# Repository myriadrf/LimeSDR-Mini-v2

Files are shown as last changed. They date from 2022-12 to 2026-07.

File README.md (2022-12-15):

# LimeSDR Mini v2

LimeSDR Mini 2.0 is an upgraded, drop-in replacement for LimeSDR Mini, a hardware platform for developing and prototyping high-performance and logic-intensive digital and RF designs that use an FPGA coupled with Lime Microsystems’ LMS7002M RF transceiver.

## Contents

The directory structure is as follows:

      hardware/<version>/
          OutputJobs/            - Output jobs
          PCB/                   - PCB design
          Project Outputs/       - BOM, rule check reports, Gerbers, pick & place files, PDFs
          Schematics/            - Schematic diagrams

## Licensing

The hardware designs are licensed under the Solderpad Hardware License v2.1.

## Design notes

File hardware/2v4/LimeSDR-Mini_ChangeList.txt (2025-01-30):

Changes:

LimeSDR-Mini_2v4_DB_DFMr0:
 - HW_VER changed to 7;
 - Changed VREF source to shunt type
 - LMZ10501 and passive components changed to LMZ20501SILR (same as LimeSDR-Mini_2v2)
 - Fresh DFM files generated

LimeSDR-Mini_2v3_DB_DFMr0:
 - HW_VER changed to 6;
 - Added analog MUX 74LVC1G3157FZ4 for clock source selection
 - LMS_TXNRX2 disconnected from FPGA B6 pin
 - FPGA B6 pin connected to analog mux control CLK_SEL line
 - Switching regulators reverted to LMZ10501 (as in 2v1) due to customer stock
 - Fresh DFM files generated

LimeSDR-Mini_2v2_DB_DFMr1:
 - R71 and R72 moved from mounting hole. 4mm radius of free area is now available from the center of the mounting hole. Only bottom layer contains electrical changes.
 - Assembly top and bottom mechanical layers updated, as well as Mechanical 1 layer.
 - All DFM files generated except BOM, which only changed name from r0 to r1 to correspond the revision.

LimeSDR-Mini_2v2_DB_DFMr0:
 - Older version used as initial version for this revision: LimeSDR-Mini_2v1_DB_DFMr1
 - LMZ10501 and passive components changed to LMZ20501SILR
 - HW version changed to v5
 - PCB changed only in the latter DC-DC converter region only on top layer. Holes are left in the same places
 
 LimeSDR_Mini_2v0:
 - New sheet with RF diagram.
 - Updated diagrams.
 - LMS EEPROM made NF.
 - Changed RF MOSFETs (RF shunt and attenuator).
 - Connected LMS Channel 2 RXes to GND.
 - Connected Edge GPIO pin 5 to VCC5P0 instead of VCC1P8.
 - Changed FPGA from Intel 10M16SAU169C8G to Lattice LFE5U-45F-MG285.
 - Removed 10 pin 0.05" JTAG (Only Edge JTAG left).
 - HW_VER changed to 3.
 - Removed parallel termination resistors (NF) for FT_CLK line.
 - LM75 temperature sensor fit.
 - FPGA I2C EEPROM NF.
 - Added Multi-footprint (SO08N/SO08W/DFN8) FPGA configuration FLASH.
 - Removed angle LED and added TX and RX LEDs. FPGA_GPIO[7:4] are shared with TX and RX LEDs, ca be disconnected by clearing solder bridges JMP1-4.
 - Changed XO from RTX5032A to E7355LF.
 - XO DAC changed from 8 to 10 bit (from DAC5311IDCKR to DAC6311IDCK.
 - Added 16 bit XO VC DAC (NF) and 2,5V reference for XO DAC (NF).
 - Changed clock buffer CLKout2-4 Vddo to 3.3V and optimized power decoupling capacitors.
 - Added new regulator for FPGA core (1.1V).
 - VCC3P3 regulator's EN connected to VCC1P1 PG pin (power sequence).
 - Other cosmetic  changes (sheet orientation, revision, etc).
 - PCB fabrication requirements under FPGA increased: minimal copper width/spacing 3 mil (0.0762 mm), vias under FPGA reduced to 0.3mm ring/0.15mm via. Fabrication requirements for the rest of the PCB left unchanged (copper width/spacing 4mil or 0.1mm; vias 0.4mm ring and 0.2mm hole)
 - Mounting hole added on the SMA connector side
 
LimeSDR_Mini_1v3:
 - Initial version from LimeSDR_Mini_1v2_DB_DFMr2
 - 1.8V and 3.3V rail LDOs changed
 - Capacitors C194 and C195 added for LMS power
 - HW version changed (affects only PCB physical pin connection)
 - BOM version changed (R44 is now fit)
 - Layout improvements (FT connection)

LimeSDR_Mini_1v2_DB_DFMr2:
 - R44 made NF (BOM version)
 - LimeSDR_Mini_1v2_schematic_r2.PDF generated
 - LimeSDR_Mini_1v2_BOMr2.xls updated

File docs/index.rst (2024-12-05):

.. toctree::
   :maxdepth: 2
   :hidden:

   Introduction <self>
   v2.2/index
   v2.3/index
   v2.4/index
   documentation/jtag-programming
   documentation/faq

LimeSDR Mini Boards
===================

LimeSDR Mini is low-cost software defined radio board. LimeSDR Mini development board provides a hardware platform for developing and prototyping high-performance and logic-intensive digital and RF designs based on Lattice Semiconductor’s ECP5 FPGA and Lime Microsystems transceiver.

.. tab:: LimeSDR Mini v2.2

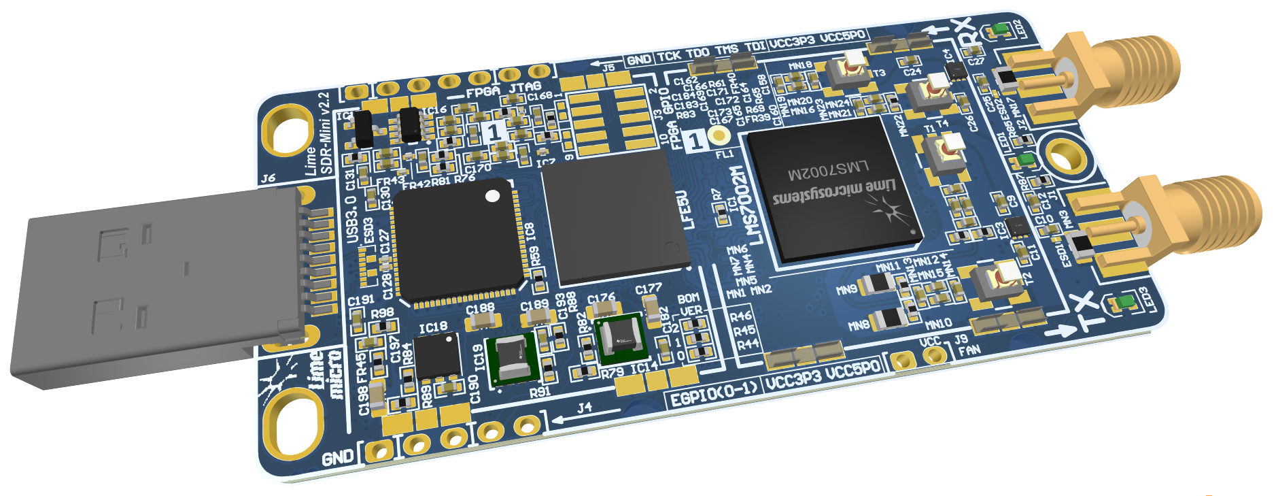
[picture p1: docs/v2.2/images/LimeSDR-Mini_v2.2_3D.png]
   

      Figure 1: LimeSDR Mini v2.2 board

.. tab:: LimeSDR Mini v2.3

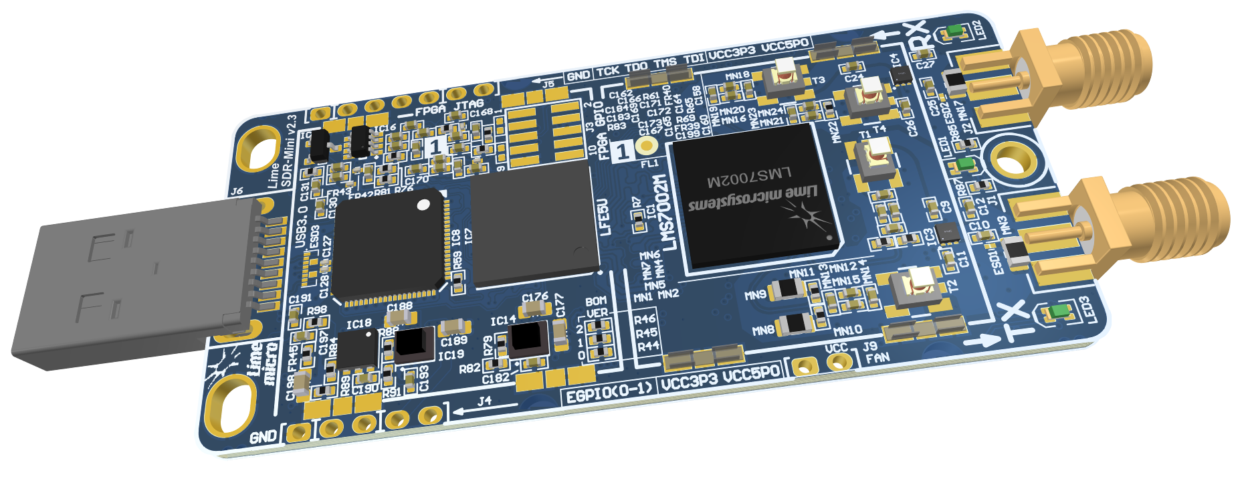
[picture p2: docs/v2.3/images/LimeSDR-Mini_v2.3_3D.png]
   

      Figure 1: LimeSDR Mini v2.3 board

.. tab:: LimeSDR Mini v2.4

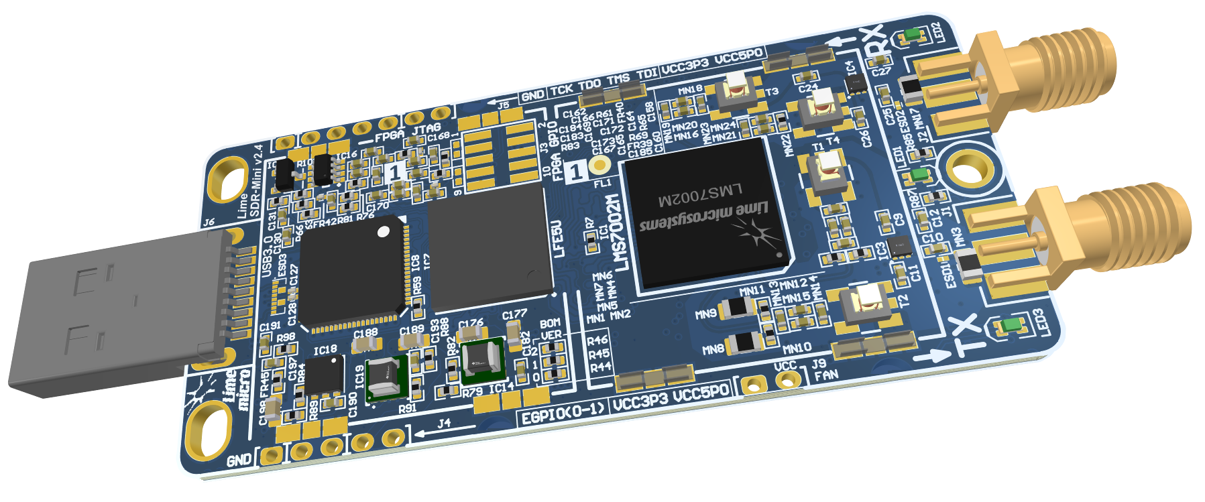
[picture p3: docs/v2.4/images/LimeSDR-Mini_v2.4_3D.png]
   

      Figure 1: LimeSDR Mini v2.4 board

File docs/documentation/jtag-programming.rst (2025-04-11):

.. _target3:

JTAG Programming
================

This section describes how to program the Lattice LFE5U FPGA used on the LimeSDR Mini v2 board using JTAG interface, FT2232H Mini Module and Lattice software.

Used software
-------------

List of used software is given in Table 1.

.. table:: Table 1. Required software and tools

  +------------------------------------------------------------------------------------------------------------------------------------------------+-------------------------------+------------------------------------------------------------------------------------+
  | **Tool**                                                                                                                                       | **Version**                   | **Comment**                                                                        |
  +================================================================================================================================================+===============================+====================================================================================+
  | `Lattice Diamond Programmer 3.12 SP1 <https://www.latticesemi.com/view_document?document_id=53375>`__                                          | 3.12 SP1                      | Standalone programing software for 64-bit Windows OS. Also available for Linux OS. |
  +------------------------------------------------------------------------------------------------------------------------------------------------+-------------------------------+------------------------------------------------------------------------------------+
  | `Lattice Diamond 3.12 <https://www.latticesemi.com/latticediamond>`__                                                                          | Production Build 3.12.0.240.2 | FPGA design and programming software                                               |
  +------------------------------------------------------------------------------------------------------------------------------------------------+-------------------------------+------------------------------------------------------------------------------------+
  | `Lattice Diamond 3.12 SP1 <https://www.latticesemi.com/latticediamond>`__                                                                      | Build 3.12.1.454.2            | Update for Lattice Diamond (Optional)                                              |
  +------------------------------------------------------------------------------------------------------------------------------------------------+-------------------------------+------------------------------------------------------------------------------------+
  | `LatticeMico System for Diamond 3.12 <https://www.latticesemi.com/en/Products/DesignSoftwareAndIP/EmbeddedDesignSoftware/LatticeMicoSystem>`__ | 1.1                           | Mico32 CPU integration tool (Optional)                                             |
  +------------------------------------------------------------------------------------------------------------------------------------------------+-------------------------------+------------------------------------------------------------------------------------+

Connecting LimeSDR Mini v2 board to FT2232H Mini Module
-------------------------------------------------------

FTDI FT2232H Mini Module is available for approximately $20 from distributors like Digi-Key and Mouser, and it can be used directly as a programming adapter for Lattice devices (and others) by following the setup described below. JTAG is a 4-wire protocol defined by the IEEE (Std 1149.1-2013). The signals that comprise the Test Access Port (TAP) are TCK, TMS, TDI, and TDO. The FT2232H is a two port bridge device and either port can be used for JTAG. Our configuration makes use of bus/port A (0).

FT2232H Mini Module preparation:

* Connect CN3-1 to CN3-3, which connects USB VBUS to VCC (voltage regulator input). This can be done using jumper.
* Connect LimeSDR Mini v2 to FT2232H Mini module as specified in Table 2 (see Figure 1 for graphical representation).

.. table:: Table 2. LimeSDR Mini board and FT2232H Mini module connections

  +------------------------------------+---------------------------------+
  | **LimeSDR Mini v2**                | **FT2232H Mini module**         |
  +====================================+=================================+
  | J5-1 (GND)                         | CN2-2 (GND)                     |
  +------------------------------------+---------------------------------+
  | J5-2 (FPGA_JTAG_TCK)               | CN2-7 (AD0)                     |
  +------------------------------------+---------------------------------+
  | J5-3 (FPGA_JTAG_TDO)               | CN2-9 (AD2)                     |
  +------------------------------------+---------------------------------+
  | J5-4 (FPGA_JTAG_TMS)               | CN2-12 (AD3)                    |
  +------------------------------------+---------------------------------+
  | J5-5 (FPGA_JTAG_TDI)               | CN2-10 (AD1)                    |
  +------------------------------------+---------------------------------+
  | J5-6 (VCC3P3)                      | CN2-11 (VIO)                    |
  +------------------------------------+---------------------------------+

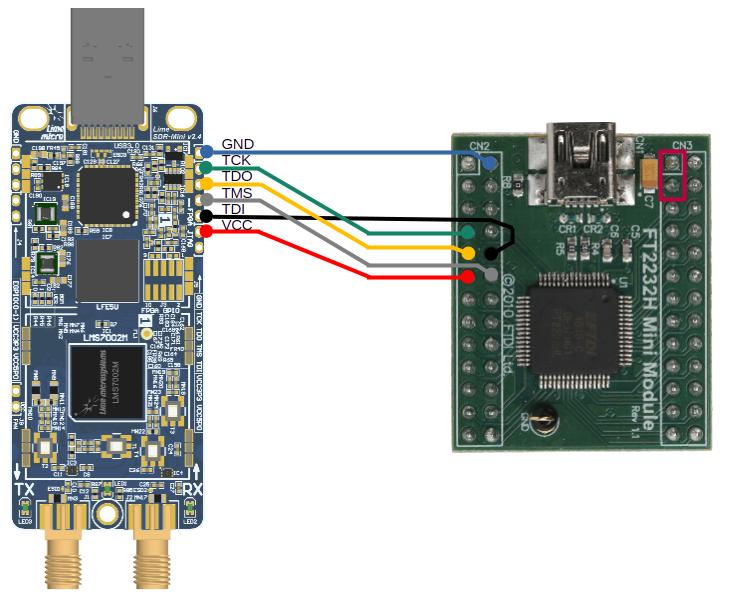
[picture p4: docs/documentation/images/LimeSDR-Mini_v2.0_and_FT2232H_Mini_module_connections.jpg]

  
  Figure 1: LimeSDR Mini v2 board and FT2232H Mini module connections

FPGA programming using Lattice Diamond Programmer software
----------------------------------------------------------

Creating a new project
~~~~~~~~~~~~~~~~~~~~~~

Connect LimesdSDR Mini v2 board to FTDI FT2232H Mini Module as described in paragraph above and connect them to PC via USB ports. Launch software "Lattice Diamond Programmer". Cable HW-USBN-2B (FTDI) and port FTUSB-0 must be selected, as shown in Figure 2.

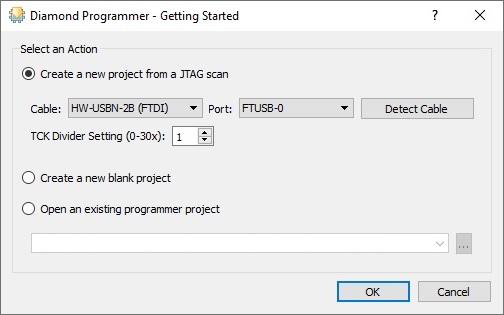
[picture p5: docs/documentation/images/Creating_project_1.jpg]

  
  Figure 2: Cable and port selection

Select an action "Create a new project from JTAG scan" and press "OK" button. Device database loading and JTAG scanning procedures will start, as shown in Figure 3.

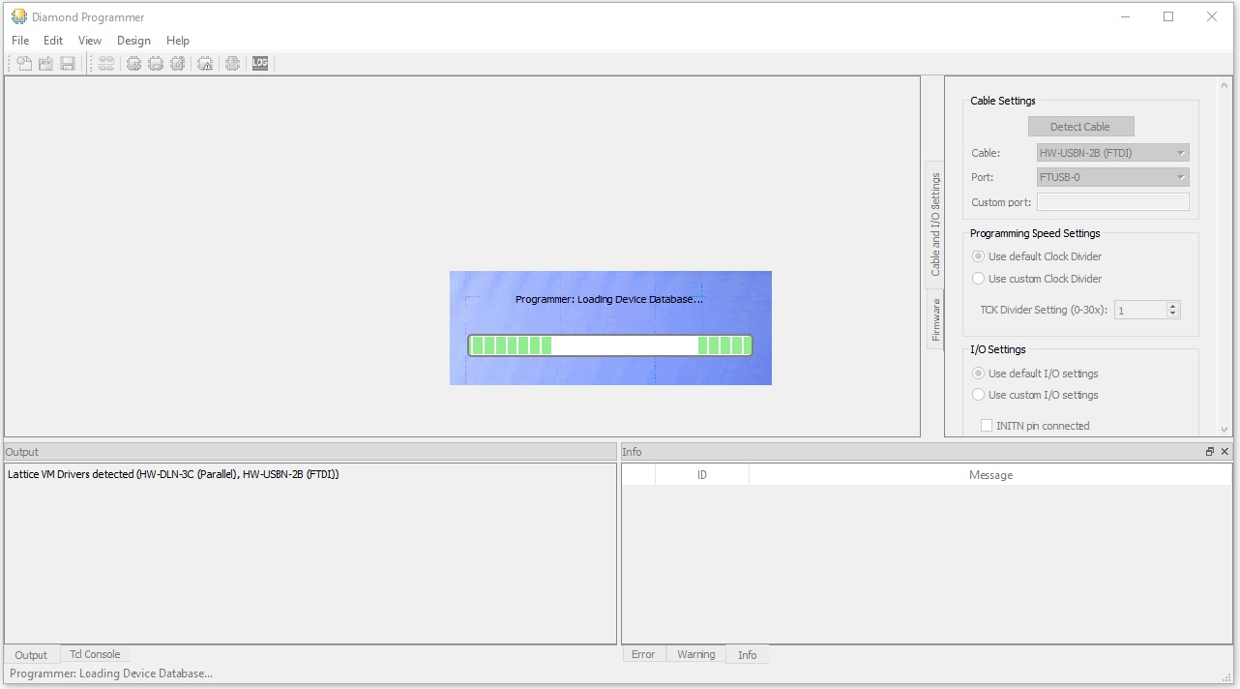
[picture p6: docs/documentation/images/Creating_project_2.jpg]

  
  Figure 3: Device database loading and JTAG scanning procedure

After successful JTAG chain scan ECP5U family FPGA device will be detected (in this case LFE5U-45F), as shown in Figure 4.

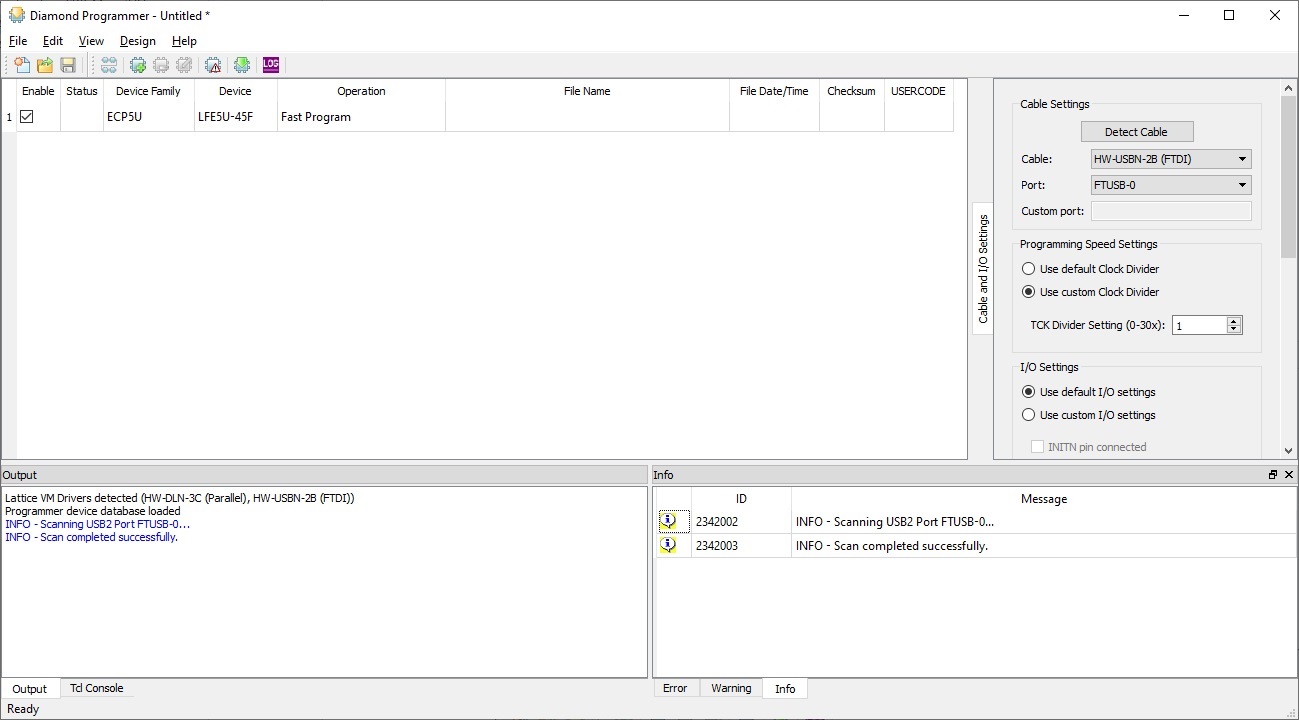
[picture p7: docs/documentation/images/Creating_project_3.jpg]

  
  Figure 4: Detected FPGA device

RAM programming
~~~~~~~~~~~~~~~

In context menu press "Edit -> Device properties" and set device operation parameters as shown in Figure 5. Also load appropriate programming file (gateware, bitstream) and then press "OK".

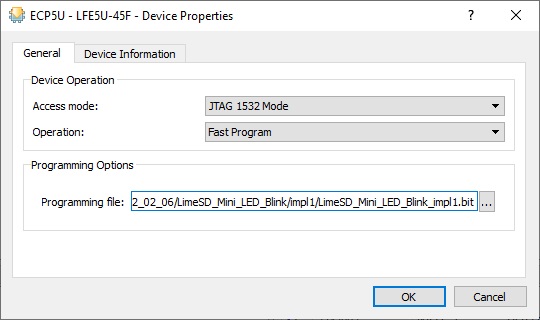
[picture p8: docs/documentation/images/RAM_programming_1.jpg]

  
  Figure 5: Device operation parameters and programming file

The main program window should look as shown in Figure 6.

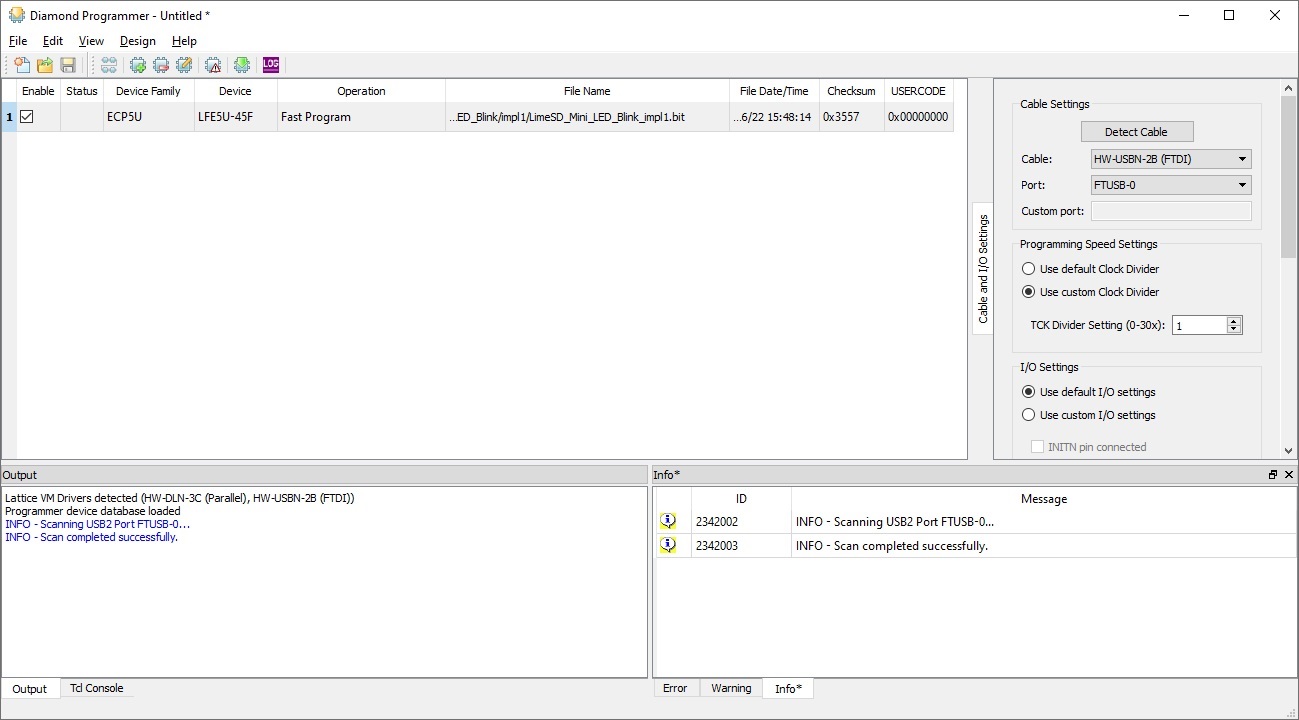
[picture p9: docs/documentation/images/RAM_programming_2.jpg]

  
  Figure 6: Main program window

In context menu press "Design -> Program" and RAM programming procedure will start, as shown in Figure 7.

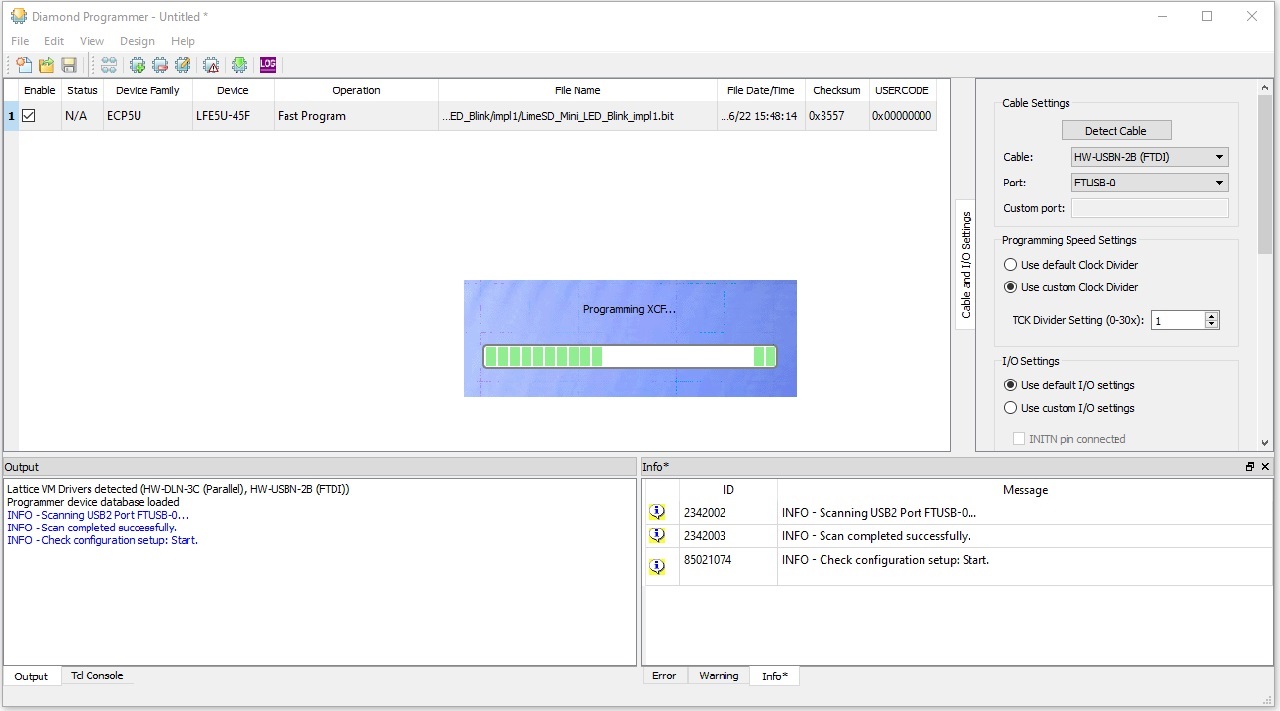
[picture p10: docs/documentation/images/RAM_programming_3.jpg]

  
  Figure 7: Programming procedure

After successful programming operation "Status" field will change to "PASS" highlihted in green as shown in Figure 8 and FPGA will start execution of a new gateware.

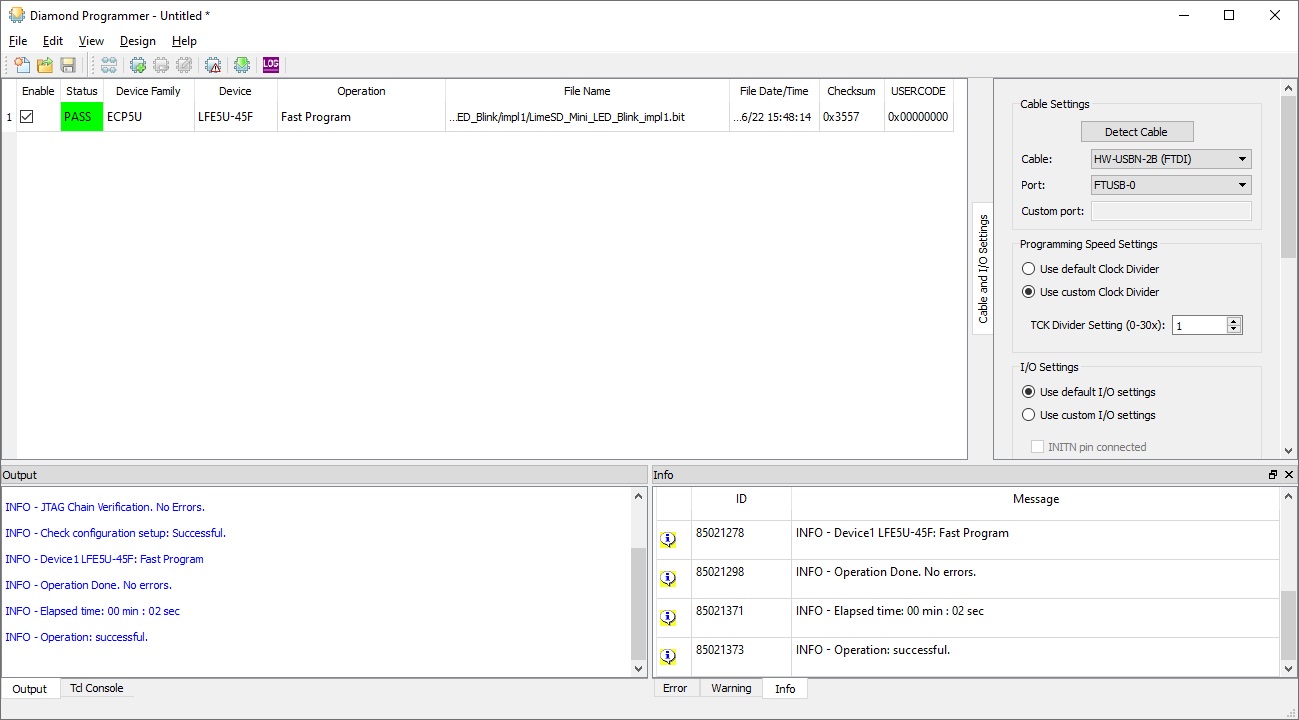
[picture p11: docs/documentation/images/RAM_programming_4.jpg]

  
  Figure 8: Successful programming result

Flash programming
~~~~~~~~~~~~~~~~~

**IMPORTANT!** Backgroud programming has to be enabled first by programming `lms7_trx_preflash_gw.bit <https://github.com/myriadrf/LimeSDR-Mini-v2_GW/blob/main/LimeSDR-Mini_bitstreams/lms7_trx_preflash_gw.bit>`__ file with "RAM programing" procedure.

In context menu press "Edit -> Device properties" and in section "Device Operation" set "Access mode" to "SPI Flash Background Programming" and "Operation" to "SPI Flash Erase,Program,Verify".

Load appropriate programming file (gateware, bitstream) and set the remaining parameters for Winbond W25Q128JV flash memory as shown in the image below and then press "OK".

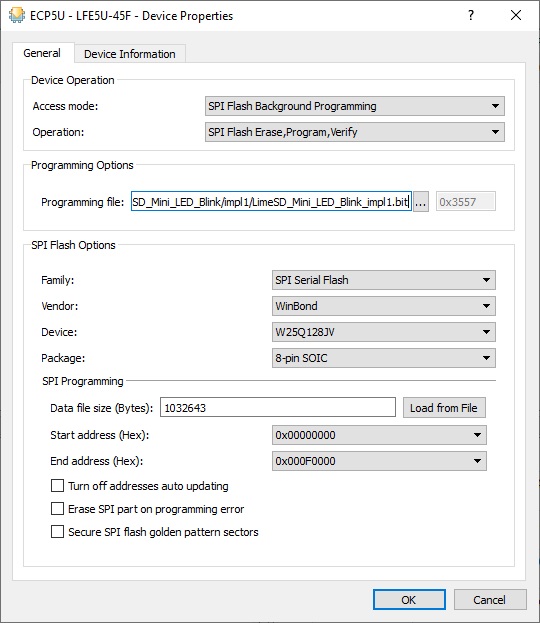
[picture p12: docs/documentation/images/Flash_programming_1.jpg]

  
  Figure 8: LimeSDR Mini v2 board and FT2232H Mini module connections

The main program window should look like shown in figure 9.

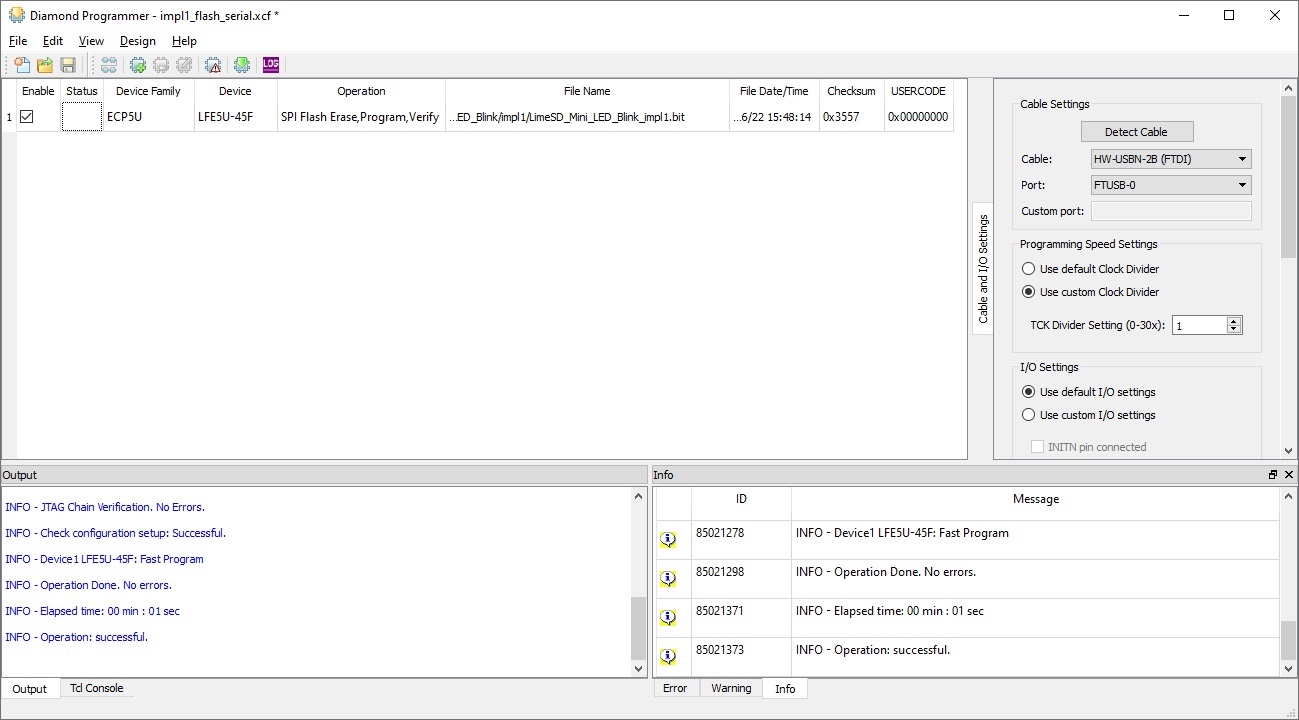
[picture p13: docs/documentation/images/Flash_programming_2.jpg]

  
  Figure 9: Main program window

In context menu press "Design -> Program" and Flash programming procedure will start, as shown in Figure 10.

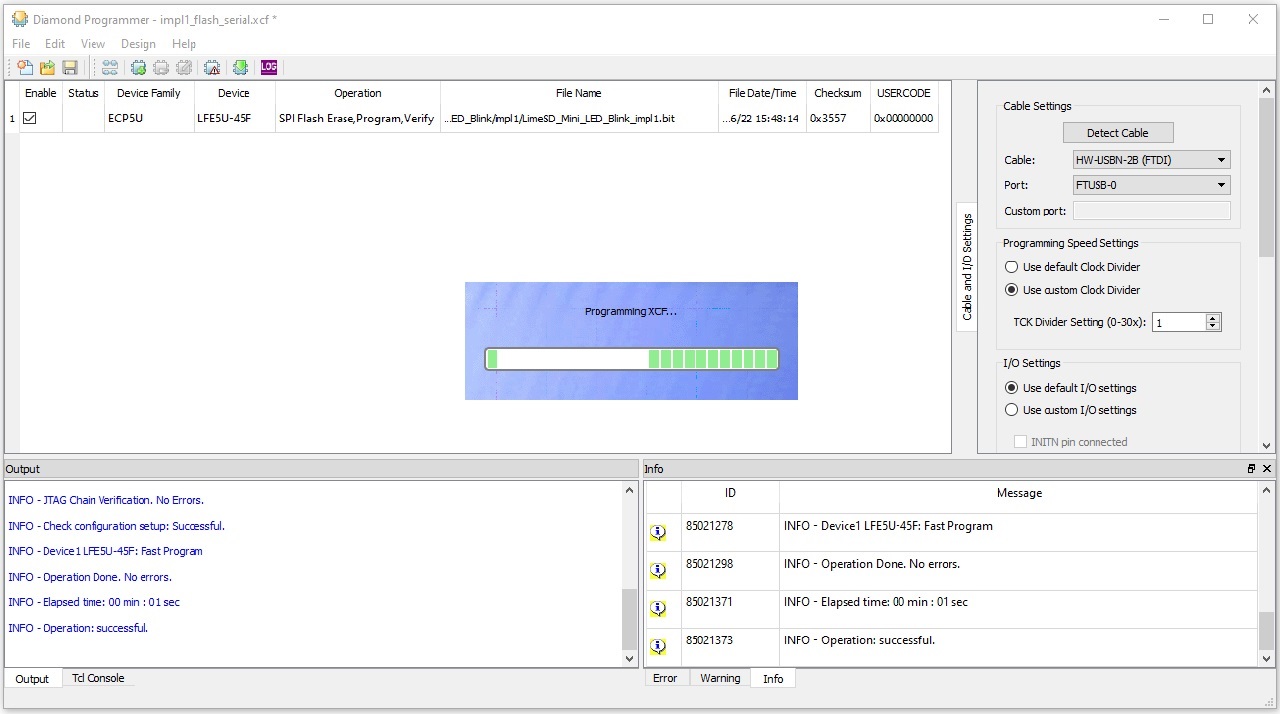
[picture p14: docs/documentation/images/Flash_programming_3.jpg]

  
  Figure 10: Flash in progress

After successful programming operation "Status" field will change to "PASS" highlihted in green as shown in Figure 11 and FPGA will start execution of a new gateware.

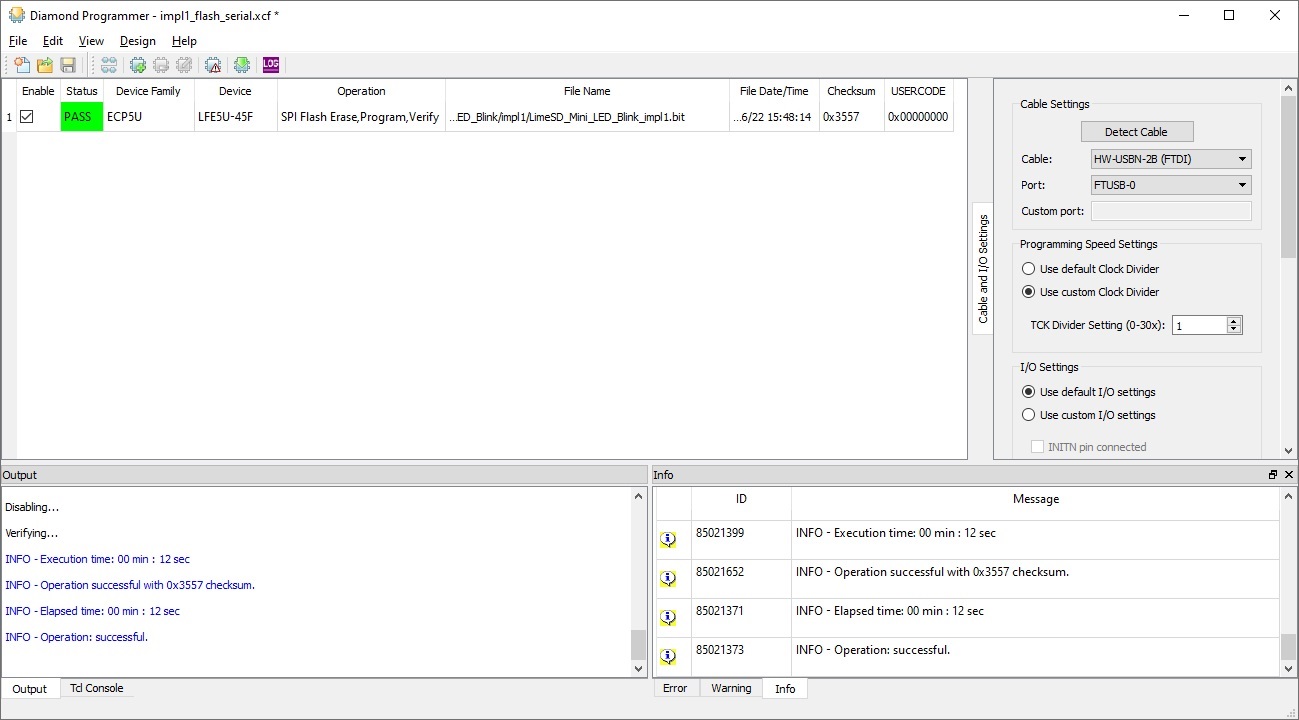
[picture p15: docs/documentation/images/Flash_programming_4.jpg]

  
  Figure 11: Successful programming

You can now save project for future use by selecting menu item "File -> Save".

FPGA programming using Lattice Diamond software
-----------------------------------------------

Open .ldf project File->Open->Project...

**FPGA SRAM programming**

* Open programmer setup file: ./LimeSDR-Mini_bitstreams/impl1_sram.xcf
* Select .bit file : ./LimeSDR-Mini_bitstreams/lms7_trx_impl1.bit
* Click Program.
* You should see blinking LED1 in green colour. 

**FPGA FLASH programming**

First program bitstream file to enable background programming:

* Open programmer setup file: ./LimeSDR-Mini_bitstreams/impl1_sram.xcf
* Select .bit file : ./LimeSDR-Mini_bitstreams/lms7_trx_preflash_gw.bit
* Click Program

Program Flash:

* Open programmer setup file: ./LimeSDR-Mini_bitstreams/impl1_flash_dualboot.xcf
* Select .mcs file : ./LimeSDR-Mini_bitstreams/lms7_trx_impl1_dualboot.mcs
* Click Program
* You should see blinking LED after reapplying power to board

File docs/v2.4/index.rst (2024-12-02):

***********************
LimeSDR Mini v2.4 Board
***********************

Introduction
============

LimeSDR Mini v2.4 Board Key Features
------------------------------------

The LimeSDR-Mini is low-cost software defined radio board. LimeSDR-Mini development board provides a hardware platform for developing and prototyping high-performance and logic-intensive digital and RF designs based on Lattice Semiconductor’s ECP5 FPGA and Lime Microsystems transceiver. 

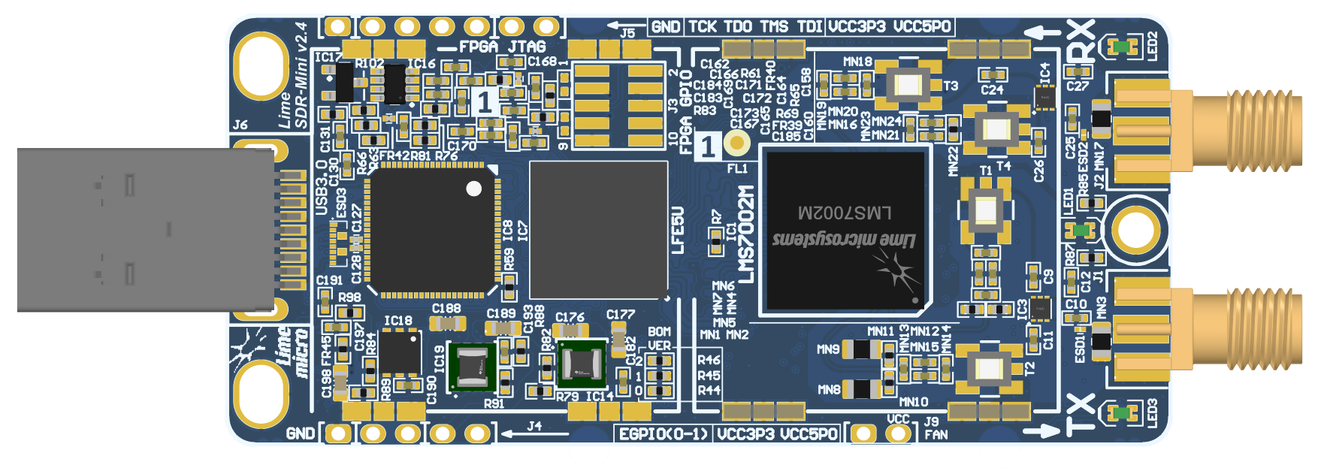
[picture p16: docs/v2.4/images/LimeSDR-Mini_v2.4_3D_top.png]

  
  Figure 1: LimeSDR Mini v2.4 board top view

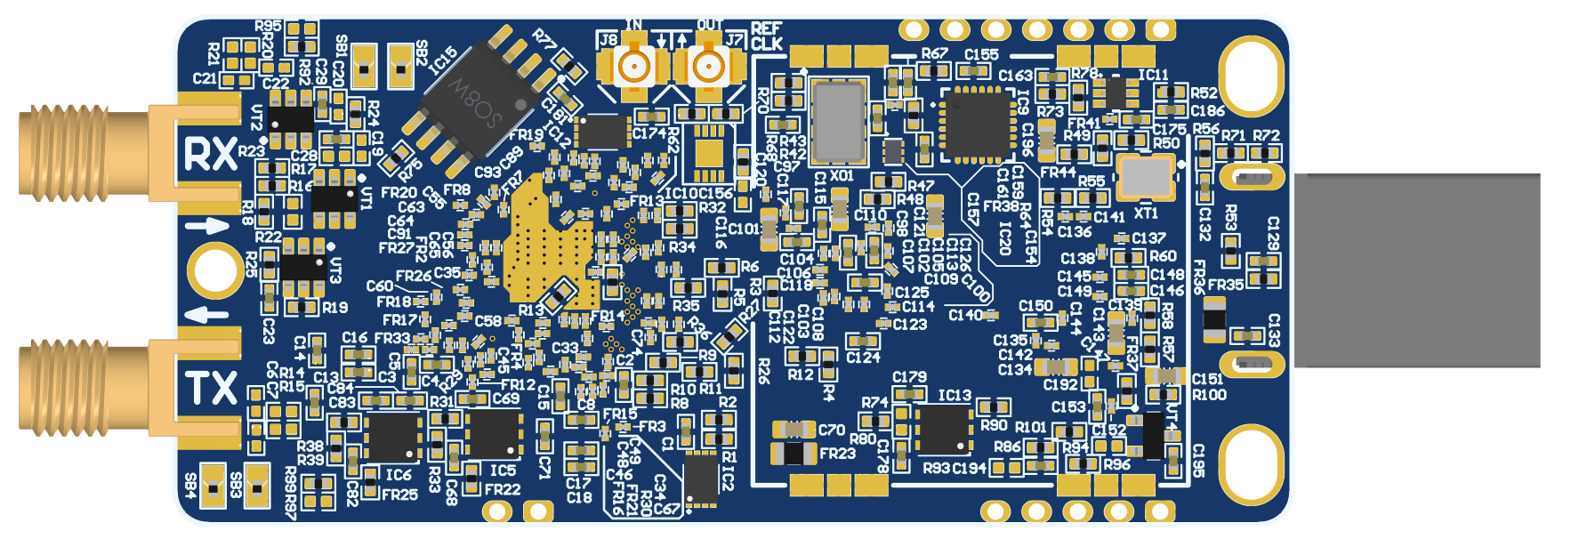
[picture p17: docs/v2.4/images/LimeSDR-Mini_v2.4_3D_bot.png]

  
  Figure 2: LimeSDR Mini v2.4 board bottom view

LimeSDR Mini board features:

* RF and BB parameters:

  * Configuration: SISO (1x TX, 1x RX)
  * Frequency range: 10 MHz – 3.5 GHz
  * Bandwidth: 30.72 MHz
  * Sample depth: 12 bit
  * Sample rate: 30.72 MSPS
  * Transmit power: max 10 dBm (depending on frequency)

* USB 3.0 controller: FTDI FT601

* FPGA: board is designed for Lattice ECP5 family LFE5U-25F/LFE5U-45F/LFE5U-85F FPGAs in 285-ball csfBGA package. By default board is assembled with LFE5U-45F-MG285 FPGA. Lattice ECP5 LFE5U-45F features:

  * 285-pin csfBGA package (10 x 10 mm, 0.5 mm)
  * 44 K LUTs logic capacity
  * 108 sysMEM Blocks (18 Kb)
  * 1944 Kb Embedded Memory
  * 351 Kb distributed RAM
  * 72x 18x18-bit multipliers
  * 4x PLLs and 4x DLLs
  * 118 IOs
  * FPGA configuration via JTAG

* RF transceiver: Lime Microsystems LMS7002M

* EEPROM Memory: 2x 128Kb EEPROMs for LMS MCU firmware and FPGA data (optional)

* FLASH Memory: 128Mb Flash memory for FPGA configuration

* Temperature sensor: LM75

* General user inputs/outputs:

  * 3x Dual colour (RG) LEDs
  * 8x + 2x FPGA GPIO pinheaders (3.3V) (optional)

* Connections:

  * USB 3.0 (type A) plug
  * Coaxial RF (SMA female) connectors
  * FPGA GPIO headers (unpopulated)
  * FPGA JTAG connector (unpopulated)
  * FAN (5V default or 3.3V) connector

* Clock system:

  * 40.00MHz on board VCTCXO
  * VCTCXO can be tuned by onboard DAC
  * Reference clock input and output connectors (U.FL)
  * Analog switch for clock source selection

* Board size: 69mm x 31.4mm

* Board power source: USB connector (5V)

For more information on the following topics, refer to the corresponding documents:

* `FTDI FT601 USB 3.0 to FIFO Bridge datasheet <https://ftdichip.com/wp-content/uploads/2020/07/DS_FT600Q-FT601Q-IC-Datasheet.pdf>`_
* `Lattice ECP5 and ECP5-5G Family data sheet <https://www.latticesemi.com/view_document?document_id=50461>`_
* `Lime Microsystems LMS7002M transceiver datasheet <https://limemicro.com/silicon/lms7002m/>`_

Board Overview
--------------

The heart of the LimeSDR-Mini board is Lattice ECP5 (LFE5U-45F) FPGA. It’s main function is to transfer digital data between the PC through a USB 3.0 connector. The block diagram for LimeSDR-Mini board is presented in the Figure 3.

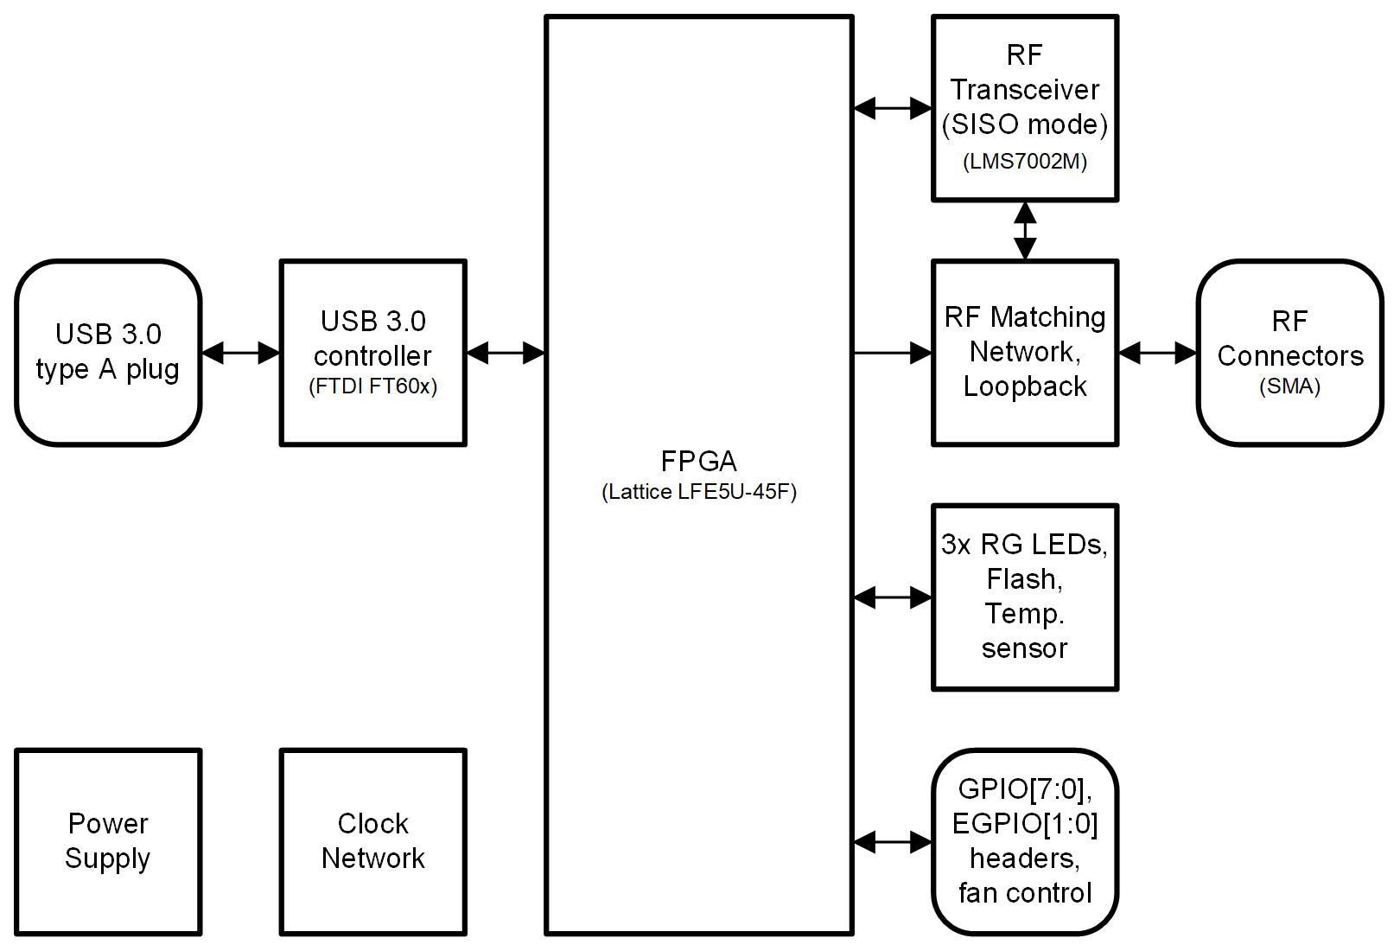
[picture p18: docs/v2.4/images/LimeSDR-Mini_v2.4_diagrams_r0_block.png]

  
  Figure 3: LimeSDR Mini v2.4 Development Board Block Diagram
  
This section contains component location description on the board. LimeSDR-Mini board picture with highlighted connectors and main components is presented in Figure 4 and Figure 5.

.. _target4:

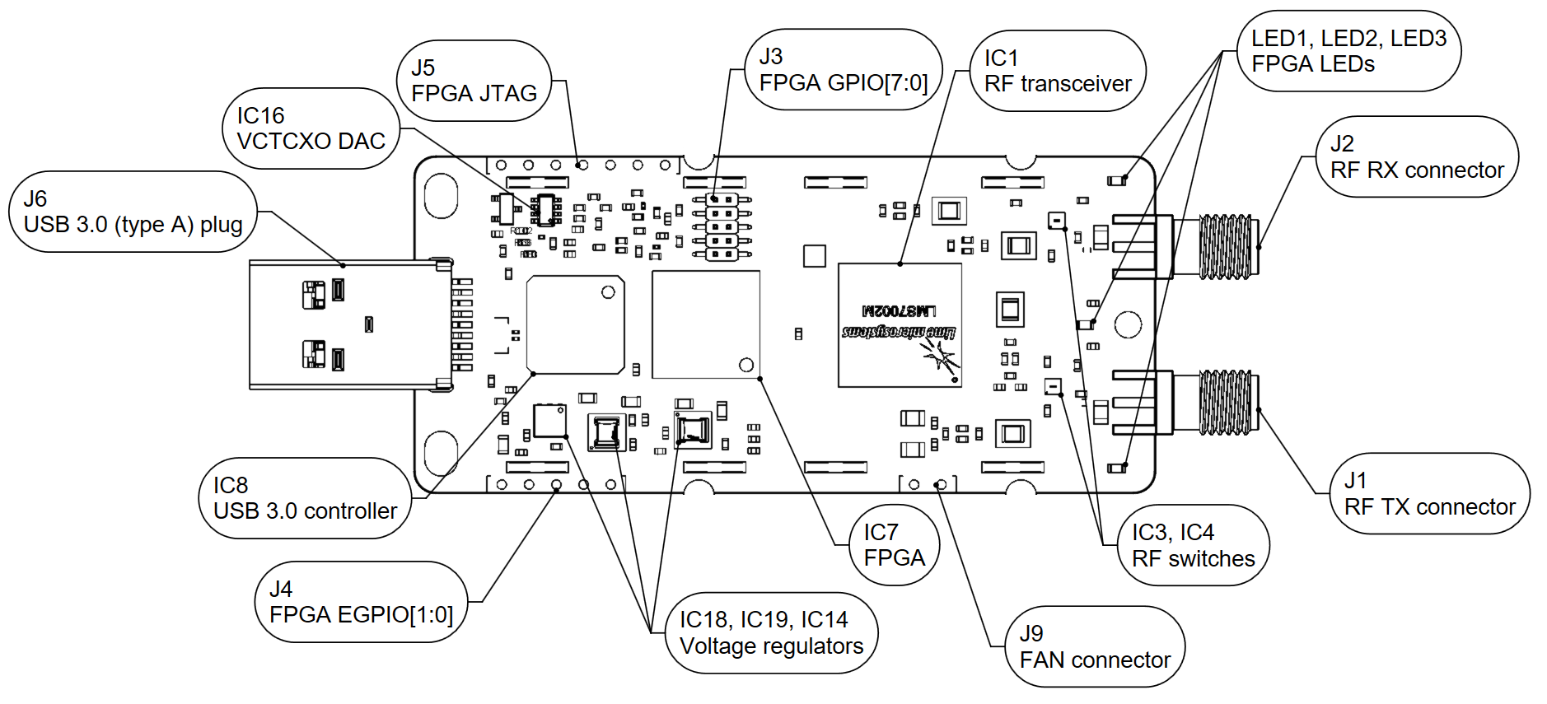
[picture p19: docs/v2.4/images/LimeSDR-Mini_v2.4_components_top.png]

  
  Figure 4: LimeSDR Mini v2.4 board top connectors and main components

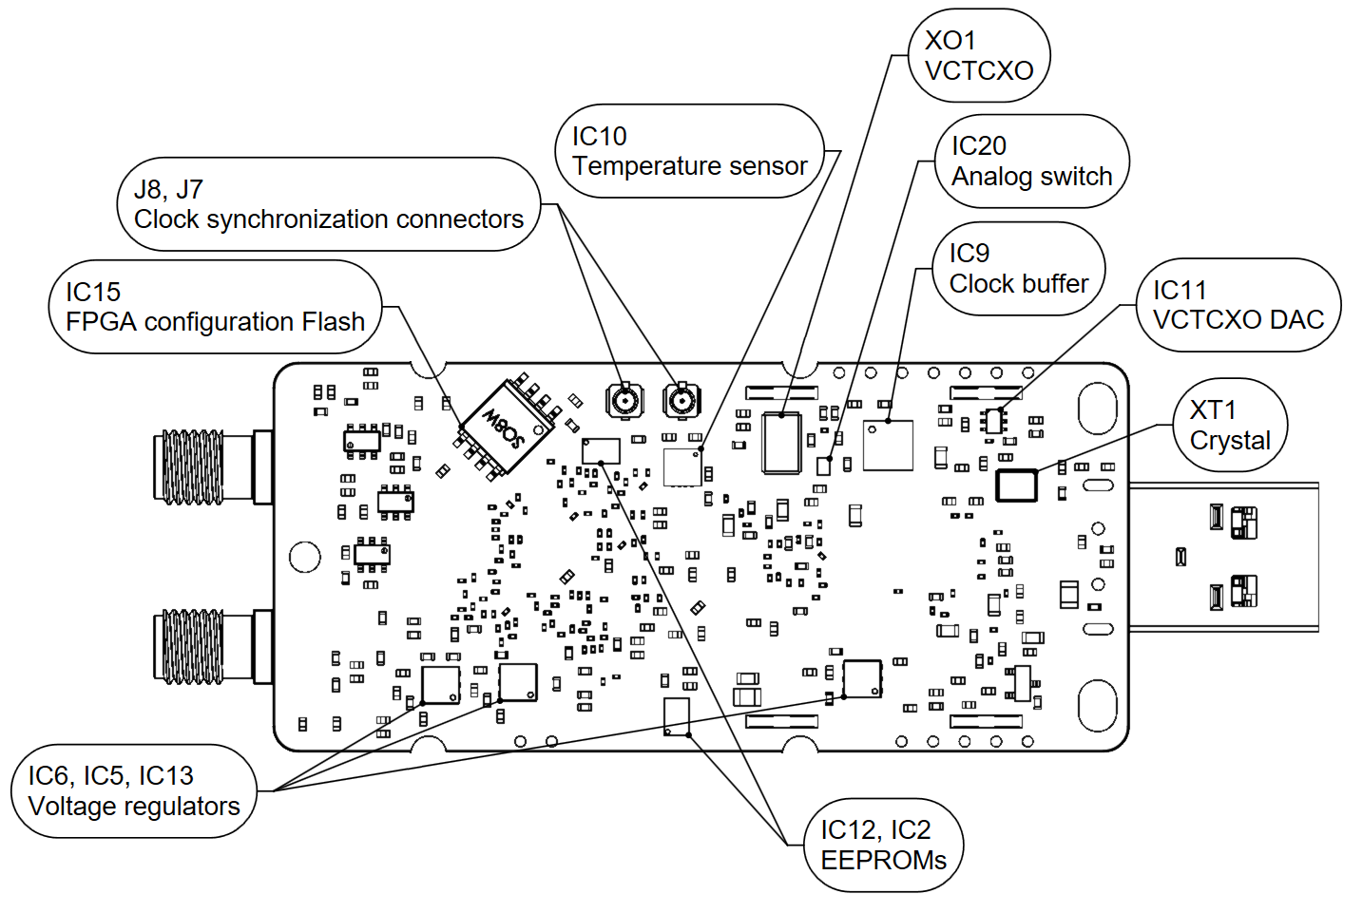
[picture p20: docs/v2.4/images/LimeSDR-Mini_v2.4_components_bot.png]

  
  Figure 5: LimeSDR Mini v2.4 board bottom connectors and main components

Description of board components is given in the Table 1.

.. table:: Table 1. Board components

   +---------------------------------------------------------------------------------------------------------------------------------------+
   | **Featured   Devices**                                                                                                                |
   +---------------------+-------------------------+---------------------------------------------------------------------------------------+
   | **Board Reference** | **Type**                | **Description**                                                                       |
   +---------------------+-------------------------+---------------------------------------------------------------------------------------+
   | IC1                 | RF transceiver          | Lime Microsystems   LMS7002M                                                          |
   +---------------------+-------------------------+---------------------------------------------------------------------------------------+
   | IC7                 | FPGA                    | Lattice   Semiconductor’s LFE5U (LFE5U-45F)                                           |
   +---------------------+-------------------------+---------------------------------------------------------------------------------------+
   | IC8                 | USB 3.0 microcontroller | FTDI USB 3.0 to FIFO interface bridge chip   FT601                                    |
   +---------------------+-------------------------+---------------------------------------------------------------------------------------+
   | **Miscellaneous   devices**                                                                                                           |
   +---------------------+-------------------------+---------------------------------------------------------------------------------------+
   | IC10                | IC                      | Temperature sensor LM75                                                               |
   +---------------------+-------------------------+---------------------------------------------------------------------------------------+
   | **Configuration,   Status and Setup Elements**                                                                                        |
   +---------------------+-------------------------+---------------------------------------------------------------------------------------+
   | J5                  | JTAG chain connector    | FPGA programming pin header on the board edge   for JTAG cable, 0.1” pitch            |
   +---------------------+-------------------------+---------------------------------------------------------------------------------------+
   | LED1, LED2, LED3    | Red-green status LEDs   | User defined FPGA indication LED.                                                     |
   +---------------------+-------------------------+---------------------------------------------------------------------------------------+
   | **General   User Input/Output**                                                                                                       |
   +---------------------+-------------------------+---------------------------------------------------------------------------------------+
   | J3                  | Pin header              | 8x FPGA GPIOs, 3.3V, 0.05” pitch                                                      |
   +---------------------+-------------------------+---------------------------------------------------------------------------------------+
   | J4                  | Pin header              | 2x FPGA GPIOs on the board edge, 3.3V, 0.1”   pitch                                   |
   +---------------------+-------------------------+---------------------------------------------------------------------------------------+
   | J9                  | Pin header              | 5V (3.3V voltage can be chosen by resistors)   fan connection pin headers, 0.1” pitch |
   +---------------------+-------------------------+---------------------------------------------------------------------------------------+
   | **Memory   Devices**                                                                                                                  |
   +---------------------+-------------------------+---------------------------------------------------------------------------------------+
   | IC2                 | IC                      | I²C EEPROM Memory 128Kb (16 x 8), connected   to RF transceiver I2C bus               |
   +---------------------+-------------------------+---------------------------------------------------------------------------------------+
   | IC12                | IC                      | I²C EEPROM Memory 128Kb (16K x 8), connected   to FPGA I2C bus                        |
   +---------------------+-------------------------+---------------------------------------------------------------------------------------+
   | IC15                | IC                      | Quad SPI Flash Memory 128 Mb (16M x 8)   connected to FPGA SPI                        |
   +---------------------+-------------------------+---------------------------------------------------------------------------------------+
   | **Communication   Ports**                                                                                                             |
   +---------------------+-------------------------+---------------------------------------------------------------------------------------+
   | J6                  | USB 3.0 connector       | USB 3.0 (type A) plug                                                                 |
   +---------------------+-------------------------+---------------------------------------------------------------------------------------+
   | **Clock   Circuitry**                                                                                                                 |
   +---------------------+-------------------------+---------------------------------------------------------------------------------------+
   | XO1                 | VCTCXO                  | 40.00 MHz Voltage Controlled Temperature   Compensated Crystal Oscillator             |
   +---------------------+-------------------------+---------------------------------------------------------------------------------------+
   | IC11                | IC                      | 10 bit DAC for TCXO (XT4) frequency tuning   (default)                                |
   +---------------------+-------------------------+---------------------------------------------------------------------------------------+
   | IC16                | IC                      | 16 bit DAC for TCXO (XT4) frequency tuning   (unpopulated)                            |
   +---------------------+-------------------------+---------------------------------------------------------------------------------------+
   | IC17                | IC                      | Voltage reference (unpopulated)                                                       |
   +---------------------+-------------------------+---------------------------------------------------------------------------------------+
   | IC9                 | IC                      | Clock buffer                                                                          |
   +---------------------+-------------------------+---------------------------------------------------------------------------------------+
   | IC20                | IC                      | Analog switch                                                                         |
   +---------------------+-------------------------+---------------------------------------------------------------------------------------+
   | J8                  | U.FL connector          | Reference clock input                                                                 |
   +---------------------+-------------------------+---------------------------------------------------------------------------------------+
   | J7                  | U.FL connector          | Reference clock output                                                                |
   +---------------------+-------------------------+---------------------------------------------------------------------------------------+
   | **Power   Supply**                                                                                                                    |
   +---------------------+-------------------------+---------------------------------------------------------------------------------------+
   | IC14                | IC                      | Switching regulator LMZ20501 (1.8V rail)                                              |
   +---------------------+-------------------------+---------------------------------------------------------------------------------------+
   | IC19                | IC                      | Switching regulator LMZ20501 (3.3V rail)                                              |
   +---------------------+-------------------------+---------------------------------------------------------------------------------------+
   | IC13                | IC                      | Linear regulator LD39100PUR (1.1V rail)                                               |
   +---------------------+-------------------------+---------------------------------------------------------------------------------------+
   | IC5                 | IC                      | Linear regulator LD39100PUR (1.25V rail)                                              |
   +---------------------+-------------------------+---------------------------------------------------------------------------------------+
   | IC6                 | IC                      | Linear regulator LD39100PUR (1.4V rail)                                               |
   +---------------------+-------------------------+---------------------------------------------------------------------------------------+
   | IC18                | IC                      | Linear regulator LD39100PUR (2.5V rail)                                               |
   +---------------------+-------------------------+---------------------------------------------------------------------------------------+
   
Board Description
=================

More detailed description of LimeSDR-Mini board components and interconnections is given in the sections of this chapter.

RF transceiver digital connectivity
-----------------------------------

The interface and control signals are described below:

* Digital Interface Signals: LENS7002 is using data bus LIMNS_DIQ1_D[11:0] and LMS_DIQ2_D[11:0], LMS_EN_IQSEL1 and LMS_EN_IQSEL2, LMS_FCLK1 and LMS_FCLK2, LMS_MCLK1 and LMS_MCLK2 signals to transfer data to/from FPGA. Indexes 1 and 2 indicate transceiver digital data PORT-1 or PORT-2. Any of these ports can be used to transmit or receive data. By default PORT-1 is selected as transmit port and PORT-2 is selected as receiver port. The FCLK# is input clock and MCLK# is output clock for LMS7002M transceiver. TXNRX signals sets ports directions. For LMS7002M interface timing details refer to `LMS7002M transceiver datasheet <https://limemicro.com/silicon/lms7002m/>`_ page 12-13.
* LMS Control Signals: these signals are used for optional functionality:

  * LMS_RXEN, LMS_TXEN – receiver and transmitter enable/disable signals connected to FPGA Bank 8 (VDIO_LMS_FPGA; 2.5V).
  * LMS_RESET – LMS7002M reset connected to FPGA Bank 3 (VDIO_LMS_FPGA; 2.5V).

* SPI Interface: LMS7002M transceiver is configured via 4-wire SPI interface; FPGA_SPI_SCLK, FPGA_SPI_MOSI, FPGA_SPI_MISO, FPGA_SPI_LMS_SS. The SPI interface controlled from FPGA Bank 3 (VDIO_LMS_FPGA; 2.5V). 
* LMS I2C Interface: can be used for LMS EEPROM content modifying or for debug purposes. The signals LMS_I2C_SCL, LMS_I2C_DATA connected to EEPROM.

.. table:: Table 2. RF transceiver (LMS7002) digital interface pins

   +--------------------+--------------------------+---------------------------+--------------+-----------------------+--------------------------------+
   | **Chip pin (IC1)** | **Chip reference (IC1)** | **Schematic signal name** | **FPGA pin** | **FPGA I/O standard** | **FPGA I/O standard**          |
   +--------------------+--------------------------+---------------------------+--------------+-----------------------+--------------------------------+
   | E5                 | xoscin_tx                | TxPLL_CLK                 |              |                       | Connected to   40.00 MHz clock |
   +--------------------+--------------------------+---------------------------+--------------+-----------------------+--------------------------------+
   | AB34               | MCLK1                    | LMS_MCLK1                 | H4           | 2.5V/3.3V             |                                |
   +--------------------+--------------------------+---------------------------+--------------+-----------------------+--------------------------------+
   | AA33               | FCLK1                    | LMS_FCLK1                 | H3           | 2.5V/3.3V             |                                |
   +--------------------+--------------------------+---------------------------+--------------+-----------------------+--------------------------------+
   | V32                | TXNRX1                   | LMS_TXNRX1                | F1           | 2.5V/3.3V             |                                |
   +--------------------+--------------------------+---------------------------+--------------+-----------------------+--------------------------------+
   | U29                | TXEN                     | LMS_TXEN                  | B7           | 2.5V/3.3V             |                                |
   +--------------------+--------------------------+---------------------------+--------------+-----------------------+--------------------------------+
   | 1Y32               | ENABLE_IQSEL1            | LMS_EN_IQSEL1             | F3           | 2.5V/3.3V             |                                |
   +--------------------+--------------------------+---------------------------+--------------+-----------------------+--------------------------------+
   | AG31               | DIQ1_D0                  | LMS_DIQ1_D0               | J2           | 2.5V/3.3V             |                                |
   +--------------------+--------------------------+---------------------------+--------------+-----------------------+--------------------------------+
   | AF30               | DIQ1_D1                  | LMS_DIQ1_D1               | L1           | 2.5V/3.3V             |                                |
   +--------------------+--------------------------+---------------------------+--------------+-----------------------+--------------------------------+
   | AF34               | DIQ1_D2                  | LMS_DIQ1_D2               | K1           | 2.5V/3.3V             |                                |
   +--------------------+--------------------------+---------------------------+--------------+-----------------------+--------------------------------+
   | AE31               | DIQ1_D3                  | LMS_DIQ1_D3               | K4           | 2.5V/3.3V             |                                |
   +--------------------+--------------------------+---------------------------+--------------+-----------------------+--------------------------------+
   | AD30               | DIQ1_D4                  | LMS_DIQ1_D4               | G3           | 2.5V/3.3V             |                                |
   +--------------------+--------------------------+---------------------------+--------------+-----------------------+--------------------------------+
   | AC29               | DIQ1_D5                  | LMS_DIQ1_D5               | F4           | 2.5V/3.3V             |                                |
   +--------------------+--------------------------+---------------------------+--------------+-----------------------+--------------------------------+
   | AE33               | DIQ1_D6                  | LMS_DIQ1_D6               | J1           | 2.5V/3.3V             |                                |
   +--------------------+--------------------------+---------------------------+--------------+-----------------------+--------------------------------+
   | AD32               | DIQ1_D7                  | LMS_DIQ1_D7               | H1           | 2.5V/3.3V             |                                |
   +--------------------+--------------------------+---------------------------+--------------+-----------------------+--------------------------------+
   | AC31               | DIQ1_D8                  | LMS_DIQ1_D8               | G4           | 2.5V/3.3V             |                                |
   +--------------------+--------------------------+---------------------------+--------------+-----------------------+--------------------------------+
   | AC33               | DIQ1_D9                  | LMS_DIQ1_D9               | F2           | 2.5V/3.3V             |                                |
   +--------------------+--------------------------+---------------------------+--------------+-----------------------+--------------------------------+
   | AB30               | DIQ1_D10                 | LMS_DIQ1_D10              | G1           | 2.5V/3.3V             |                                |
   +--------------------+--------------------------+---------------------------+--------------+-----------------------+--------------------------------+
   | AB32               | DIQ1_D11                 | LMS_DIQ1_D11              | H2           | 2.5V/3.3V             |                                |
   +--------------------+--------------------------+---------------------------+--------------+-----------------------+--------------------------------+
   | AM24               | xoscin_rx                | RxPLL_CLK                 |              |                       | Connected to   40.00 MHz clock |
   +--------------------+--------------------------+---------------------------+--------------+-----------------------+--------------------------------+
   | P34                | MCLK2                    | LMS_MCLK2                 | D2           | 2.5V/3.3V             |                                |
   +--------------------+--------------------------+---------------------------+--------------+-----------------------+--------------------------------+
   | R29                | FCLK2                    | LMS_FCLK2                 | D1           | 2.5V/3.3V             |                                |
   +--------------------+--------------------------+---------------------------+--------------+-----------------------+--------------------------------+
   | U31                | TXNRX2                   | LMS_TXNRX2                |              |                       |                                |
   +--------------------+--------------------------+---------------------------+--------------+-----------------------+--------------------------------+
   | V34                | RXEN                     | LMS_RXEN                  | D6           | 2.5V/3.3V             |                                |
   +--------------------+--------------------------+---------------------------+--------------+-----------------------+--------------------------------+
   | R33                | ENABLE_IQSEL2            | LMS_EN_IQSEL2             | C4           | 2.5V/3.3V             |                                |
   +--------------------+--------------------------+---------------------------+--------------+-----------------------+--------------------------------+
   | H30                | DIQ2_D0                  | LMS_DIQ2_D0               | A3           | 2.5V/3.3V             |                                |
   +--------------------+--------------------------+---------------------------+--------------+-----------------------+--------------------------------+
   | J31                | DIQ2_D1                  | LMS_DIQ2_D1               | C2           | 2.5V/3.3V             |                                |
   +--------------------+--------------------------+---------------------------+--------------+-----------------------+--------------------------------+
   | K30                | DIQ2_D2                  | LMS_DIQ2_D2               | A2           | 2.5V/3.3V             |                                |
   +--------------------+--------------------------+---------------------------+--------------+-----------------------+--------------------------------+
   | K32                | DIQ2_D3                  | LMS_DIQ2_D3               | B4           | 2.5V/3.3V             |                                |
   +--------------------+--------------------------+---------------------------+--------------+-----------------------+--------------------------------+
   | L31                | DIQ2_D4                  | LMS_DIQ2_D4               | C3           | 2.5V/3.3V             |                                |
   +--------------------+--------------------------+---------------------------+--------------+-----------------------+--------------------------------+
   | K34                | DIQ2_D5                  | LMS_DIQ2_D5               | B2           | 2.5V/3.3V             |                                |
   +--------------------+--------------------------+---------------------------+--------------+-----------------------+--------------------------------+
   | M30                | DIQ2_D6                  | LMS_DIQ2_D6               | D3           | 2.5V/3.3V             |                                |
   +--------------------+--------------------------+---------------------------+--------------+-----------------------+--------------------------------+
   | M32                | DIQ2_D7                  | LMS_DIQ2_D7               | B1           | 2.5V/3.3V             |                                |
   +--------------------+--------------------------+---------------------------+--------------+-----------------------+--------------------------------+
   | N31                | DIQ2_D8                  | LMS_DIQ2_D8               | A4           | 2.5V/3.3V             |                                |
   +--------------------+--------------------------+---------------------------+--------------+-----------------------+--------------------------------+
   | N33                | DIQ2_D9                  | LMS_DIQ2_D9               | C1           | 2.5V/3.3V             |                                |
   +--------------------+--------------------------+---------------------------+--------------+-----------------------+--------------------------------+
   | P30                | DIQ2_D10                 | LMS_DIQ2_D10              | C7           | 2.5V/3.3V             |                                |
   +--------------------+--------------------------+---------------------------+--------------+-----------------------+--------------------------------+
   | P32                | DIQ2_D11                 | LMS_DIQ2_D11              | A6           | 2.5V/3.3V             |                                |
   +--------------------+--------------------------+---------------------------+--------------+-----------------------+--------------------------------+
   | U33                | CORE_LDO_EN              | LMS_CORE_LDO_EN           | C6           | 2.5V/3.3V             |                                |
   +--------------------+--------------------------+---------------------------+--------------+-----------------------+--------------------------------+
   | E27                | RESET                    | LMS_RESET                 | A7           | 2.5V/3.3V             |                                |
   +--------------------+--------------------------+---------------------------+--------------+-----------------------+--------------------------------+
   | D28                | SEN                      | FPGA_SPI_LMS_SS           | N3           | 2.5V/3.3V             | SPI interface                  |
   +--------------------+--------------------------+---------------------------+--------------+-----------------------+--------------------------------+
   | C29                | SCLK                     | FPGA_SPI_SCLK             | M3           | 2.5V/3.3V             | SPI interface                  |
   +--------------------+--------------------------+---------------------------+--------------+-----------------------+--------------------------------+
   | F30                | SDIO                     | FPGA_SPI_MOSI             | L3           | 2.5V/3.3V             | SPI interface                  |
   +--------------------+--------------------------+---------------------------+--------------+-----------------------+--------------------------------+
   | F28                | SDO                      | FPGA_SPI_MISO             | K3           | 2.5V/3.3V             | SPI interface                  |
   +--------------------+--------------------------+---------------------------+--------------+-----------------------+--------------------------------+
   | D26                | SDA                      | LMS_I2C_SDA               |              |                       | Connected to   EEPROM          |
   +--------------------+--------------------------+---------------------------+--------------+-----------------------+--------------------------------+
   | C27                | SCL                      | LMS_I2C_SCL               |              |                       | Connected to   EEPROM          |
   +--------------------+--------------------------+---------------------------+--------------+-----------------------+--------------------------------+

RF path and control signals
---------------------------

LimeSDR-Mini RF path contains matching networks, RF switches, loopback variable attenuator and 2 SMA connectors (J1 - TX and J2 - RX) as shown in Figure 6.

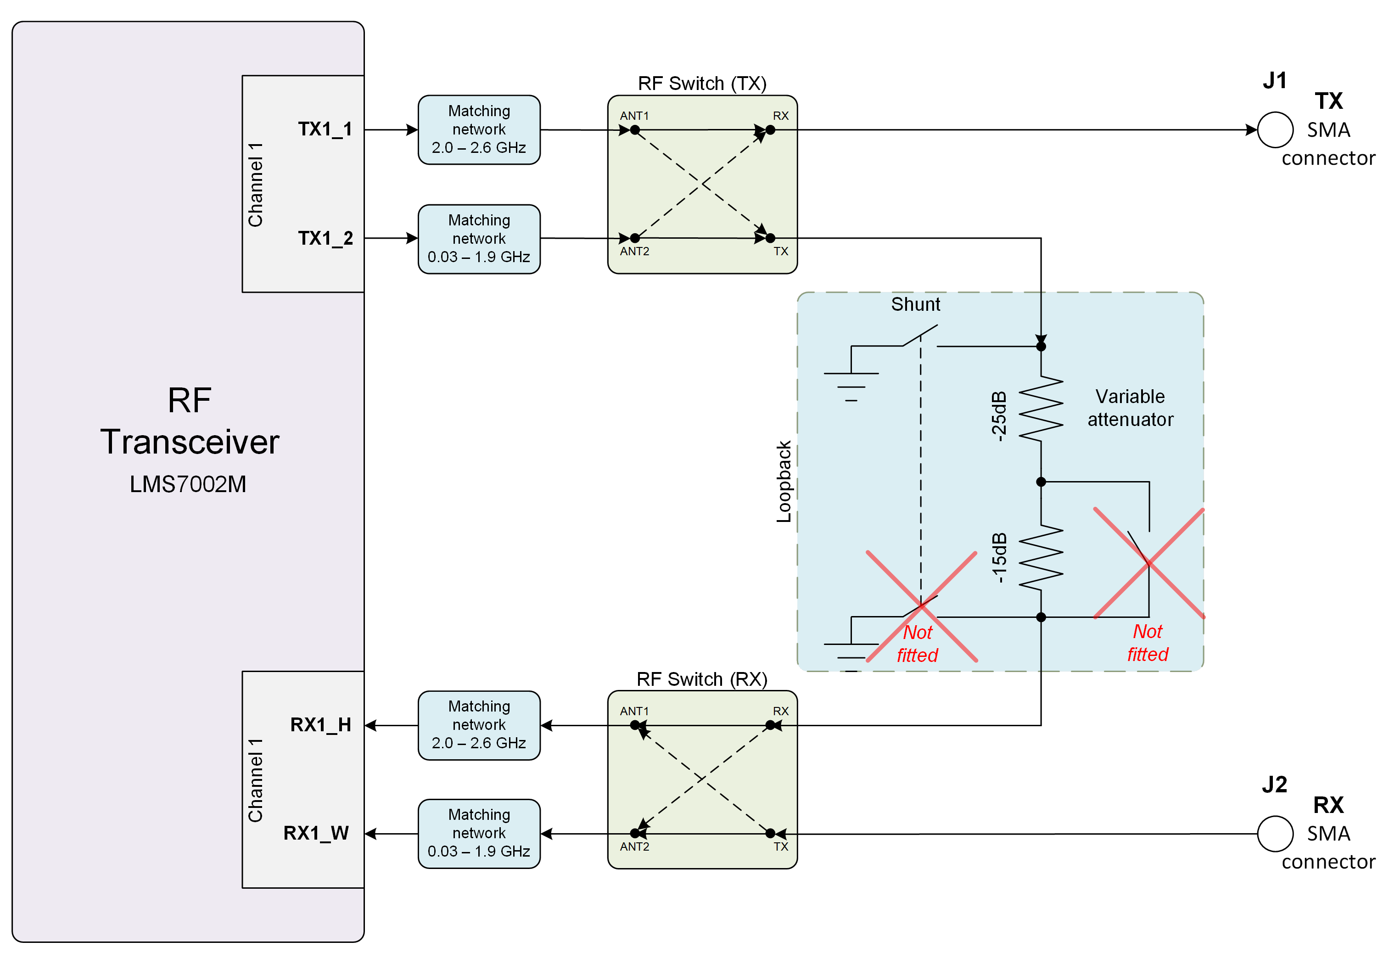
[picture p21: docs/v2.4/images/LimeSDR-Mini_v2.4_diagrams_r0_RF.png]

  
  Figure 6: LimeSDR Mini v2.4 RF diagram

RF transceiver TX and RX ports has its dedicated matching network which together determines the working frequency range. More detailed information about RF transceiver ports and matching network frequency ranges is listed in the Table 3.

.. table:: Table 3. RF transceiver ports and matching networks frequency ranges

  +-------------------------------+--------------------------------------+
  | **RF transceiver port**       | **Frequency range**                  |
  +===============================+======================================+
  | TX1_1                         | 2 GHz - 2.6 GHz                      |
  +-------------------------------+--------------------------------------+
  | TX1_2                         | 30 MHz - 1.9 GHz                     |
  +-------------------------------+--------------------------------------+
  | RX1_H                         | 2 GHz - 2.6 GHz                      |
  +-------------------------------+--------------------------------------+
  | RX1_W                         | 700 MHz - 900 MHz                    |
  +-------------------------------+--------------------------------------+

RF path control signals are described in the Table 4.

.. table:: Table 4. RF path control signals
  
  +------------------------+---------------------------+------------------+--------------+-------------------------------------------------------------------------------------------------+
  | **Component**          | **Schematic signal name** | **I/O standard** | **FPGA pin** | **Description**                                                                                 |
  +========================+===========================+==================+==============+=================================================================================================+
  | RFSW_TX                | RFSW_TX_V1                | 3.3V             | B10          | V1 – high V2- low TX1_1 to TX and TX1_2 to ATT,                                                 |
  |                        |                           |                  |              |                                                                                                 |
  | (SKY13411-374LF – IC3) |                           |                  |              | V1 – low V2 – high TX1_1 to ATT and TX1_2 to TX                                                 |
  |                        +---------------------------+------------------+--------------+                                                                                                 |
  |                        | RFSW_TX_V2                | 3.3V             | C9           |                                                                                                 |
  +------------------------+---------------------------+------------------+--------------+-------------------------------------------------------------------------------------------------+
  | RFSW_RX                | RFSW_RX_V1                | 3.3V             | C11          | V1 – high V2- low RX_H to RX and RX1_W to ATT,                                                  |
  |                        |                           |                  |              |                                                                                                 |
  | (SKY13411-374LF – IC3) |                           |                  |              | V1 – low V2 – high RX1_H to ATT and RX1_W to RX                                                 |
  |                        +---------------------------+------------------+--------------+                                                                                                 |
  |                        | RFSW_RX_V2                | 3.3V             | B11          |                                                                                                 |
  +------------------------+---------------------------+------------------+--------------+-------------------------------------------------------------------------------------------------+
  | Variable attenuator    | TX_LB_AT                  | 3.3V             | C8           | High - -40dB, low - -25dB                                                                       |
  |                        +---------------------------+------------------+--------------+-------------------------------------------------------------------------------------------------+
  |                        | TX_LB_SH                  | 3.3V             | B8           | Attenuator shunting.                                                                            |
  +------------------------+---------------------------+------------------+--------------+-------------------------------------------------------------------------------------------------+

USB 3.0 controller
------------------

Software controls LimeSDR Mini board via the USB 3.0 controller (`FTDI USB 3.0 to FIFO interface bridge chip FT601 <https://ftdichip.com/products/ft600q-b/>`_). The controller signals description showed below:

* FT_D[31:0] – FTDI 32-bit data interface is connected to FPGA.
* FT_TXEn, FT_RXFn, FT_SIWUn, FT_WRn, FT_RDn, FT_OEn, FT_BE[3:0] – FTDI interface control signals.
* FT_CLK – FTDI interface clock. Clock from FTDI is fed to FPGA.

More information about USB 3.0 controller (FTDI) pins, schematic signal names, FPGA interconnections and I/O standards is given in Table 5.

.. table:: Table 5. USB 3.0 controller (FTDI) pins

  +--------------------+--------------------------+---------------------------+--------------+------------------+-------------+
  | **Chip pin (IC6)** | **Chip reference (IC6)** | **Schematic signal name** | **FPGA pin** | **I/O standard** | **Comment** |
  +====================+==========================+===========================+==============+==================+=============+
  | 40                 | DATA_0                   | FT_D0                     | A13          | 3.3V             |             |
  +--------------------+--------------------------+---------------------------+--------------+------------------+-------------+
  | 41                 | DATA_1                   | FT_D1                     | B12          | 3.3V             |             |
  +--------------------+--------------------------+---------------------------+--------------+------------------+-------------+
  | 42                 | DATA_2                   | FT_D2                     | B15          | 3.3V             |             |
  +--------------------+--------------------------+---------------------------+--------------+------------------+-------------+
  | 43                 | DATA_3                   | FT_D3                     | C12          | 3.3V             |             |
  +--------------------+--------------------------+---------------------------+--------------+------------------+-------------+
  | 44                 | DATA_4                   | FT_D4                     | A16          | 3.3V             |             |
  +--------------------+--------------------------+---------------------------+--------------+------------------+-------------+
  | 45                 | DATA_5                   | FT_D5                     | A12          | 3.3V             |             |
  +--------------------+--------------------------+---------------------------+--------------+------------------+-------------+
  | 46                 | DATA_6                   | FT_D6                     | D18          | 3.3V             |             |
  +--------------------+--------------------------+---------------------------+--------------+------------------+-------------+
  | 47                 | DATA_7                   | FT_D7                     | B17          | 3.3V             |             |
  +--------------------+--------------------------+---------------------------+--------------+------------------+-------------+
  | 50                 | DATA_8                   | FT_D8                     | F15          | 3.3V             |             |
  +--------------------+--------------------------+---------------------------+--------------+------------------+-------------+
  | 51                 | DATA_9                   | FT_D9                     | D16          | 3.3V             |             |
  +--------------------+--------------------------+---------------------------+--------------+------------------+-------------+
  | 52                 | DATA_10                  | FT_D10                    | D15          | 3.3V             |             |
  +--------------------+--------------------------+---------------------------+--------------+------------------+-------------+
  | 53                 | DATA_11                  | FT_D11                    | C13          | 3.3V             |             |
  +--------------------+--------------------------+---------------------------+--------------+------------------+-------------+
  | 54                 | DATA_12                  | FT_D12                    | H18          | 3.3V             |             |
  +--------------------+--------------------------+---------------------------+--------------+------------------+-------------+
  | 55                 | DATA_13                  | FT_D13                    | B13          | 3.3V             |             |
  +--------------------+--------------------------+---------------------------+--------------+------------------+-------------+
  | 56                 | DATA_14                  | FT_D14                    | J18          | 3.3V             |             |
  +--------------------+--------------------------+---------------------------+--------------+------------------+-------------+
  | 57                 | DATA_15                  | FT_D15                    | A15          | 3.3V             |             |
  +--------------------+--------------------------+---------------------------+--------------+------------------+-------------+
  | 60                 | DATA_16                  | FT_D16                    | B18          | 3.3V             |             |
  +--------------------+--------------------------+---------------------------+--------------+------------------+-------------+
  | 61                 | DATA_17                  | FT_D17                    | C18          | 3.3V             |             |
  +--------------------+--------------------------+---------------------------+--------------+------------------+-------------+
  | 62                 | DATA_18                  | FT_D18                    | A17          | 3.3V             |             |
  +--------------------+--------------------------+---------------------------+--------------+------------------+-------------+
  | 63                 | DATA_19                  | FT_D19                    | K18          | 3.3V             |             |
  +--------------------+--------------------------+---------------------------+--------------+------------------+-------------+
  | 64                 | DATA_20                  | FT_D20                    | C15          | 3.3V             |             |
  +--------------------+--------------------------+---------------------------+--------------+------------------+-------------+
  | 65                 | DATA_21                  | FT_D21                    | L18          | 3.3V             |             |
  +--------------------+--------------------------+---------------------------+--------------+------------------+-------------+
  | 66                 | DATA_22                  | FT_D22                    | F18          | 3.3V             |             |
  +--------------------+--------------------------+---------------------------+--------------+------------------+-------------+
  | 67                 | DATA_23                  | FT_D23                    | C16          | 3.3V             |             |
  +--------------------+--------------------------+---------------------------+--------------+------------------+-------------+
  | 69                 | DATA_24                  | FT_D24                    | G16          | 3.3V             |             |
  +--------------------+--------------------------+---------------------------+--------------+------------------+-------------+
  | 70                 | DATA_25                  | FT_D25                    | D13          | 3.3V             |             |
  +--------------------+--------------------------+---------------------------+--------------+------------------+-------------+
  | 71                 | DATA_26                  | FT_D26                    | G18          | 3.3V             |             |
  +--------------------+--------------------------+---------------------------+--------------+------------------+-------------+
  | 72                 | DATA_27                  | FT_D27                    | F16          | 3.3V             |             |
  +--------------------+--------------------------+---------------------------+--------------+------------------+-------------+
  | 73                 | DATA_28                  | FT_D28                    | C17          | 3.3V             |             |
  +--------------------+--------------------------+---------------------------+--------------+------------------+-------------+
  | 74                 | DATA_29                  | FT_D29                    | F17          | 3.3V             |             |
  +--------------------+--------------------------+---------------------------+--------------+------------------+-------------+
  | 75                 | DATA_30                  | FT_D30                    | K15          | 3.3V             |             |
  +--------------------+--------------------------+---------------------------+--------------+------------------+-------------+
  | 76                 | DATA_31                  | FT_D31                    | K17          | 3.3V             |             |
  +--------------------+--------------------------+---------------------------+--------------+------------------+-------------+
  | 58                 | CLK                      | FT_CLK                    | D17          | 3.3V             |             |
  +--------------------+--------------------------+---------------------------+--------------+------------------+-------------+
  | 4                  | BE_0                     | FT_BE0                    | L15          | 3.3V             |             |
  +--------------------+--------------------------+---------------------------+--------------+------------------+-------------+
  | 5                  | BE_1                     | FT_BE1                    | J17          | 3.3V             |             |
  +--------------------+--------------------------+---------------------------+--------------+------------------+-------------+
  | 6                  | BE_2                     | FT_BE2                    | K16          | 3.3V             |             |
  +--------------------+--------------------------+---------------------------+--------------+------------------+-------------+
  | 7                  | BE_3                     | FT_BE3                    | H17          | 3.3V             |             |
  +--------------------+--------------------------+---------------------------+--------------+------------------+-------------+
  | 8                  | TXE_N                    | FT_TXEn                   | M16          | 3.3V             |             |
  +--------------------+--------------------------+---------------------------+--------------+------------------+-------------+
  | 9                  | RXF_N                    | FT_RXFn                   | H16          | 3.3V             |             |
  +--------------------+--------------------------+---------------------------+--------------+------------------+-------------+
  | 10                 | SIWU_N                   | FT_SIWUn                  |              | 3.3V             | 10k pull up |
  +--------------------+--------------------------+---------------------------+--------------+------------------+-------------+
  | 11                 | WR_N                     | FT_WRn                    | J16          | 3.3V             |             |
  +--------------------+--------------------------+---------------------------+--------------+------------------+-------------+
  | 12                 | RD_N                     | FT_RDn                    | H15          | 3.3V             |             |
  +--------------------+--------------------------+---------------------------+--------------+------------------+-------------+
  | 13                 | OE_N                     | FT_OEn                    | L16          | 3.3V             |             |
  +--------------------+--------------------------+---------------------------+--------------+------------------+-------------+
  | 15                 | RESET_N                  | FT_RESETn                 | M17          | 3.3V             |             |
  +--------------------+--------------------------+---------------------------+--------------+------------------+-------------+
  | 16                 | WAKEP_N                  | FT_WAKEUPn                | G15          | 3.3V             |             |
  +--------------------+--------------------------+---------------------------+--------------+------------------+-------------+

Indication LEDs
---------------

LimeSDR Mini board comes with three dual colour (red and green (RG)) indication LEDs. These LEDs are soldered on the top of the board near RF connectors.

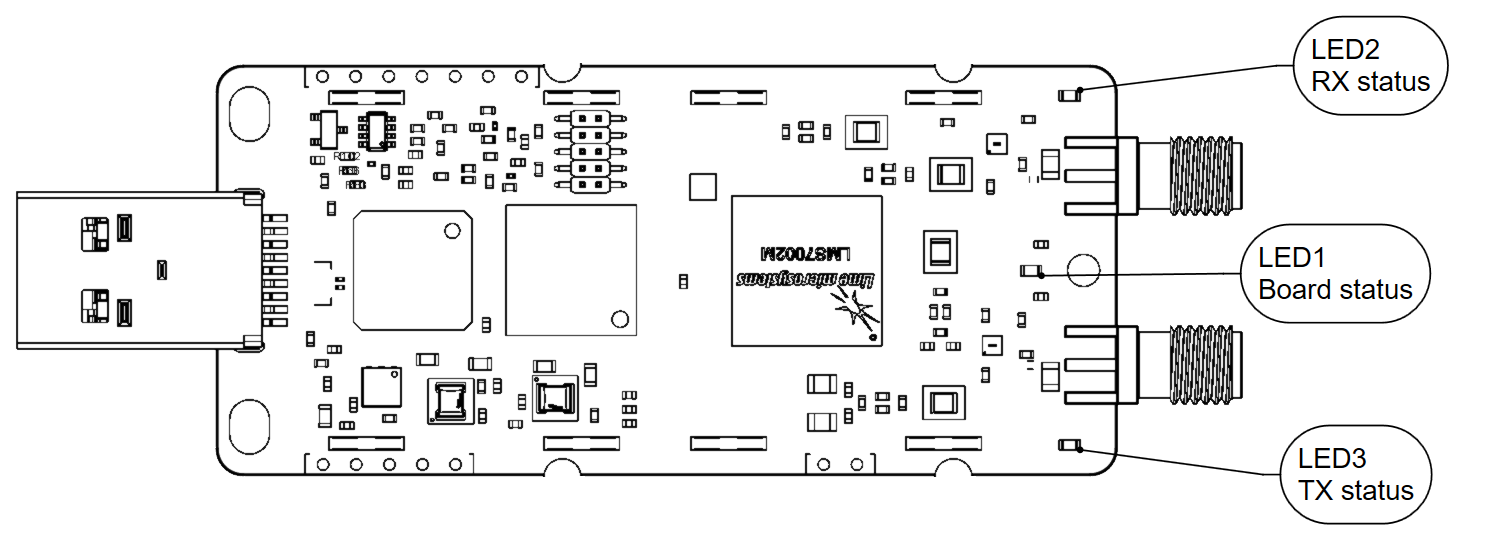
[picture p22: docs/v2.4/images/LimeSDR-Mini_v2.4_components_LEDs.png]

  
  Figure 7: LimeSDR Mini v2.4 indication LEDs (top and bottom)

LEDs are connected to FPGA and their function may be programmed according to the user requirements. Default function of LEDs and related information is listed in Table 6.

.. table:: Table 6. Default LED functions

  +---------------------+--------------------+-----------------+--------------+--------------------------------------------+
  | **Board reference** | **Schematic name** | **Board label** | **FPGA pin** | **Comment**                                |
  +=====================+====================+=================+==============+============================================+
  | LED1                | FPGA_LED1_R        | LED1            | V17          | Board status:                              |
  |                     |                    |                 |              |                                            |
  |                     |                    |                 |              | Blinking green = LMK_CLK clock is running; |
  |                     |                    |                 |              |                                            |
  |                     |                    |                 |              | Red = USB control port is active.          |
  |                     +--------------------+-----------------+--------------+                                            |
  |                     | FPGA_LED1_G        |                 | R16          |                                            |
  +---------------------+--------------------+-----------------+--------------+--------------------------------------------+
  | LED2                | FPGA_LED2_R        | LED2            | R18          | RX status:                                 |
  |                     |                    |                 |              |                                            |
  |                     |                    |                 | (FPGA_GPIO5) | Green = DIQ data receive enabled;          |
  |                     |                    |                 |              |                                            |
  |                     |                    |                 |              | Off = DIQ data receive disabled.           |
  |                     |                    |                 |              |                                            |
  |                     |                    |                 |              | Shared with FPGA_GPIO4 and FPGA_GPIO5.     |
  |                     +--------------------+-----------------+--------------+                                            |
  |                     | FPGA_LED2_G        |                 | M18          |                                            |
  |                     |                    |                 |              |                                            |
  |                     |                    |                 | (FPGA_GPIO4) |                                            |
  +---------------------+--------------------+-----------------+--------------+--------------------------------------------+
  | LED3                | FPGA_LED3_R        | LED3            | R17          | TX status:                                 |
  |                     |                    |                 |              |                                            |
  |                     |                    |                 | (FPGA_GPIO7) | Red = transmitting DIQ data;               |
  |                     |                    |                 |              |                                            |
  |                     |                    |                 |              | Off = no activity.                         |
  |                     |                    |                 |              |                                            |
  |                     |                    |                 |              | Shared with FPGA_GPIO6 and FPGA_GPIO7.     |
  |                     +--------------------+-----------------+--------------+                                            |
  |                     | FPGA_LED3_G        |                 | T17          |                                            |
  |                     |                    |                 |              |                                            |
  |                     |                    |                 | (FPGA_GPIO6) |                                            |
  +---------------------+--------------------+-----------------+--------------+--------------------------------------------+

Low speed interfaces
--------------------

In Table 7, Table 8 and Table 9 are listed FPGA_SPI pins, schematic signal names, FPGA interconnections and I/O standards.

.. table:: Table 7. FPGA_SPI interface pins

  +---------------------------+--------------+------------------+----------------------------------------------+
  | **Schematic signal name** | **FPGA pin** | **I/O standard** | **Comment**                                  |
  +===========================+==============+==================+==============================================+
  | FPGA_SPI_SCLK             | M3           | 2.5V /3.3V       | Serial Clock (FPGA output)                   |
  +---------------------------+--------------+------------------+----------------------------------------------+
  | FPGA_SPI_MOSI             | L3           | 2.5V /3.3V       | Data (FPGA output)                           |
  +---------------------------+--------------+------------------+----------------------------------------------+
  | FPGA_SPI_MISO             | K3           | 2.5V /3.3V       | Data (FPGA input)                            |
  +---------------------------+--------------+------------------+----------------------------------------------+
  | FPGA_SPI_LMS_SS           | N3           | 2.5V /3.3V       | IC1 (LMS7002) SPI slave select (FPGA output) |
  +---------------------------+--------------+------------------+----------------------------------------------+
  | FPGA_SPI_DAC_SS           | L4           | 2.5V /3.3V       | IC11 SPI slave select (FPGA output)          |
  +---------------------------+--------------+------------------+----------------------------------------------+

In the table below are listed FPGA_CFG_SPI pins, schematic signal names, FPGA interconnections and I/O standards.

.. table:: Table 8. FPGA_CFG_SPI interface pins

  +---------------------------+--------------+------------------+-------------------------------------+
  | **Schematic signal name** | **FPGA pin** | **I/O standard** | **Comment**                         |
  +===========================+==============+==================+=====================================+
  | FPGA_CFG_SPI_SCLK         | U16          | 3.3V             | Serial Clock (FPGA output)          |
  +---------------------------+--------------+------------------+-------------------------------------+
  | FPGA_CFG_SPI_MOSI         | U18          | 3.3V             |                                     |
  +---------------------------+--------------+------------------+-------------------------------------+
  | FPGA_CFG_SPI_MISO         | T18          | 3.3V             |                                     |
  +---------------------------+--------------+------------------+-------------------------------------+
  | FPGA_CFG_SPI_SS           | U17          | 3.3V             | IC15 SPI slave select (FPGA output) |
  +---------------------------+--------------+------------------+-------------------------------------+

In the table below are listed FPGA_I2C interface slave devices and their other information.

.. table:: Table 9. FPGA_I2C interface pins

  +----------------------+--------------------+------------------+------------------+-------------+
  | **I2C slave device** | **Slave device**   | **I2C address**  | **I/O standard** | **Comment** |
  +======================+====================+==================+==================+=============+
  | IC10                 | Temperature sensor | 1 0 0 1 0 0 0 RW | 3.3V             | LM75        |
  +----------------------+--------------------+------------------+------------------+-------------+
  | IC12                 | EEPROM             | 1 0 1 0 0 0 0 RW | 3.3V             | M24128      |
  +----------------------+--------------------+------------------+------------------+-------------+

GPIO connectors
---------------

8 GPIOs from FPGA are connected to 10 pin 0.05” header. Additional 2 pins are dedicated for power. FPGA_GPIO[7:4] are shared with TX and RX LEDs. Remove solder from solder bridges to disconnect LEDs from GPIOs lines. In Table 10 is listed FPGA_GPIO (J3) information.

.. table:: Table 10. FPGA GPIO connector (J3) pins

  +-------------------+---------------------------+--------------+------------------+-------------------------------------------------+
  | **Connector pin** | **Schematic signal name** | **FPGA pin** | **I/O standard** | **Comment**                                     |
  +===================+===========================+==============+==================+=================================================+
  | 1                 | FPGA_GPIO0                | N15          | 3.3V             |                                                 |
  +-------------------+---------------------------+--------------+------------------+-------------------------------------------------+
  | 2                 | FPGA_GPIO1                | N18          | 3.3V             |                                                 |
  +-------------------+---------------------------+--------------+------------------+-------------------------------------------------+
  | 3                 | FPGA_GPIO2                | N16          | 3.3V             |                                                 |
  +-------------------+---------------------------+--------------+------------------+-------------------------------------------------+
  | 4                 | FPGA_GPIO3                | N17          | 3.3V             |                                                 |
  +-------------------+---------------------------+--------------+------------------+-------------------------------------------------+
  | 5                 | FPGA_GPIO4                | M18          | 3.3V             | Shared with FPGA_LED2_G                         |
  +-------------------+---------------------------+--------------+------------------+-------------------------------------------------+
  | 6                 | FPGA_GPIO5                | R18          | 3.3V             | Shared with FPGA_LED2_R                         |
  +-------------------+---------------------------+--------------+------------------+-------------------------------------------------+
  | 7                 | FPGA_GPIO6                | T17          | 3.3V             | Shared with FPGA_LED3_G                         |
  +-------------------+---------------------------+--------------+------------------+-------------------------------------------------+
  | 8                 | FPGA_GPIO7                | R17          | 3.3V             | Shared with FPGA_LED3_R                         |
  +-------------------+---------------------------+--------------+------------------+-------------------------------------------------+
  | 9                 | GND                       |              |                  | Ground pin                                      |
  +-------------------+---------------------------+--------------+------------------+-------------------------------------------------+
  | 10                |                           |              |                  | Selectable power net (3.3V or 5V). Default 3.3V |
  +-------------------+---------------------------+--------------+------------------+-------------------------------------------------+

Another 2 GPIOs are connected to 5 header on the board edge. In Table 11 is listed FPGA_EGPIO (J4) information.

.. table:: Table 11. FPGA EGPIO connector (J4) pins

  +-------------------+---------------------------+--------------+------------------+-------------------------------------------------+
  | **Connector pin** | **Schematic signal name** | **FPGA pin** | **I/O standard** | **Comment**                                     |
  +===================+===========================+==============+==================+=================================================+
  | 1                 | GND                       |              |                  | Ground pin                                      |
  +-------------------+---------------------------+--------------+------------------+-------------------------------------------------+
  | 2                 | FPGA_EGPIO0               | A10          | 3.3V             |                                                 |
  +-------------------+---------------------------+--------------+------------------+-------------------------------------------------+
  | 3                 | FPGA_EGPIO1               | A8           | 3.3V             |                                                 |
  +-------------------+---------------------------+--------------+------------------+-------------------------------------------------+
  | 4                 | VCC3P3                    |              | 3.3V             | Power net (3.3V)                                |
  +-------------------+---------------------------+--------------+------------------+-------------------------------------------------+
  | 5                 | VCC5P0                    |              | 5.0V             | Power net (5.0V)                                |
  +-------------------+---------------------------+--------------+------------------+-------------------------------------------------+
 
JTAG interface
--------------

To debug FPGA design, flash bitstream to FPGA and/or Flash memory JTAG is used. It is located on the PCB top side (see :ref:`target4`) and attaches to the programmer using 7-pin, 0.1” spaced JTAG connector J5. JTAG connector pins, schematic signal names, FPGA interconnections and I/O standards are listed in Table 12.

.. table:: Table 12. JTAG connector J5 pins

  +-------------------+---------------------------+--------------+------------------+--------------------+
  | **Connector pin** | **Schematic signal name** | **FPGA pin** | **I/O standard** | **Comment**        |
  +===================+===========================+==============+==================+====================+
  | 1                 | GND                       |              |                  | Ground             |
  +-------------------+---------------------------+--------------+------------------+--------------------+
  | 2                 | TCK                       | U13          | 3.3V             | Test Clock         |
  +-------------------+---------------------------+--------------+------------------+--------------------+
  | 3                 | TDO                       | V14          | 3.3V             | Test Data Out      |
  +-------------------+---------------------------+--------------+------------------+--------------------+
  | 4                 | TMS                       | V13          | 3.3V             | Test Mode Select   |
  +-------------------+---------------------------+--------------+------------------+--------------------+
  | 5                 | TDI                       | T13          | 3.3V             | Test Data In       |
  +-------------------+---------------------------+--------------+------------------+--------------------+
  | 6                 | VCC3P3                    |              |                  | Power (3.3V)       |
  +-------------------+---------------------------+--------------+------------------+--------------------+
  | 7                 | VCC5P0                    |              |                  | Power (5.0V)       |
  +-------------------+---------------------------+--------------+------------------+--------------------+

More information about JTAG programming can be found in :ref:`target3`.

Board temperature control
-------------------------

LimeSDR-Mini has integrated temperature sensor which controls FAN to keep board in operating temperature range. FAN must be connected to J9 (0.1” pitch) connector. FAN control voltage y default is 5V, but it can be changed to 3.3V by resistors.

Fan will be turned on if board will heat up to 55°C and FAN will be turned off if board will cool down to 45°C.

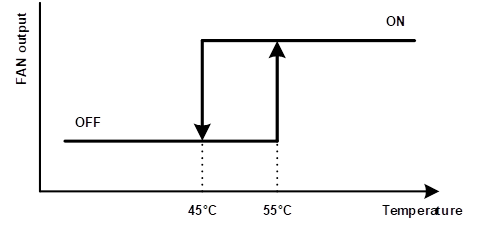
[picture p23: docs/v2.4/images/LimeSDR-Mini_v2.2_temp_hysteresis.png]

  
  Figure 8: FAN control temperature hysteresis 

Clock distribution
------------------

LimeSDR-Mini board clock distribution block diagram is presented in Figure 9. LimeSDR-Mini board has onboard 40.00 MHz VCTCXO that is reference clock for RF transceiver and FPGA PLLs. Board clock distribution block diagram is presented in Figure 9. 

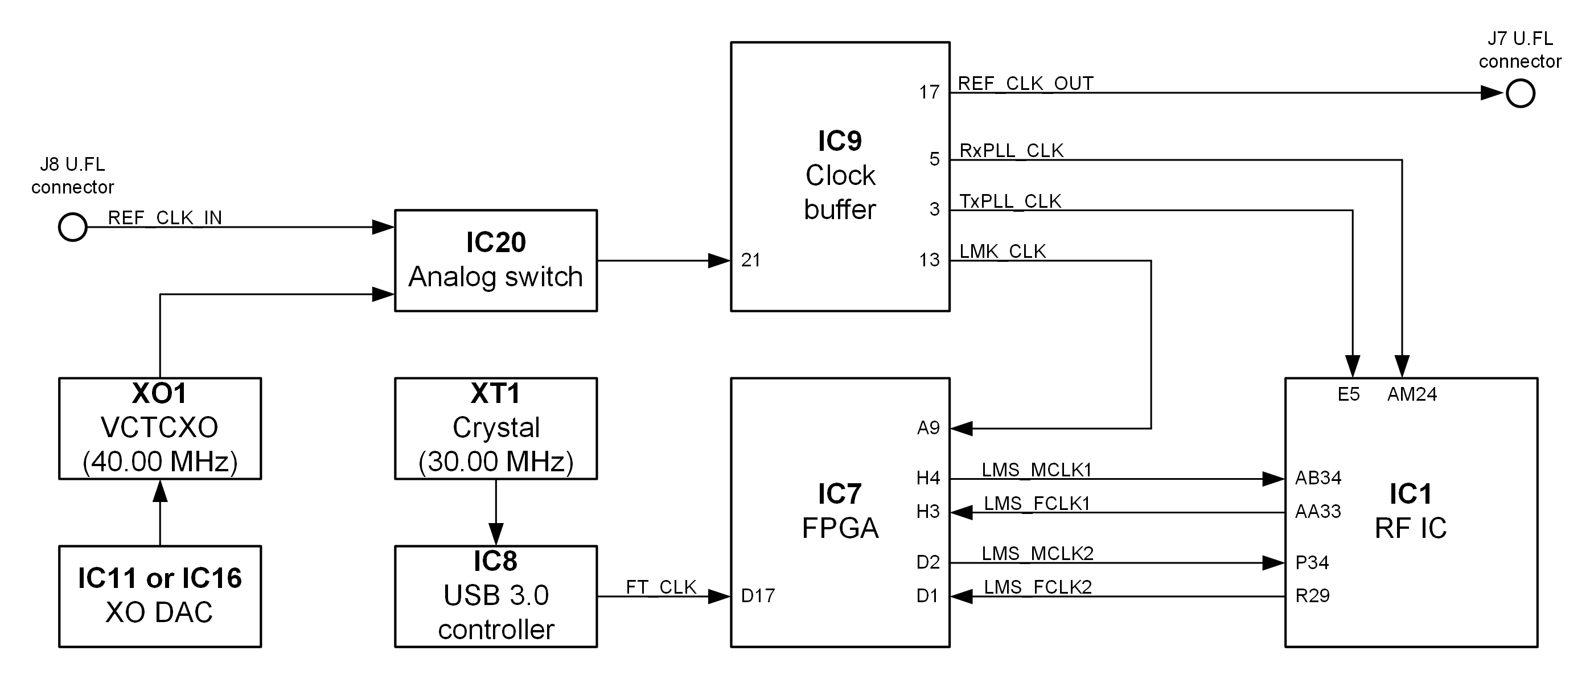
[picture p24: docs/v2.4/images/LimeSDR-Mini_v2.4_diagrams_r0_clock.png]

  
  Figure 9: LimeSDR Mini v2.4 board clock distribution block diagram

Rakon E7355LF 40 MHz voltage controlled temperature compensated crystal oscillator (VCTCXO) is main board clock source. VCTCXO frequency can be tuned by using DAC (IC11 10 bit or IC16 16 bit (unpopulated)). Main VCTCXO parameters are listed in Table 13.

.. table:: Table 13. Rakon E7355LF VCTCXO main parameters

  +----------------------------------------+----------------------------------+
  | **Frequency parameter**                | **Value**                        |
  +========================================+==================================+
  | Calibration (25°C ± 1°C)               | ± 1 ppm max                      |
  +----------------------------------------+----------------------------------+
  | Stability (-40 to 85 °C)               | ± 0.5 max                        |
  +----------------------------------------+----------------------------------+
  | Long term stability (1 year, 10 years) | ± 2 ppm max, ± 4 ppm max         |
  +----------------------------------------+----------------------------------+
  | Control voltage range                  | 0.5V .. 2.5V                     |
  +----------------------------------------+----------------------------------+
  | Frequency tuning                       | ± 7 ppm min, ± 15 ppm max        |
  +----------------------------------------+----------------------------------+
  | Slope                                  | +9 ppm/V                         |
  +----------------------------------------+----------------------------------+

VCTCXO clock and external reference clock connector J8 (REF_CLK_IN) are connected to analog switch for clock source selection. Selected clock source is fed to clock buffer IC9. Buffered clock is connected to RF transceiver and FPGA. Buffered clock is also connected to connector J7 (REF_CLK_OUT) and can be fed to external hardware for synchronisation.

Main board clock lines and other related information are listed in Table 14

.. table:: Table 14. LimeSDR Mini v2.4 main clock lines

  +--------------------------+---------------------------+------------------+--------------+--------------------------------------------+
  | **Source**               | **Schematic signal name** | **I/O standard** | **FPGA pin** | **Description**                            |
  +==========================+===========================+==================+==============+============================================+
  | External                 | REF_CLK_IN                | 2.5V/3.3V        |              | External reference clock input             |
  +--------------------------+---------------------------+------------------+--------------+--------------------------------------------+
  | Clock buffer (IC9)       | REF_CLK_OUT               | 3.3V             |              | Reference clock output                     |
  +--------------------------+---------------------------+------------------+--------------+--------------------------------------------+
  | Clock buffer (IC9)       | LMK_CLK                   | 3.3V             | A9           | Reference clock connected to FPGA          |
  +--------------------------+---------------------------+------------------+--------------+--------------------------------------------+
  | RF transceiver (IC1)     | RxPLL_CLK                 | 1.8V             |              | Reference clock input                      |
  |                          +---------------------------+------------------+--------------+--------------------------------------------+
  |                          | TxPLL_CLK                 | 1.8V             |              | Reference clock input                      |
  |                          +---------------------------+------------------+--------------+--------------------------------------------+
  |                          | LMS_MCLK1                 | 2.5V/3.3V        | H4           |                                            |
  |                          +---------------------------+------------------+--------------+--------------------------------------------+
  |                          | LMS_FCLK1                 | 2.5V/3.3V        | H3           |                                            |
  |                          +---------------------------+------------------+--------------+--------------------------------------------+
  |                          | LMS_MCLK2                 | 2.5V/3.3V        | D2           |                                            |
  |                          +---------------------------+------------------+--------------+--------------------------------------------+
  |                          | LMS_FCLK2                 | 2.5V/3.3V        | D1           |                                            |
  +--------------------------+---------------------------+------------------+--------------+--------------------------------------------+
  | USB 3.0 controller (IC8) | FT_CLK                    | 3.3V             | D17          | Clock output (100 MHz) from USB controller |
  +--------------------------+---------------------------+------------------+--------------+--------------------------------------------+

Power distribution
------------------

LimeSDR-Mini board is powered from USB port (5V). LimeSDR-Mini board power delivery network consists of different power rails with different voltages, filters, power sequences. LimeSDR-Mini board power distribution block diagram is presented in Figure 10.


  
  Figure 12: LimeSDR Mini v2.4 board power distribution block diagram

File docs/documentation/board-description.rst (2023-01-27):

Board Description
=================

More detailed description of Loamiest Mini board components and interconnections is given in the sections of this chapter.

RF transceiver digital connectivity
-----------------------------------

The interface and control signals are described below:

* Digital Interface Signals: LENS7002 is using data bus LIMNS_DIQ1_D[11:0] and LMS_DIQ2_D[11:0], LMS_EN_IQSEL1 and LMS_EN_IQSEL2, LMS_FCLK1 and LMS_FCLK2, LMS_MCLK1 and LMS_MCLK2 signals to transfer data to/from FPGA. Indexes 1 and 2 indicate transceiver digital data PORT-1 or PORT-2. Any of these ports can be used to transmit or receive data. By default PORT-1 is selected as transmit port and PORT-2 is selected as receiver port. The FCLK# is input clock and MCLK# is output clock for LMS7002M transceiver. TXNRX signals sets ports directions. For LMS7002M interface timing details refer to `LMS7002M transceiver datasheet <https://limemicro.com/app/uploads/2017/07/LMS7002M-Data-Sheet-v3.1r00.pdf>`_ page 12-13.
* LMS Control Signals: these signals are used for optional functionality:
  * LMS_RXEN, LMS_TXEN – receiver and transmitter enable/disable signals connected to FPGA Bank 8 (VDIO_LMS_FPGA; 2.5V).
  * LMS_RESET – LMS7002M reset connected to FPGA Bank 3 (VDIO_LMS_FPGA; 2.5V).
* SPI Interface: LMS7002M transceiver is configured via 4-wire SPI interface; FPGA_SPI_SCLK, FPGA_SPI_MOSI, FPGA_SPI_MISO, FPGA_SPI_LMS_SS. The SPI interface controlled from FPGA Bank 3 (VDIO_LMS_FPGA; 2.5V). 
* LMS I2C Interface: can be used for LMS EEPROM content modifying or for debug purposes. The signals LMS_I2C_SCL, LMS_I2C_DATA connected to EEPROM.

.. table:: Table 1. RF transceiver (LMS7002) digital interface pins

  +--------------------+--------------------------+---------------------------+--------------+-----------------------+------------------------------+
  | **Chip pin (IC1)** | **Chip reference (IC1)** | **Schematic signal name** | **FPGA pin** | **FPGA I/O standard** | **FPGA I/O standard**        |
  +====================+==========================+===========================+==============+=======================+==============================+
  | E5                 | xoscin_tx                | TxPLL_CLK                 | -            | -                     | Connected to 40.00 MHz clock |
  +--------------------+--------------------------+---------------------------+--------------+-----------------------+------------------------------+
  | AB34               | MCLK1                    | LMS_MCLK1                 | H4           | 2.5V/3.3V             |                              |
  +--------------------+--------------------------+---------------------------+--------------+-----------------------+------------------------------+
  | AA33               | FCLK1                    | LMS_FCLK1                 | H3           | 2.5V/3.3V             |                              |
  +--------------------+--------------------------+---------------------------+--------------+-----------------------+------------------------------+
  | V32                | TXNRX1                   | LMS_TXNRX1                | F1           | 2.5V/3.3V             |                              |
  +--------------------+--------------------------+---------------------------+--------------+-----------------------+------------------------------+
  | U29                | TXEN                     | LMS_TXEN                  | B7           | 2.5V/3.3V             |                              |
  +--------------------+--------------------------+---------------------------+--------------+-----------------------+------------------------------+
  | 1Y32               | ENABLE_IQSEL1            | LMS_EN_IQSEL1             | F3           | 2.5V/3.3V             |                              |
  +--------------------+--------------------------+---------------------------+--------------+-----------------------+------------------------------+
  | AG31               | DIQ1_D0                  | LMS_DIQ1_D0               | J2           | 2.5V/3.3V             |                              |
  +--------------------+--------------------------+---------------------------+--------------+-----------------------+------------------------------+
  | AF30               | DIQ1_D1                  | LMS_DIQ1_D1               | L1           | 2.5V/3.3V             |                              |
  +--------------------+--------------------------+---------------------------+--------------+-----------------------+------------------------------+
  | AF34               | DIQ1_D2                  | LMS_DIQ1_D2               | K1           | 2.5V/3.3V             |                              |
  +--------------------+--------------------------+---------------------------+--------------+-----------------------+------------------------------+
  | AE31               | DIQ1_D3                  | LMS_DIQ1_D3               | K4           | 2.5V/3.3V             |                              |
  +--------------------+--------------------------+---------------------------+--------------+-----------------------+------------------------------+
  | AD30               | DIQ1_D4                  | LMS_DIQ1_D4               | G3           | 2.5V/3.3V             |                              |
  +--------------------+--------------------------+---------------------------+--------------+-----------------------+------------------------------+
  | AC29               | DIQ1_D5                  | LMS_DIQ1_D5               | F4           | 2.5V/3.3V             |                              |
  +--------------------+--------------------------+---------------------------+--------------+-----------------------+------------------------------+
  | AE33               | DIQ1_D6                  | LMS_DIQ1_D6               | J1           | 2.5V/3.3V             |                              |
  +--------------------+--------------------------+---------------------------+--------------+-----------------------+------------------------------+
  | AD32               | DIQ1_D7                  | LMS_DIQ1_D7               | H1           | 2.5V/3.3V             |                              |
  +--------------------+--------------------------+---------------------------+--------------+-----------------------+------------------------------+
  | AC31               | DIQ1_D8                  | LMS_DIQ1_D8               | G4           | 2.5V/3.3V             |                              |
  +--------------------+--------------------------+---------------------------+--------------+-----------------------+------------------------------+
  | AC33               | DIQ1_D9                  | LMS_DIQ1_D9               | F2           | 2.5V/3.3V             |                              |
  +--------------------+--------------------------+---------------------------+--------------+-----------------------+------------------------------+
  | AB30               | DIQ1_D10                 | LMS_DIQ1_D10              | G1           | 2.5V/3.3V             |                              |
  +--------------------+--------------------------+---------------------------+--------------+-----------------------+------------------------------+
  | AB32               | DIQ1_D11                 | LMS_DIQ1_D11              | H2           | 2.5V/3.3V             |                              |
  +--------------------+--------------------------+---------------------------+--------------+-----------------------+------------------------------+
  | AM24               | xoscin_rx                | RxPLL_CLK                 | -            | -                     | Connected to 40.00 MHz clock |
  +--------------------+--------------------------+---------------------------+--------------+-----------------------+------------------------------+
  | P34                | MCLK2                    | LMS_MCLK2                 | D2           | 2.5V/3.3V             |                              |
  +--------------------+--------------------------+---------------------------+--------------+-----------------------+------------------------------+
  | R29                | FCLK2                    | LMS_FCLK2                 | D1           | 2.5V/3.3V             |                              |
  +--------------------+--------------------------+---------------------------+--------------+-----------------------+------------------------------+
  | U31                | TXNRX2                   | LMS_TXNRX2                | B6           | 2.5V/3.3V             |                              |
  +--------------------+--------------------------+---------------------------+--------------+-----------------------+------------------------------+
  | V34                | RXEN                     | LMS_RXEN                  | D6           | 2.5V/3.3V             |                              |
  +--------------------+--------------------------+---------------------------+--------------+-----------------------+------------------------------+
  | R33                | ENABLE_IQSEL2            | LMS_EN_IQSEL2             | C4           | 2.5V/3.3V             |                              |
  +--------------------+--------------------------+---------------------------+--------------+-----------------------+------------------------------+
  | H30                | DIQ2_D0                  | LMS_DIQ2_D0               | A3           | 2.5V/3.3V             |                              |
  +--------------------+--------------------------+---------------------------+--------------+-----------------------+------------------------------+
  | J31                | DIQ2_D1                  | LMS_DIQ2_D1               | C2           | 2.5V/3.3V             |                              |
  +--------------------+--------------------------+---------------------------+--------------+-----------------------+------------------------------+
  | K30                | DIQ2_D2                  | LMS_DIQ2_D2               | A2           | 2.5V/3.3V             |                              |
  +--------------------+--------------------------+---------------------------+--------------+-----------------------+------------------------------+
  | K32                | DIQ2_D3                  | LMS_DIQ2_D3               | B4           | 2.5V/3.3V             |                              |
  +--------------------+--------------------------+---------------------------+--------------+-----------------------+------------------------------+
  | L31                | DIQ2_D4                  | LMS_DIQ2_D4               | C3           | 2.5V/3.3V             |                              |
  +--------------------+--------------------------+---------------------------+--------------+-----------------------+------------------------------+
  | K34                | DIQ2_D5                  | LMS_DIQ2_D5               | B2           | 2.5V/3.3V             |                              |
  +--------------------+--------------------------+---------------------------+--------------+-----------------------+------------------------------+
  | M30                | DIQ2_D6                  | LMS_DIQ2_D6               | D3           | 2.5V/3.3V             |                              |
  +--------------------+--------------------------+---------------------------+--------------+-----------------------+------------------------------+
  | M32                | DIQ2_D7                  | LMS_DIQ2_D7               | B1           | 2.5V/3.3V             |                              |
  +--------------------+--------------------------+---------------------------+--------------+-----------------------+------------------------------+
  | N31                | DIQ2_D8                  | LMS_DIQ2_D8               | A4           | 2.5V/3.3V             |                              |
  +--------------------+--------------------------+---------------------------+--------------+-----------------------+------------------------------+
  | N33                | DIQ2_D9                  | LMS_DIQ2_D9               | C1           | 2.5V/3.3V             |                              |
  +--------------------+--------------------------+---------------------------+--------------+-----------------------+------------------------------+
  | P30                | DIQ2_D10                 | LMS_DIQ2_D10              | C7           | 2.5V/3.3V             |                              |
  +--------------------+--------------------------+---------------------------+--------------+-----------------------+------------------------------+
  | P32                | DIQ2_D11                 | LMS_DIQ2_D11              | A6           | 2.5V/3.3V             |                              |
  +--------------------+--------------------------+---------------------------+--------------+-----------------------+------------------------------+
  | U33                | CORE_LDO_EN              | LMS_CORE_LDO_EN           | C6           | 2.5V/3.3V             |                              |
  +--------------------+--------------------------+---------------------------+--------------+-----------------------+------------------------------+
  | E27                | RESET                    | LMS_RESET                 | A7           | 2.5V/3.3V             |                              |
  +--------------------+--------------------------+---------------------------+--------------+-----------------------+------------------------------+
  | D28                | SEN                      | FPGA_SPI_LMS_SS           | N3           | 2.5V/3.3V             | SPI interface                |
  +--------------------+--------------------------+---------------------------+--------------+-----------------------+------------------------------+
  | C29                | SCLK                     | FPGA_SPI_SCLK             | M3           | 2.5V/3.3V             | SPI interface                |
  +--------------------+--------------------------+---------------------------+--------------+-----------------------+------------------------------+
  | F30                | SDIO                     | FPGA_SPI_MOSI             | L3           | 2.5V/3.3V             | SPI interface                |
  +--------------------+--------------------------+---------------------------+--------------+-----------------------+------------------------------+
  | F28                | SDO                      | FPGA_SPI_MISO             | K3           | 2.5V/3.3V             | SPI interface                |
  +--------------------+--------------------------+---------------------------+--------------+-----------------------+------------------------------+
  | D26                | SDA                      | LMS_I2C_SDA               | -            | -                     | Connected to EEPROM          |
  +--------------------+--------------------------+---------------------------+--------------+-----------------------+------------------------------+
  | C27                | SCL                      | LMS_I2C_SCL               | -            | -                     | Connected to EEPROM          |
  +--------------------+--------------------------+---------------------------+--------------+-----------------------+------------------------------+

RF path and control signals
---------------------------

LimeSDR Mini RF path contains matching networks, RF switches, loopback variable attenuator and 2 SMA connectors (J1 - TX and J2 - RX) as shown in Figure 1.


  
  Figure 1: LimeSDR Mini v2.2 RF diagram

RF transceiver TX and RX ports has its dedicated matching network which together determines the working frequency range. More detailed information about RF transceiver ports and matching network frequency ranges is listed in the Table 2.

.. table:: Table 2. RF transceiver ports and matching networks frequency ranges

  +-------------------------------+--------------------------------------+
  | **RF transceiver port**       | **Frequency range**                  |
  +===============================+======================================+
  | TX1_1                         | 2 GHz - 2.6 GHz                      |
  +-------------------------------+--------------------------------------+
  | TX1_2                         | 30 MHz - 1.9 GHz                     |
  +-------------------------------+--------------------------------------+
  | RX1_H                         | 2 GHz - 2.6 GHz                      |
  +-------------------------------+--------------------------------------+
  | RX1_W                         | 700 MHz - 900 MHz                    |
  +-------------------------------+--------------------------------------+

RF path control signals are described in the Table 3.

.. table:: Table 3. RF path control signals
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

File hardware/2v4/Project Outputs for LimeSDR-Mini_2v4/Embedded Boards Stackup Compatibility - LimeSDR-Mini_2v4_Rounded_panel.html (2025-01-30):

Altium customize

# Stackup Compatibility

Date: | | 2023-04-24
Time: | | 16:01:49
Elapsed Time: | | 00:00:00
Filename: | | E:\Saniok\Lime Micro\Lime PCBs\LimeSDR_Mini\LimeSDR_Mini_2v4\Altium Designer design files\PCB\LimeSDR-Mini_2v4_Rounded_panel.PcbDoc
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

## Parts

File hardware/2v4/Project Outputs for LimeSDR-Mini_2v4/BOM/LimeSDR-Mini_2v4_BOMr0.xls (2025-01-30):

Item # | Comment | Quantity | Designator | Footprint | Manufacturer | Manufacturer Part Number 1 | Supplier 1 | Supplier Part Number 1 | Part Description | Assembly Info | Number of NF parts in row | Number of fitted parts in row
1 | 1uF, 25V | 5 | C1, C159, C164, C165, C194 | CAP0402 | TDK | C1005X5R1E105K050BC | Digi-Key | 445-9066-1-ND | 1 µF ±10% 25V Ceramic Capacitor X5R 0402 (1005 Metric) | NF(C194) | 1 | 4
2 | 10pF, 25V | 3 | C2, C130, C131 | CAP0402 | AVX | 04023A100JAT2A | Farnell | 2332478RL | 10pF ±5% 25V C0G, NP0 Ceramic Capacitor -55°C ~ 125°C Surface Mount, MLCC 0402 (1005 Metric) 0.039" L x 0.020" W (1.00mm x 0.50mm) |  |  | 3
3 | 100pF, 50V | 18 | C3, C5, C7, C16, C17, C19, C20, C22, C23, C71, C84, C167, C168, C169, C170, C172, C173, C192 | CAP0402 | Yageo | CC0402JRNPO9BN101 | Digi-Key | 311-1024-1-ND | 100pF ±5% 50V C0G, NP0 Ceramic Capacitor -55°C ~ 125°C Surface Mount, MLCC 0402 (1005 Metric) 0.039" L x 0.020" W (1.00mm x 0.50mm) | NF(C7 C19 C20 C22 C71 C84 C192) | 7 | 11
4 | 100nF, 16V | 29 | C4, C6, C8, C15, C18, C21, C97, C129, C132, C133, C153, C154, C155, C156, C161, C162, C163, C166, C171, C174, C175, C180, C181, C183, C185, C186, C195, MN12, MN15 | CAP0402 | Murata Electronics | GRM155R71C104KA88D | Mouser | 81-GRM155R71C104KA88 | 0.10µF ±10% 16V X7R Ceramic Capacitor -55°C ~ 125°C Surface Mount, MLCC 0402 (1005 Metric) 0.039" L x 0.020" W (1.00mm x 0.50mm) | NF(C6 C21 C174 C180 C183 C186) | 6 | 23
5 | 47pF, 50V | 6 | C9, C12, C24, C27, C158, C160 | CAP0402 | TDK Corporation | GRM1555C1H470FA01D | Digi-Key | 490-6241-1-ND | 47pF ±1% 50V C0G, NP0 Ceramic Capacitor -55°C ~ 125°C Surface Mount, MLCC 0402 (1005 Metric) 0.039" L x 0.020" W (1.00mm x 0.50mm) | NF(C158 C160) | 2 | 4
6 | 510pF | 6 | C10, C11, C25, C26, MN21, MN24 | CAP0402 | Murata Electronics North America | GRM1555C1H511JA01D | Digi-Key | 490-3237-1-ND | 510pF ±5% 50V C0G, NP0 Ceramic Capacitor -55°C ~ 125°C Surface Mount, MLCC 0402 (1005 Metric) 0.039" L x 0.020" W (1.00mm x 0.50mm) |  |  | 6
7 | 10nF, 50V | 14 | C13, C14, C28, C29, C102, C104, C109, C113, C115, C119, C124, C146, C148, C150 | CAP0402 | Murata | GRM155R71H103KA88D | Digi-Key | 490-4516-1-ND | 10000pF ±10% 50V Ceramic Capacitor X7R 0402 (1005 Metric) |  |  | 14
8 | 1uF, 6.3V | 59 | C30, C32, C33, C34, C35, C36, C37, C39, C41, C43, C44, C45, C46, C48, C49, C50, C51, C52, C53, C54, C55, C56, C57, C58, C59, C60, C62, C63, C64, C65, C66, C67, C73, C75, C77, C79, C81, C85, C86, C87, C88, C89, C90, C91, C92, C93, C94, C95, C96, C100, C111, C117, C122, C135, C137, C139, C141, C144, C152 | CAP0201 | TDK Corporation | JMK063ABJ105MP-F | Digi-Key | 587-5864-2-ND | 1µF ±20% 6.3V X5R Ceramic Capacitor -55°C ~ 85°C Surface Mount, MLCC 0201 (0603 Metric) 0.024" L x 0.012" W (0.60mm x 0.30mm) |  |  | 59
9 | 1nF, 10% | 11 | C31, C38, C40, C42, C47, C61, C72, C74, C76, C78, C80 | CAP0201 | TDK Corporation | C0603X7R1E102K030BA | Digi-Key | 445-7275-1-ND | 1000pF ±10% 25V X7R Ceramic Capacitor -55°C ~ 125°C Surface Mount, MLCC 0201 (0603 Metric) 0.024" L x 0.012" W (0.60mm x 0.30mm) |  |  | 11
10 | 4.7uF, 6.3V | 9 | C68, C69, C82, C83, C178, C179, C190, C191, C197 | CAP0402 | Murata Electronics North America | GRM155R60J475ME87D | Digi-Key | 490-5408-1-ND | 4.7µF ±20% 6.3V X5R Ceramic Capacitor -55°C ~ 85°C Surface Mount, MLCC 0402 (1005 Metric) 0.039" L x 0.020" W (1.00mm x 0.50mm) |  |  | 9
11 | 10uF, 6.3V | 9 | C70, C99, C116, C121, C134, C143, C151, C196, C198 | CAP0603 | Yageo | CC0603MRX5R5BB106 | Digi-Key | 311-1448-2-ND | 10µF ±20% 6.3V X5R Ceramic Capacitor -55°C ~ 85°C Surface Mount, MLCC 0603 (1608 Metric) 0.063" L x 0.031" W (1.60mm x 0.80mm) |  |  | 9
12 | 100nF, 10V | 24 | C98, C101, C103, C105, C106, C107, C108, C110, C112, C114, C118, C120, C123, C125, C126, C127, C128, C136, C138, C140, C142, C145, C147, C149 | CAP0201 | Murata | GRT033C81A104KE01D | Digi-Key | 490-12232-1-ND | 0.1 µF ±10% 10V Ceramic Capacitor X6S 0201 (0603 Metric) |  |  | 24
13 | 18nF, 16V | 1 | C157 | CAP0402 | Yageo | CC0402KRX7R7BB183 | Digi-Key | 311-1706-1-ND | CAP CER 0.018UF 16V X7R 0402 | NF(C157) | 1 | 0
14 | 22uF, 10V | 4 | C176, C177, C188, C189 | CAP0603 | TDK Corporation | C1608X5R1A226M080AC | Mouser | 810-C1608X5R1A226M | 22µF ±20% 10V X5R Ceramic Capacitor -55°C ~ 85°C Surface Mount, MLCC 0603 (1608 Metric) 0.063" L x 0.031" W (1.60mm x 0.80mm) |  |  | 4
15 | 16pF, 50V | 1 | C182 | CAP0402 | Yageo | CC0402JRNPO9BN160 | Digi-Key | 311-1662-1-ND | 16 pF ±5% 50V Ceramic Capacitor C0G, NP0 0402 (1005 Metric) |  |  | 1
16 | 1nF, 50V | 1 | C184 | CAP0402 | Murata Electronics | GCM155R71H102KA37D | Mouser | 81-GCM155R71H102KA7D | 1000pF ±10% 50V X7R Ceramic Capacitor -55°C ~ 125°C Surface Mount, MLCC 0402 (1005 Metric) 0.039" L x 0.020" W (1.00mm x 0.50mm) | NF(C184) | 1 | 0
17 | 82pF, 50V | 1 | C193 | CAP0402 | Taiyo Yuden | UMK105CH820JVHF | Digi-Key | 587-5099-1-ND | 82 pF ±5% 50V Ceramic Capacitor CH 0402 (1005 Metric) |  |  | 1
18 | ESD8472 | 2 | ESD1, ESD2 | ESD8472_X3DFN2 | ON Semiconductor | ESD8472MUT5G | Digi-Key | ESD8472MUT5GOSCT-ND | TVS DIODE 5.3VWM 14VC X3DFN2 | NF(ESD1 ESD2) | 2 | 0
19 | ESD7016 | 1 | ESD3 | ESD7016 | ON Semiconductor | ESD7016MUTAG | Digi-Key | ESD7016MUTAGOSDKR-ND | TVS DIODE 5VWM 10VC 8UDFN |  |  | 1
20 | 5V DC FAN | 1 | FAN1 |  | Sunon Fans | MC30060V2-000U-A99 | Digi-Key | 259-1572-ND | FAN AXIAL 30X6.9MM 5VDC WIRE | NF(FAN1) | 1 | 0
21 | Fiducial | 1 | FL1 | Fiducial_local |  |  |  |  |  |  |  | 1
22 | 600R, 0.27A | 36 | FR1, FR2, FR3, FR4, FR5, FR6, FR7, FR8, FR9, FR10, FR11, FR12, FR13, FR14, FR15, FR16, FR17, FR18, FR19, FR20, FR21, FR24, FR26, FR27, FR28, FR29, FR30, FR31, FR32, FR33, FR34, FR38, FR39, FR40, FR41, FR42 | RES0201 | Taiyo Yuden | BK0603TS601-T | Digi-Key | 587-3277-1-ND | FERRITE BEAD 600 OHM 0201 1LN | NF(FR42) | 1 | 35
23 | 220R, 0.9A | 6 | FR22, FR25, FR35, FR37, FR44, FR45 | RES0402 | TDK Corporation | MPZ1005S221ET000 | Digi-Key | 445-9329-2-ND | FERRITE BEAD 220 OHM 0402 1LN |  |  | 6
24 | 600R, 2A | 2 | FR23, FR36 | RES0805 | TDK Corporation | MPZ2012S601AT000 | Digi-Key | 445-2206-2-ND | FERRITE BEAD 600 OHM 0805 1LN |  |  | 2
25 | LMS7002M | 1 | IC1 | LMS7002M_v5 | Lime Microsystems | LMS7002M | Lime Microsystems | LMS7002M | IC FPRF Transceiver LMS7002M; 261 pin aQFN |  |  | 1
26 | M24128 | 2 | IC2, IC12 | M24128-DFMC6TG | STMicroelectronics | M24128-DFMC6TG | Digi-Key | 497-15739-1-ND | EEPROM Memory IC 128Kb (16K x 8) I²C 1MHz 450ns 8-UFDFPN (2x3) | NF(IC2 IC12) | 2 | 0
27 | SKY13411-374LF | 2 | IC3, IC4 | SKY13411-374LF | Skyworks Solutions Inc. | SKY13411-374LF | Digi-Key | 863-1455-1-ND | RF Switch IC 802.11a/b/g/n DPDT 50 Ohm 6-MLPD (1.5x1.5) |  |  | 2
28 | LD39100PUR | 4 | IC5, IC6, IC13, IC18 | LD39100PUR | STMicroelectronics | LD39100PUR | Digi-Key | 497-11013-1-ND | Linear Voltage Regulator IC Positive Adjustable Output 0.8 V ~ 4.5 V 1A 6-DFN (3x3) |  |  | 4
29 | LFE5U-45F-MG285 | 1 | IC7 | LFE5U-25F-8MG285C_LATTICE_FPGA | Lattice Semiconductor | LFE5U-45F-6MG285C | Digi-Key | LFE5U-45F-6MG285C-ND | series Field Programmable Gate Array (FPGA) IC 118 1990656 44000 285-LFBGA, CSPBGA |  |  | 1
30 | FT601Q | 1 | IC8 | FT601Q | FTDI, Future Technology Devices International Ltd | FT601Q-B-T | Digi-Key | 768-1311-ND | IC USB3-32BIT SYNC FIFO 76QFN |  |  | 1
31 | LMK00105 | 1 | IC9 | LMK00105SQ | Texas Instruments | LMK00105SQ/NOPB | Digi-Key | LMK00105SQ/NOPBCT-ND | IC CLK BUFFER 2:5 200MHZ 24WQFN |  |  | 1
32 | LM75 | 1 | IC10 | HWSON8_LM75 | NXP Semiconductors | LM75BTP,147 | Digi-Key | 568-9815-2-ND | SENSOR TEMPERATURE I2C 8HWSON |  |  | 1
33 | DAC6311IDCK | 1 | IC11 | AD5601_SOT23-6 | Texas Instruments | DAC6311IDCKT | Digi-Key | 296-23716-1-ND | 10 Bit Digital to Analog Converter 1 SC-70-6 |  |  | 1
34 | LMZ20501SILR | 2 | IC14, IC19 | LMZ20501SILR_DC-DC_8-SMD | Texas Instruments | LMZ20501SILR | Digi-Key | 296-40328-1-ND | Non-Isolated PoL Module DC DC Converter 1 Output 0.8 ~ 3.6V 1A 2.7V - 5.5V Input |  |  | 2
35 | W25Q128JVSIQ | 1 | IC15 | S25FL164K_WSON8_DFN6 | Winbond | W25Q128JVSIQ | Digi-Key | W25Q128JVSIQ-ND | FLASH - NOR Memory IC 128Mb (16M x 8) SPI - Quad I/O, QPI, DTR 133 MHz 8-SOIC |  |  | 1
36 | AD5662 | 1 | IC16 | AD5662_SOT23-8 | Analog Devices Inc. | AD5662BRJZ-2REEL7 | Digi-Key | AD5662BRJZ-2REEL7CT-ND | IC DAC 16BIT BUFF V-OUT SOT23-8 | NF(IC16) | 1 | 0
37 | AS431 | 1 | IC17 | SOT23-3_V3 | Diodes | AS431ANTR-G1 | Digi-Key | AS431ANTR-G1DICT-ND | Shunt Voltage Reference IC Adjustable 2.5V 36 VV ±0.5% 100 mA SOT-23-3 | NF(IC17) | 1 | 0
38 | 74LVC1G3157FZ4 | 1 | IC20 | 74LVC1G3157FZ4_SPDT_SW_DFN1410-6 | Diodes | 74LVC1G3157FZ4-7 | Digi-Key | 74LVC1G3157FZ4-7DICT-ND | 1 Circuit IC Switch 2:1 10Ohm X2-DFN1410-6 |  |  | 1
39 | SMA board edge | 2 | J1, J2 | SMA_connector_board_edge_SM | RF Solutions | CON-SMA-EDGE-S | Digi-Key | CON-SMA-EDGE-S-ND | SMA Connector Jack, Female Socket Board Edge, End Launch Solder |  |  | 2
40 | FPGA GPIO | 1 | J3 | SWD_10_pin | Harwin Inc | M50-3600542 | Digi-Key | 952-1389-ND | CONN HDR 1.27MM SMD AU 10POS | NF(J3) | 1 | 0
41 | FPGA EGPIO (board edge) | 1 | J4 | Header5x1_TH_v2 | Amphenol FCI | 69190-405HLF | Digi-Key | 609-4726-ND | 5 Positions Header Connector 0.100" (2.54mm) Through Hole Tin | NF(J4) | 1 | 0
42 | FPGA JTAG (board edge) | 1 | J5 | Header7x1_TH_v2 | Sullins Connector Solutions | PEC07SAAN | Digi-Key | S1012E-07-ND | 7 Positions Header, Unshrouded, Breakaway Connector 0.100" (2.54mm) Through Hole Tin | NF(J5) | 1 | 0
43 | USB3.0_MALE | 1 | J6 | USB3A_SM | Wurth Electronics Inc. | 692112030100 | Digi-Key | 732-3157-ND | USB - A USB 3.0 (USB 3.1 Gen 1, Superspeed) Plug Connector 9 Position Surface Mount, Right Angle |  |  | 1
44 | U.FL/MMCX | 2 | J7, J8 | MMCX_UFL_conn_u | Molex, LLC | 0734120110 | Digi-Key | WM5587CT-ND | Ultra Miniature Coaxial Connector Receptacle, Male Pin 50 Ohm Surface Mount Solder |  |  | 2
45 | FAN | 1 | J9 | Header2x1_TH_v2 | 3M | 961102-6404-AR | Digi-Key | 3M9447-ND | 2 Positions Header, Unshrouded Connector 0.100" (2.54mm) Through Hole Gold | NF(J9) | 1 | 0
46 | LED_RG | 3 | LED1, LED2, LED3 | LED-2x0603 | Avago Technologies US Inc. | HSMF-C165 | Digi-Key | 516-1419-1-ND | LED GREEN/RED DIFFUSED 0603 SMD |  |  | 3
47 | RFI Shield | 3 | MECH1, MECH10, MECH15 | WurthElectronic_RF_shield | WURTH ELEKTRONIK | 36003250 | Farnell | 1909662 | Enclosure, Shielding Cabinet Cover, Shielding Cabinet, 25 mm, 25 mm, 3 mm, Tin Plate | NF(MECH1 MECH15) | 2 | 1
48 | RFI Shield clip | 12 | MECH2, MECH3, MECH4, MECH5, MECH6, MECH7, MECH8, MECH9, MECH11, MECH12, MECH13, MECH14 | RFI_SHIELD_CLPS_MINI | HARWIN | S0971-46R | Farnell | 2361677 | RFI SHIELD CLIP MINI TIN SMD | NF(MECH2 MECH3 MECH4 MECH5 MECH11 MECH12 MECH13 MECH14) | 8 | 4
49 | Spacer M3 | 2 | MECH16, MECH17 |  | BOSSARD | TDYSFF-M3/5 | TME | TDYSFF-M3/5 | Screwed spacer sleeve; Int.thread: M3; 5mm; brass | NF(MECH16 MECH17) | 2 | 0
50 | Screws M3 v1 | 2 | MECH18, MECH19 |  | KRAFTBERG | M3X3/D7985 | TME | M3X3/D7985 | Screw; M3x3; DIN:7985; Head: cheese head; Phillips; steel; zinc; PH1 | NF(MECH18 MECH19) | 2 | 0
51 | Screws M3 v2 | 2 | MECH20, MECH21 |  | KRAFTBERG | M3X8/D7985B | TME | M3X8/D7985B | Screw; M3x8; DIN:7985; Head: cheese head; Phillips; black finish | NF(MECH20 MECH21) | 2 | 0
52 | 8.2nH, 5% | 3 | MN1, MN2, MN22 | RES0402 | COILCRAFT | 0402HP-8N2XJLU | Farnell | 2285826 | Surface Mount High Frequency Inductor, 0402HP Series, 8.2 nH, ± 5%, 0402 [1005 Metric], 5.4 GHz | NF(MN22) | 1 | 2
53 | 100uH | 2 | MN3, MN17 | RES0805_0603 | TDK Corporation | MLF2012C101KT000 | Digi-Key | 445-1071-1-ND | FIXED IND 100UH 2MA 3.1 OHM SMD | NF(MN3 MN17) | 2 | 0
54 | 0.8pF | 2 | MN4, MN7 | CAP0402 | Murata Electronics North America | GRM1555C1HR80BA01D | Digi-Key | 490-6269-1-ND | 0.80pF ±0.1pF 50V C0G, NP0 Ceramic Capacitor -55°C ~ 125°C Surface Mount, MLCC 0402 (1005 Metric) 0.039" L x 0.020" W (1.00mm x 0.50mm) |  |  | 2
55 | 1pF | 3 | MN5, MN13, MN19 | CAP0402 | TDK Corporation | C1005C0G1H010B050BA | Digi-Key | 445-4854-6-ND | 1pF ±0.1pF 50V C0G, NP0 Ceramic Capacitor -55°C ~ 125°C Surface Mount, MLCC 0402 (1005 Metric) 0.039" L x 0.020" W (1.00mm x 0.50mm) | NF(MN5 MN13) | 2 | 1
56 | 0.5pF | 2 | MN6, MN18 | CAP0402 | Yageo | CC0402CRNPO9BNR50 | Digi-Key | 311-1001-1-ND | 0.50pF ±0.25pF 50V C0G, NP0 Ceramic Capacitor -55°C ~ 125°C Surface Mount, MLCC 0402 (1005 Metric) 0.039" L x 0.020" W (1.00mm x 0.50mm) | NF(MN18) | 1 | 1
57 | 100uH | 2 | MN8, MN9 | RES0805 | TDK Corporation | MLF2012C101KT000 | Digi-Key | 445-1071-1-ND | FIXED IND 100UH 2MA 3.1 OHM SMD |  |  | 2
58 | 0R | 31 | MN10, MN11, R14, R15, R20, R21, R26, R27, R32, R34, R35, R36, R37, R42, R43, R44, R45, R46, R53, R61, R65, R66, R69, R78, R90, R94, R96, R98, R100, R101, R102 | RES0402 | Yageo | RC0402JR-070RL | Digi-Key | 311-0.0JRTR-ND | RES SMD 0.0OHM JUMPER 1/16W 0402 | NF(R14 R15 R20 R21 R26 R43 R66 R78 R96 R100 R101 R102) | 12 | 19
59 | 2pF | 3 | MN14, MN16, MN20 | CAP0402 | AVX | 04025U2R0BAT2A | Farnell | 2332536 | SMD Multilayer Ceramic Capacitor, U Series, 2 pF, ± 0.1pF, C0G / NP0, 50 V, 0402 [1005 Metric] |  |  | 3
60 | 1.2pF | 1 | MN23 | CAP0402 | Murata Electronics North America | GRM1555C1H1R2CA01D | Digi-Key | 490-5927-1-ND | '1.2pF ±0.25pF 50V C0G, NP0 Ceramic Capacitor -55°C ~ 125°C Surface Mount, MLCC 0402 (1005 Metric) 0.039" L x 0.020" W (1.00mm x 0.50mm) |  |  | 1
61 | 2k2, 1% | 2 | R1, R2 | RES0402 | Stackpole Electronics Inc | RMCF0402FT2K20 | Digi-Key | RMCF0402FT2K20CT-ND | RES SMD 2.2K OHM 1% 1/16W 0402 |  |  | 2
62 | 10k, 1% | 20 | R3, R4, R5, R6, R7, R12, R13, R39, R54, R55, R56, R58, R62, R71, R73, R74, R77, R83, R84, R86 | RES0402 | Yageo | RC0402FR-0710KL | Digi-Key | 311-10.0KLRTR-ND | RES SMD 10K OHM 1% 1/16W 0402 | NF(R71 R83) | 2 | 18
63 | 49.9R, 1% | 7 | R8, R9, R10, R11, R22, R23, R67 | RES0402 | Samsung Electro-Mechanics America, Inc. | RC1005F49R9CS | Digi-Key | 1276-3469-6-ND | RES SMD 49.9 OHM 1% 1/16W 0402 |  |  | 7
64 | 560R, 1% | 1 | R16 | RES0402 | Vishay Dale | CRCW0402560RFKED | Digi-Key | 541-560LCT-ND | RES SMD 560 OHM 1% 1/16W 0402 | NF(R16) | 1 | 0
65 | 100R, 1% | 9 | R17, R24, R25, R85, R87, R92, R95, R97, R99 | RES0402 | Stackpole Electronics Inc. | RMCF0402FT100R | Digi-Key | RMCF0402FT100RDKR-ND | RES SMD 100 OHM 1% 1/16W 0402 | NF(R17 R24) | 2 | 7
66 | 2.49k, 1% | 1 | R18 | RES0402 | Yageo | RC0402FR-072K49L | Digi-Key | 311-2.49KLRDKR-ND | RES SMD 2.49K OHM 1% 1/16W 0402 |  |  | 1
67 | 1k, 1% | 6 | R19, R63, R68, R70, R75, R81 | RES0402 | Stackpole Electronics Inc | RMCF0402FT1K00 | Digi-Key | RMCF0402FT1K00TR-ND | RES SMD 1K OHM 1% 1/16W 0402 | NF(R19 R63 R81) | 3 | 3
68 | 10R | 4 | R28, R29, R40, R41 | RES0201 | Panasonic Electronic Components | ERJ-1GEF10R0C | Digi-Key | P10.0ABCT-ND | RES SMD 10 OHM 1% 1/20W 0201 |  |  | 4
69 | 0R | 1 | R30 | RES0201 | Rohm Semiconductor | RC0201FR-070RL | Digi-Key | 311-0.0MCT-ND | RES SMD 0.0OHM JUMPER 1/20W 0201 |  |  | 1
70 | 8.2k, 1% | 1 | R31 | RES0402 | Yageo | RC0402FR-078K2L | Digi-Key | 311-8.20KLRCT-ND | RES SMD 8.2K OHM 1% 1/16W 0402 |  |  | 1
71 | 15k, 1% | 1 | R33 | RES0402 | Yageo | RC0402FR-0715KL | Digi-Key | 311-15.0KLRCT-ND | RES SMD 15K OHM 1% 1/16W 0402 |  |  | 1
72 | 7.5k, 1% | 1 | R38 | RES0402 | Yageo | RC0402FR-077K5L | Digi-Key | YAG3512CT-ND | ±1% 0.063W, 1/16W Chip Resistor 0402 (1005 Metric) Automotive AEC-Q200, Moisture Resistant Thick Film |  |  | 1
73 | 4K7, 1% | 9 | R47, R48, R49, R50, R51, R52, R57, R89, R93 | RES0402 | Yageo | RC0402FR-074K7L | Digi-Key | 311-4.7KLRCT-ND | ±1% 0.063W, 1/16W Chip Resistor 0402 (1005 Metric) Moisture Resistant Thick Film | NF(R93) | 1 | 8
74 | 22R | 2 | R59, R64 | RES0402 | Yageo | RC0402FR-0722RL | Digi-Key | 311-22.0LRTR-ND | RES SMD 22 OHM 1% 1/16W 0402 |  |  | 2
75 | 1k6, 1% | 1 | R60 | RES0402 | Yageo | RC0402FR-071K6L | Digi-Key | YAG3045CT-ND | RES SMD 1.6K OHM 1% 1/16W 0402 |  |  | 1
76 | 3k, 1% | 2 | R72, R76 | RES0402 | Vishay Dale | RMCF0402FT3K00 | Digi-Key | RMCF0402FT3K00TR-ND | RES SMD 3K OHM 1% 1/16W 0402 | NF(R76) | 1 | 1
77 | 80.6k, 1% | 1 | R79 | RES0402 | Stackpole Electronics | RMCF0402FT80K6 | Digi-Key | RMCF0402FT80K6CT-ND | 80.6 kOhms ±1% 0.063W, 1/16W Chip Resistor 0402 (1005 Metric) Automotive AEC-Q200 Thick Film |  |  | 1
78 | 27k, 1% | 1 | R80 | RES0402 | Yageo | RC0402FR-0727KL | Digi-Key | 311-27.0KLRCT-ND | 27 kOhms ±1% 0.063W, 1/16W Chip Resistor 0402 (1005 Metric) Moisture Resistant Thick Film |  |  | 1
79 | 40.2k, 1% | 1 | R82 | RES0402 | Yageo | RC0402FR-0740K2L | Digi-Key | 311-40.2KLRCT-ND | 40.2 kOhms ±1% 0.063W, 1/16W Chip Resistor 0402 (1005 Metric) Moisture Resistant Thick Film |  |  | 1
80 | 237k, 1% | 1 | R88 | RES0402 | Yageo | RC0402FR-07237KL | Digi-Key | YAG3064CT-ND | 237 kOhms ±1% 0.063W, 1/16W Chip Resistor 0402 (1005 Metric) Moisture Resistant Thick Film |  |  | 1
81 | 52.3k, 1% | 1 | R91 | RES0402 | Panasonic | ERJ-2RKF5232X | Mouser | 667-ERJ-2RKF5232X | Thick Film Resistors - SMD 0402 52.3Kohms 1% AEC-Q20 |  |  | 1
82 | Solder bridge | 4 | SB1, SB2, SB3, SB4 | SOLDER_BRIDGE_TRIANGULAR_v2 | Yageo | RC0402JR-070RL | Digi-Key | 311-0.0JRTR-ND | RES SMD 0.0OHM JUMPER 1/16W 0402 |  |  | 4
83 | TC1-1-13M-45+ | 4 | T1, T2, T3, T4 | TC1-1-13MA+_JA4220-AL_ | Minicircuits | TC1-1-13M-45+ | Minicircuits | TC1-1-13M-45+ | RF balun; 1:1 ratio; 3 dB bandwidth: 0.3 MHz to 3.5 GHz; 3.8mm x 3.8mm |  |  | 4
84 | ZVN4525E6TA | 3 | VT1, VT2, VT3 | ZVN4525E6_NMOS_SOT23-6 | Diodes Zetex | ZVN4525E6TA | Digi-Key | 31-ZVN4525E6TACT-ND | N-Channel 250 V 230mA (Ta) 1.1W (Ta) Surface Mount SOT-23-6 | NF(VT1 VT2) | 2 | 1
85 | IRLML6244TRPBF | 1 | VT4 | SOT23-3 | Infineon Technologies | IRLML6244TRPBF | Digi-Key | IRLML6244TRPBFTR-ND | N-Channel 20V 6.3A (Ta) 1.3W (Ta) Surface Mount Micro3™/SOT-23 |  |  | 1
86 | E7355LF, 40MHz, w VC | 1 | XO1 | RAKON_RTX5032A | Rakon | E7355LF | RAKON | E7355LF | E7355LF 40MHz, High performance TCXO, With VC, 6-pin 5mm x 3.2 mm x 2.1 mm package |  |  | 1
87 | 30MHz | 1 | XT1 | CRYSTAL_4-LCC | AVX Corp/Kyocera Corp | CX3225SB30000D0FPLCC | Digi-Key | 1253-1368-1-ND | 30MHz ±10ppm Crystal 8pF 50 Ohm -40°C ~ 85°C Surface Mount 4-SMD, No Lead (DFN, LCC) |  |  | 1
 |  |  |  |  |  |  |  |  |  |  |  | Total NF element number: 76
 |  |  |  |  |  |  |  |  |  |  |  | All NF elements in one row:
 |  |  |  |  |  |  |  |  |  |  |  | NF(C194 C7 C19 C20 C22 C71 C84 C192 C6 C21 C174 C180 C183 C186 C158 C160 C157 C184 ESD1 ESD2 FAN1 FR42 IC2 IC12 IC16 IC17 J3 J4 J5 J9 MECH1 MECH15 MECH2 MECH3 MECH4 MECH5 MECH11 MECH12 MECH13 MECH14 MECH16 MECH17 MECH18 MECH19 MECH20 MECH21 MN22 MN3 MN17 MN5 MN13 MN18 R14 R15 R20 R21 R26 R43 R66 R78 R96 R100 R101 R102 R71 R83 R16 R17 R24 R19 R63 R81 R93 R76 VT1 VT2)
 |  |  |  |  |  |  |  |  |  |  |  | *NOTE: NF(R1 R2) means that elements R1 and R2 are unpopulated (NF)

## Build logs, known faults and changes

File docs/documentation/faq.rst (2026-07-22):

FAQ
================

In this section you can find frequently asked questions related to LimeSDR-Mini v2.2 board

It is not working, please help.
--------------------------------------

Avoid vague explanation of encountered issues. Try to provide as many relevant information as you can, for e.g:

* What hardware are you using? Write exact board name and version as you see on silkscreen. 
* What software and version are you using?
* What gateware version are you using? 
* Was it working before? 
* Did you modified hardware, software or gateware? If so explain your modifications. 
* Provide steps to reproduce the issue. 

Where can I ask for help or report issues?
------------------------------------------

* First read this FAQ and go trough available documents in `https://limesdr-mini.myriadrf.org/ <https://limesdr-mini.myriadrf.org/>`__
* Try to search `https://discourse.myriadrf.org/ <https://discourse.myriadrf.org/>`__ maybe someone already had similar issue, if not - post your question there.
* For HW related issues check `LimeSDR-Mini-v2 <https://github.com/myriadrf/LimeSDR-Mini-v2/issues>`__ GitHub repository. 
* For GW related issues check `LimeSDR-Mini-v2_GW <https://github.com/myriadrf/LimeSDR-Mini-v2_GW/issues>`__ GitHub repository. 
* For SW related issues check `LimeSuite <https://github.com/myriadrf/LimeSuite/issues>`__ GitHub repository

How to configure FT601 USB3.0 chip?
-----------------------------------
* Download `FT600ChipConfigurationProgUtility_v1.3.0.10.zip <https://ftdichip.com/wp-content/uploads/2025/02/FT600ChipConfigurationProgUtility_v1.3.0.10.zip>`__ , connect board and hit "Read Configuration" (make sure that any other software is closed and is not using the board). You should see following settings:

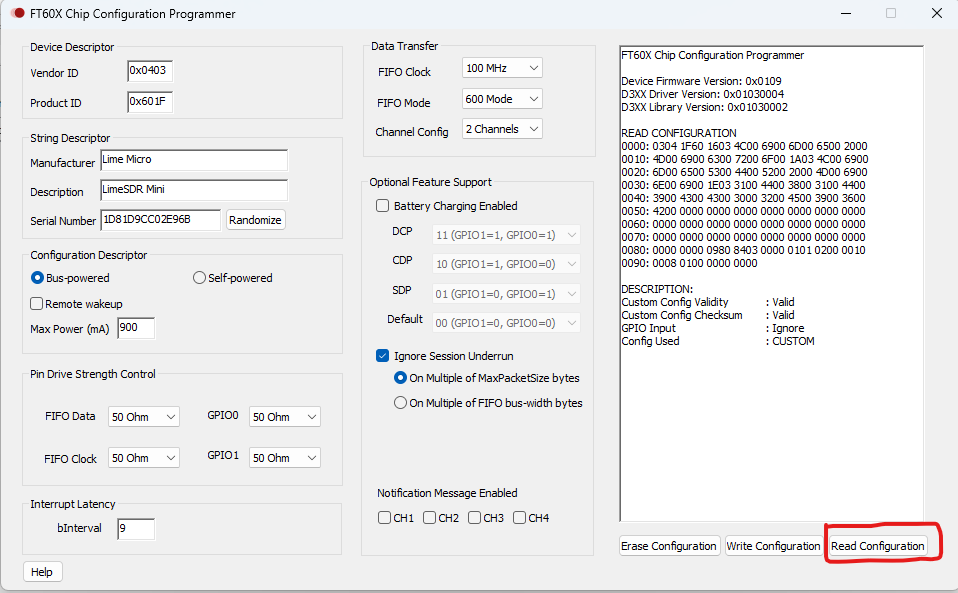
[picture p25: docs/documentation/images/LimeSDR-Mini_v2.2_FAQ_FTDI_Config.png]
    
  
    Figure 1: FTDI configuration

    Ignore "Serial number" field. If any other setting are incorrect fix them and hit "Write Configuration". Close utility and try to connect board to LimeSuite GUI. 

I cannot connect board to LimeSuite GUI, no LEDs are blinking how can I recover my board?  
----------------------------------------------------------------------------------------- 

* Try using a different USB 3.0 cable or connect the device directly to a USB 3.0 port. The use of low-quality USB 3.0 cables and USB 3.0 hubs may result in power-related issues.

* Check FT601 chip configuration, see `How to configure FT601 USB3.0 chip?`_ .

* Reprogram FPGA FLASH memory using JTAG with latest GW `lms7_trx_impl1_dualboot.mcs <https://github.com/myriadrf/LimeSDR-Mini-v2_GW/blob/main/LimeSDR-Mini_bitstreams/lms7_trx_impl1_dualboot.mcs>`__ file. Check `JTAG programming <https://limesdr-mini.myriadrf.org/documentation/jtag-programming#>`__ page and  follow `FPGA FLASH programming <https://limesdr-mini.myriadrf.org/documentation/jtag-programming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>`__ procedure.

* If FLASH programming was successful you should see blinking LED1 after reapplying power to board. 

* If after fixing FTDI configuration and reprogramming FPGA FLASH you still cannot connect to LimeSuite GUI this would indicate problems with software setup that you are using or board is damaged.

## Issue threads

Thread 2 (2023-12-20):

My recently arrived boad not pass quick test

mirecta, 2023-12-20:
I build limesuite
```
git clone https://github.com/myriadrf/LimeSuite.git
cd LimeSuite
git checkout stable
mkdir builddir && cd builddir
cmake ../
make -j4
sudo make install
sudo ldconfig
```
and then try test

```
/LimeQuickTest
[ TESTING STARTED ]
->Start time: Wed Dec 20 12:24:07 2023
->LimeSuite version: 22.09.0-ge829d3ed

->Device: LimeSDR Mini, media=USB 3.0, module=FT601, addr=24607:1027, serial=1DA183895869C5, HW=7, GW=2.6
  Serial Number: 1DA183895869C5
 Chip temperature: 50 C

[ Clock Network Test ]
->REF clock test
  Test results: 26881; 28424; 29905 - PASSED
->VCTCXO test
  Results : 6711003 (min); 6711037 (max) - FAILED
  FAILED
->Clock Network Test FAILED

[ FPGA EEPROM Test ]
->Read EEPROM
Operation failed: error code 5
->FPGA EEPROM Test FAILED

[ LMS7002M Test ]
->Perform Registers Test
->External Reset line test
  Reg 0x20: Write value 0xFFFD, Read value 0xFFFD
  Reg 0x20: value after reset 0x0FFFF
->LMS7002M Test PASSED

[ RF Loopback Test ]
->Configure LMS
->Run Tests (TX_2 -> LNA_W):
  CH0 (SXR=1000.0MHz, SXT=1005.0MHz): Result:(-28.4 dBFS, 5.00 MHz) - FAILED
->Run Tests (TX_1 -> LNA_H):
  CH0 (SXR=2100.0MHz, SXT=2105.0MHz): Result:(-25.3 dBFS, 5.00 MHz) - FAILED
->RF Loopback Test FAILED

=> Board tests FAILED <=

Elapsed time: 1.38 seconds
```
what can i do now ??

9600, 2023-12-20:
> git checkout stable

Don't use stable. Checkout and build tag v23.11.0 instead.

mirecta, 2023-12-20:
> > git checkout stable
>
> Don't use stable. Checkout and build tag v23.11.0 instead.

Than u so much now it seems to be ok
```
[ TESTING STARTED ]
->Start time: Wed Dec 20 12:38:14 2023
->LimeSuite version: 23.11.0-gc2d9e877

->Device: LimeSDR Mini, media=USB 3.0, module=FT601, addr=24607:1027, serial=1DA183895869C5, HW=7, GW=2.6
  Serial Number: 1DA183895869C5
 Chip temperature: 48 C

[ Clock Network Test ]
->REF clock test
  Test results: 24958; 26495; 27976 - PASSED
->VCTCXO test
  Results : 6711003 (min); 6711038 (max) - PASSED
->Clock Network Test PASSED

[ FPGA EEPROM Test ]
->Read EEPROM
FPGA EEPROM not supported in v2
->FPGA EEPROM Test PASSED

[ LMS7002M Test ]
->Perform Registers Test
->External Reset line test
  Reg 0x20: Write value 0xFFFD, Read value 0xFFFD
  Reg 0x20: value after reset 0x0FFFF
->LMS7002M Test PASSED

[ RF Loopback Test ]
->Configure LMS
->Run Tests (TX_2 -> LNA_W):
  CH0 (SXR=1000.0MHz, SXT=1005.0MHz): Result:(-28.2 dBFS, 5.00 MHz) - PASSED
->Run Tests (TX_1 -> LNA_H):
  CH0 (SXR=2100.0MHz, SXT=2105.0MHz): Result:(-25.1 dBFS, 5.00 MHz) - PASSED
->RF Loopback Test PASSED

=> Board tests PASSED <=

Elapsed time: 1.37 seconds
```
but it cant see my device in gqrx can u give me some advice ?

9600, 2023-12-20:
> but it cant see my device in gqrx can u give me some advice ?

Afraid not. You'd be best asking in the Gqrx community and you could also post on the MyriadRF forums.

https://discourse.myriadrf.org/

Since the tests are passing I'm now closing this issue.

mirecta, 2023-12-20:
yes thank you so much

Closed 2023-12-20.

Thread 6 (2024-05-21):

Solid green light and no USB Enumeration

scj643, 2024-05-21:
I was using my LimeSDR Mini yesterday and it was working fine and this morning I went to use it and now it's not enumerating and has a solid green LED. It does not even show up in dmesg when plugged in. I have tried multiple USB ports with no luck.

9600, 2024-05-22:
Hello,

Support is provided via the MyriadRF forums and if you could please post there, then someone could take a look. This issue tracker is just for hardware design related issues.

https://discourse.myriadrf.org/

Closed 2024-05-22.

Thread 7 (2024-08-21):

schematic clock diagram error

314analytics, 2024-08-21:
Page 3 (clock diagram) of the schematic shows MCLK1/MCLK2 (AB34/P34) as LMS7002M inputs and FCLK1/FCLK2 (AA33/R29) as LMS7002M outputs.

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

This is opposite what is documented in the current LMS7002M datasheet (3.1r00) for these pins.

Perhaps the v2.4 schematic fixed this error, but per #5, this has not been uploaded.

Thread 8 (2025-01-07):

Have you considered using emulated RISC-V cores on something like the icesugar instead of closed FPGAs with ARM cores?

HomingHamster, 2025-01-07:
I am not a professional embedded developer, but I would really like to see an SDR that is totally open hardware, where the sand to silicone knowledge is available to all. One way to do this might be to use an emulated open core for the FPGA rather than arm or closed FPGAs. Some links, repositories, videos and, inspiration are available here https://circuspam.coffee/2024/12/29/entirely-self-soverign-48mhz-open-source-linux-computer-with-wifi-networking/

9600, 2025-01-07:
That won't give you "sand to silicone" openness.

And in any case, LimeSDR Mini 2.0 doesn't use an Arm processor and already has a soft core. See the gateware project for details.

Closed 2025-01-07.

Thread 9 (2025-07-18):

GPIO stopped working

oe1rsa, 2025-07-18:
I am working on a project using Lime Mini v2 and was using GPIO pins, whcih was working fine. After a longer pause (last use 2023) I am restarting and found GPIO is no longer working.

I.e. I can only read data, but not write.

My device info from  Lime Suite GUI:

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

Neither with limesuite Gui, nor limesuiteng api nor old limesuite can I write to the pins.

What should I check next?

vbuitvydas, 2025-07-24:
Hi @oe1rsa do you happen to remember if you updated the GW version since it was working?

vbuitvydas, 2025-07-24:
I have checked latest original GW 2.7 since you are using 2.2:
  https://github.com/myriadrf/LimeSDR-Mini-v2_GW/blob/main/LimeSDR-Mini_bitstreams/lms7_trx_impl1.bit

GPIO control is working from GW perspective. You can check this by manually setting FPGA registers  on LimeSuite GUI **Modules->SPI -> Board SPI:**

- Override all GPIO - set FPGA register 0x00C0=FF,
- Set all GPIO to autput - 0x00C4=00FF
- Set all GPIO to low level 0x00C6=0000
 It will override all gpio with user values, set it to output and all gpio to low level value. Since GPIO[7:4] are shared with  LED you will see LED2 and LED3 will light up. If you set 0x00C6=00FF, LED2 and LED3 will go off.

I think what you are seeing is that software is not overriding GPIO control by default and FPGA registers by default is set to allow user to control only GPIO[3:0], other GPIO[7:4] have a dedicated function since they are shared with LEDs to indicate TX/RX activity. Early GW versions did not have dedicated functions and by default all GPIO can be controlled by user.

Let me know if you still have issues with GPIO control. In that case give me steps to replicate your issue.

Regards,
Vytautas

oe1rsa, 2025-07-24:
PS.: The output of limeDevice -f now reads:

```
0: LimeSDR Mini, addr=0403:601f, serial=1D90F96D64EBD4
	Expansion name		: UNSUPPORTED
	Firmware version	: 10
	Gateware version	: 2
	Gateware revision	: 7
	Gateware target board	: LimeSDR-Mini
	Hardware version	: 5
	Protocol version	: 1
	Serial number		: 8322175281195988
	SPI slave devices	:
				  FPGA
				  LMS7002M
	Memory devices		:
				  FPGA/FLASH
	GPS Lock:
		GPS - Undefined
		Glonass - Undefined
		Galileo - Undefined
		Beidou - Undefined

```

Still woondering what Firware versus Gateware is? Can ynyoine pls point me to a place where I can read about it?

9600, 2025-07-24:
If you could please post these and any further questions to the forums:

  https://discourse.myriadrf.org

The issue trackers should just be used for raising issues.

Closed 2025-07-24.

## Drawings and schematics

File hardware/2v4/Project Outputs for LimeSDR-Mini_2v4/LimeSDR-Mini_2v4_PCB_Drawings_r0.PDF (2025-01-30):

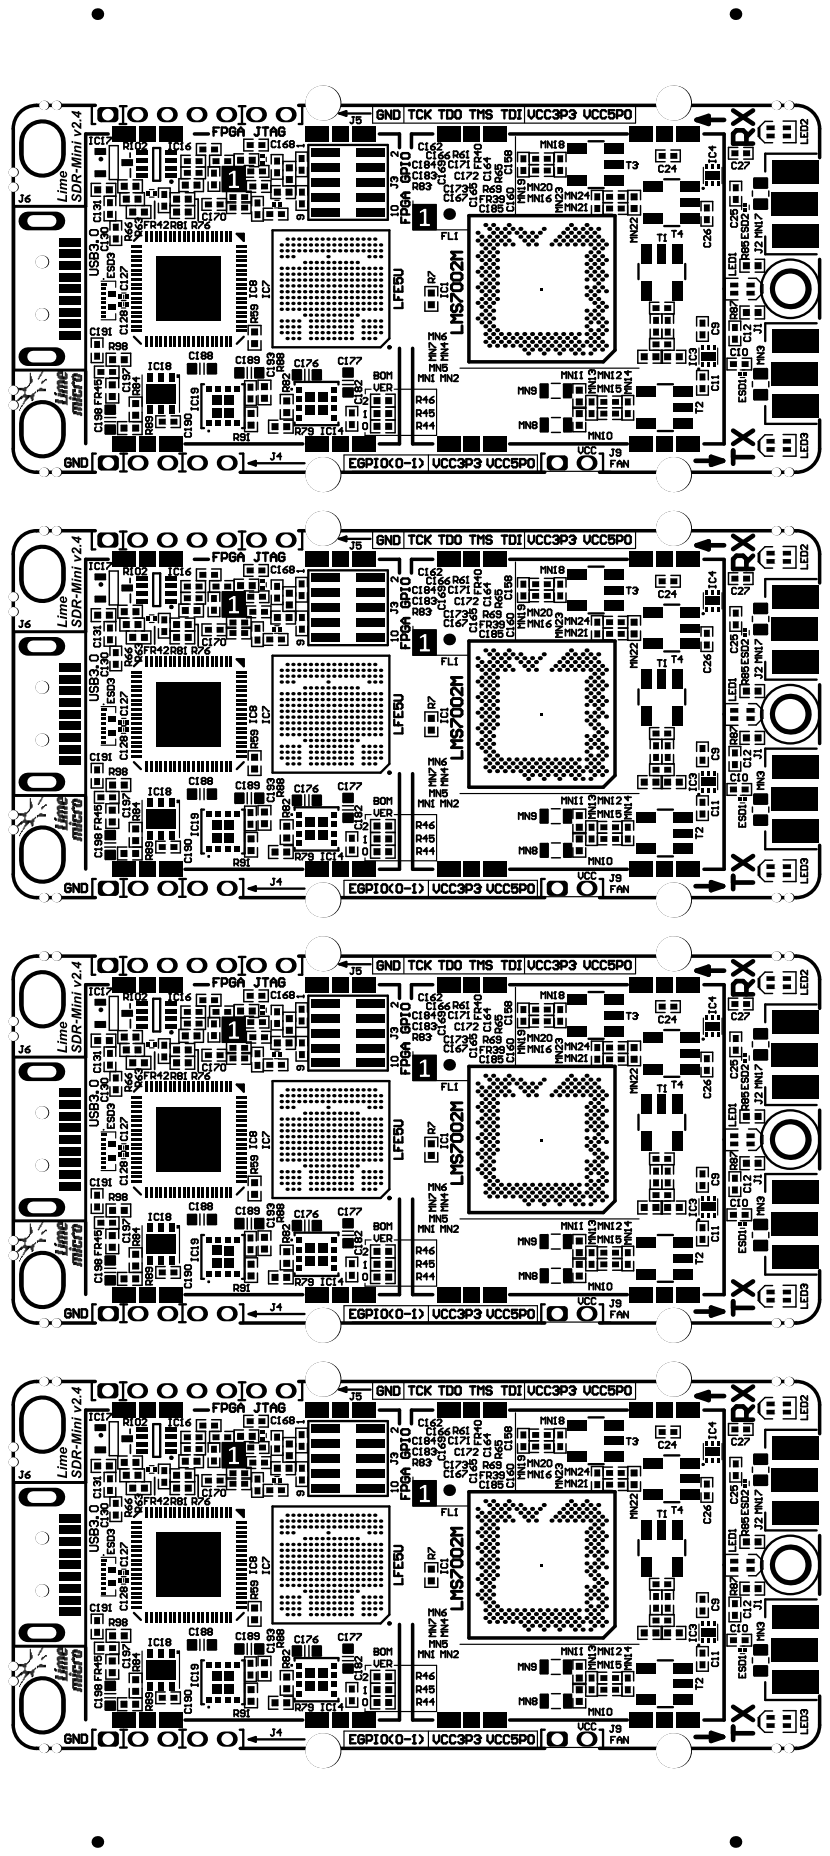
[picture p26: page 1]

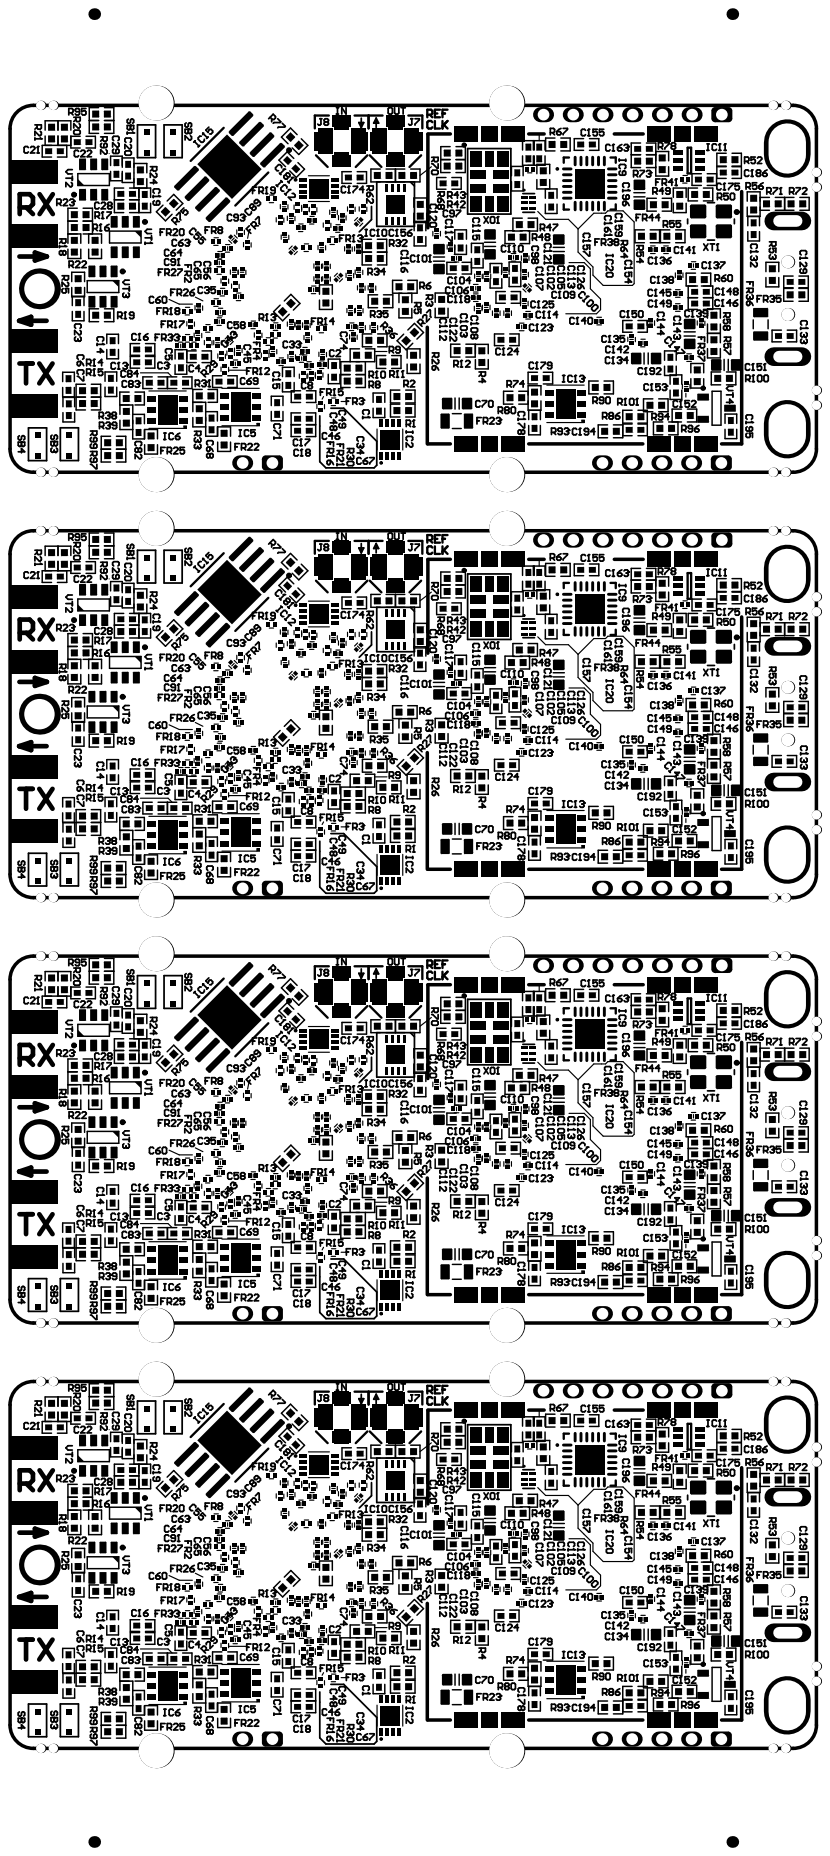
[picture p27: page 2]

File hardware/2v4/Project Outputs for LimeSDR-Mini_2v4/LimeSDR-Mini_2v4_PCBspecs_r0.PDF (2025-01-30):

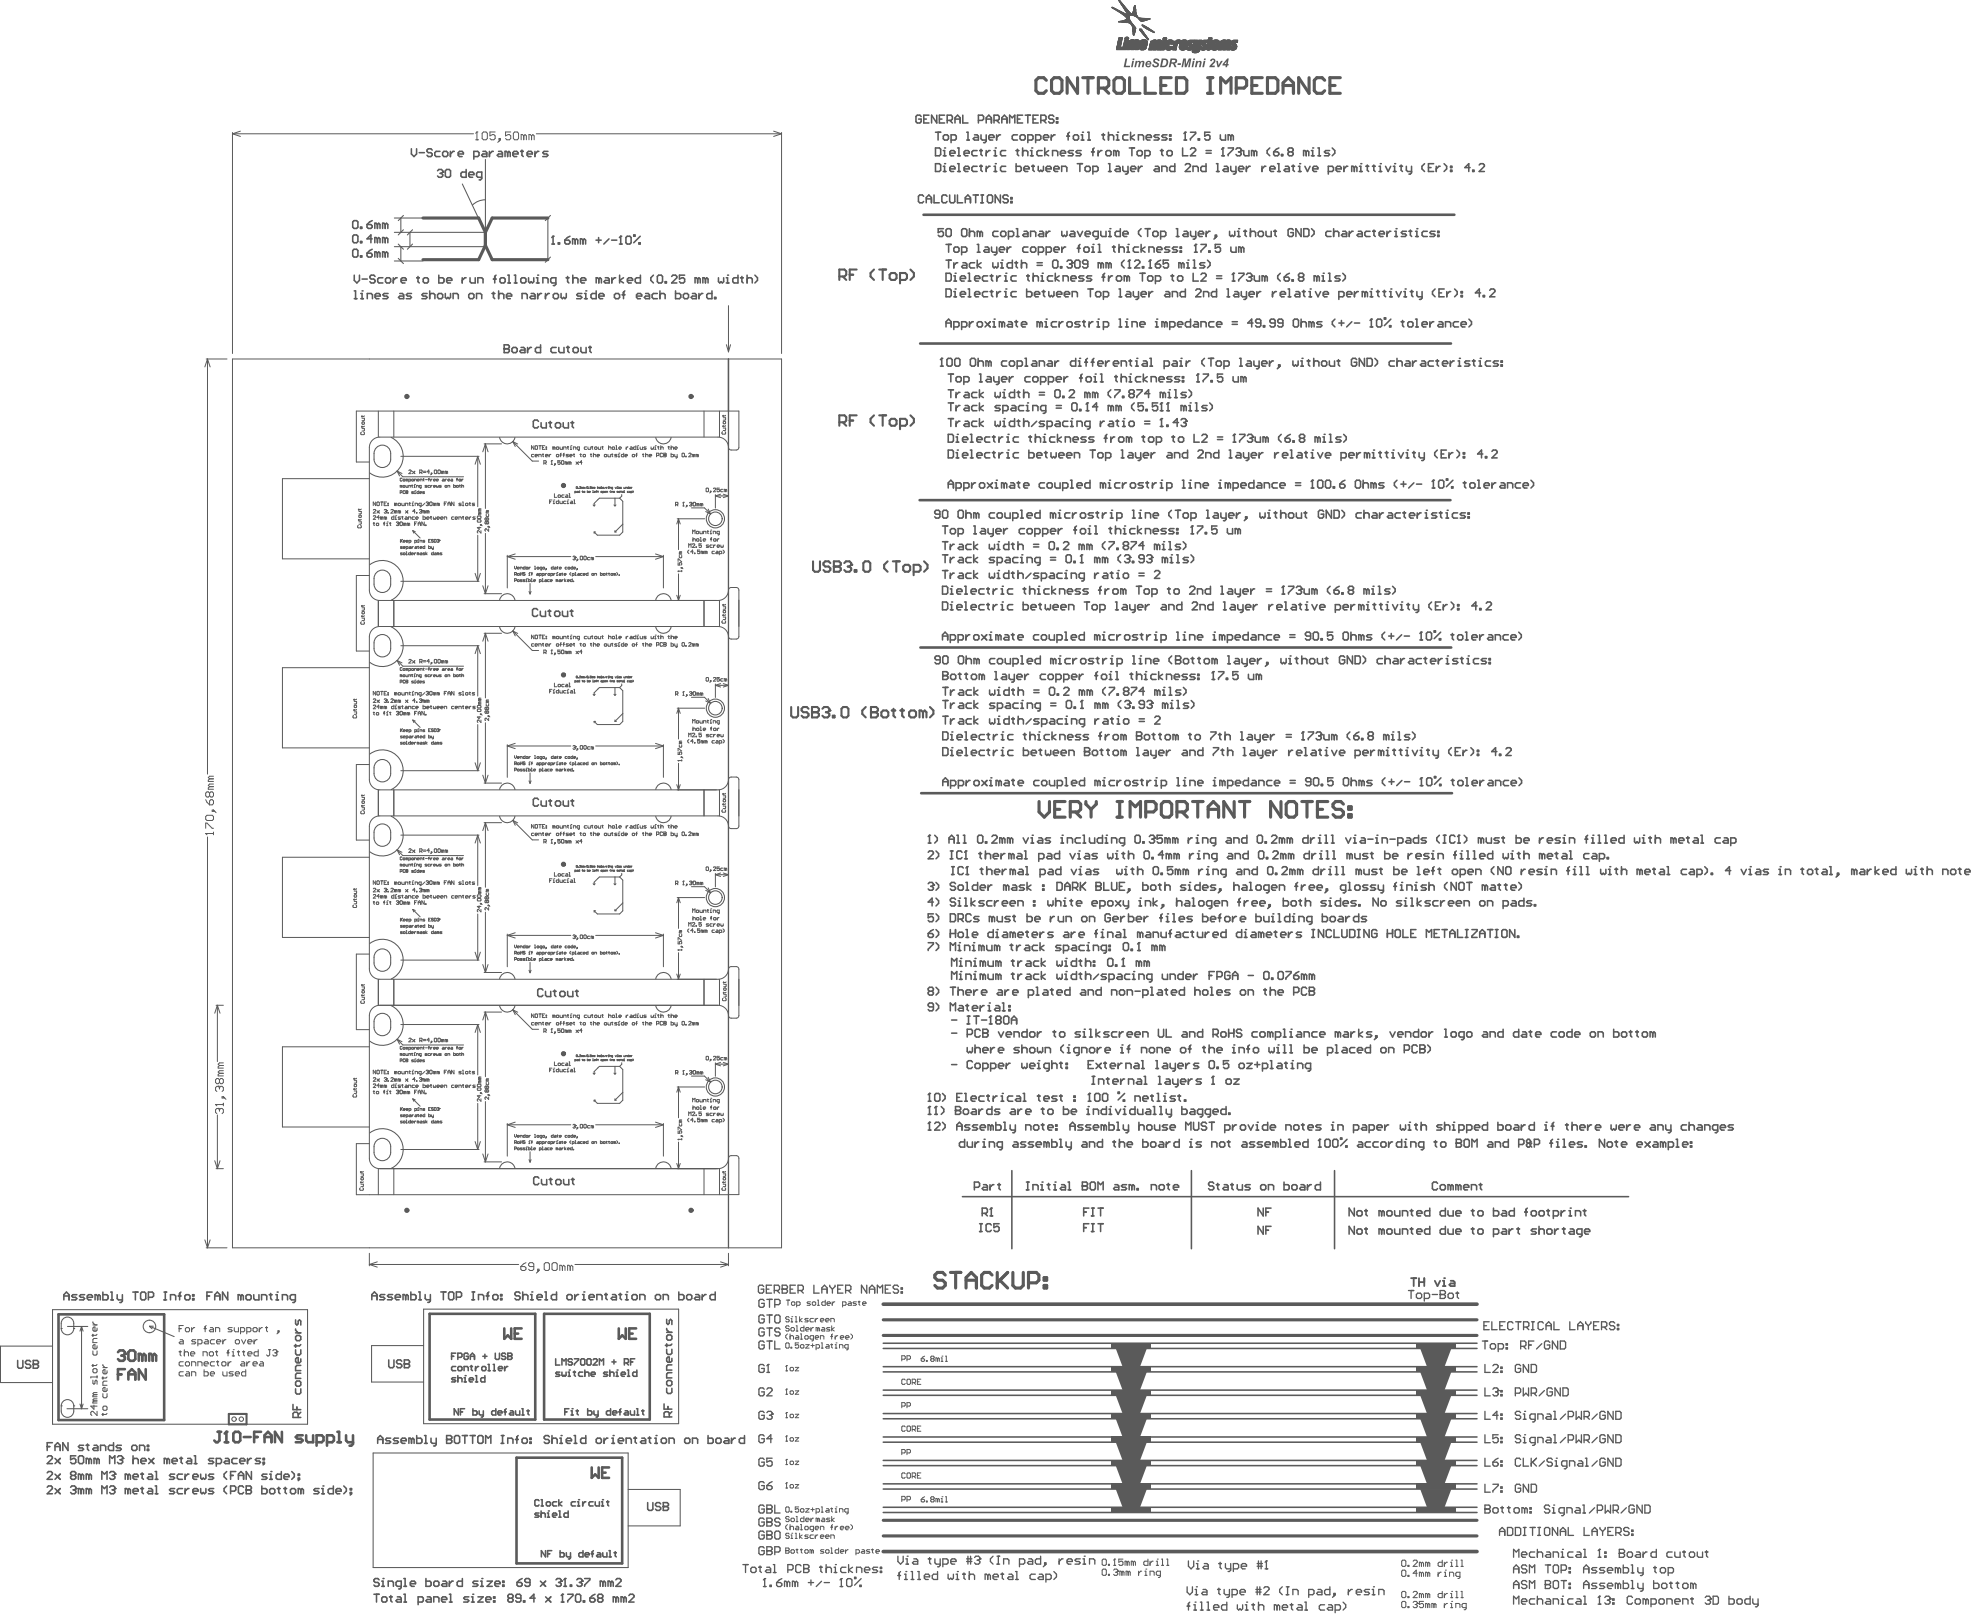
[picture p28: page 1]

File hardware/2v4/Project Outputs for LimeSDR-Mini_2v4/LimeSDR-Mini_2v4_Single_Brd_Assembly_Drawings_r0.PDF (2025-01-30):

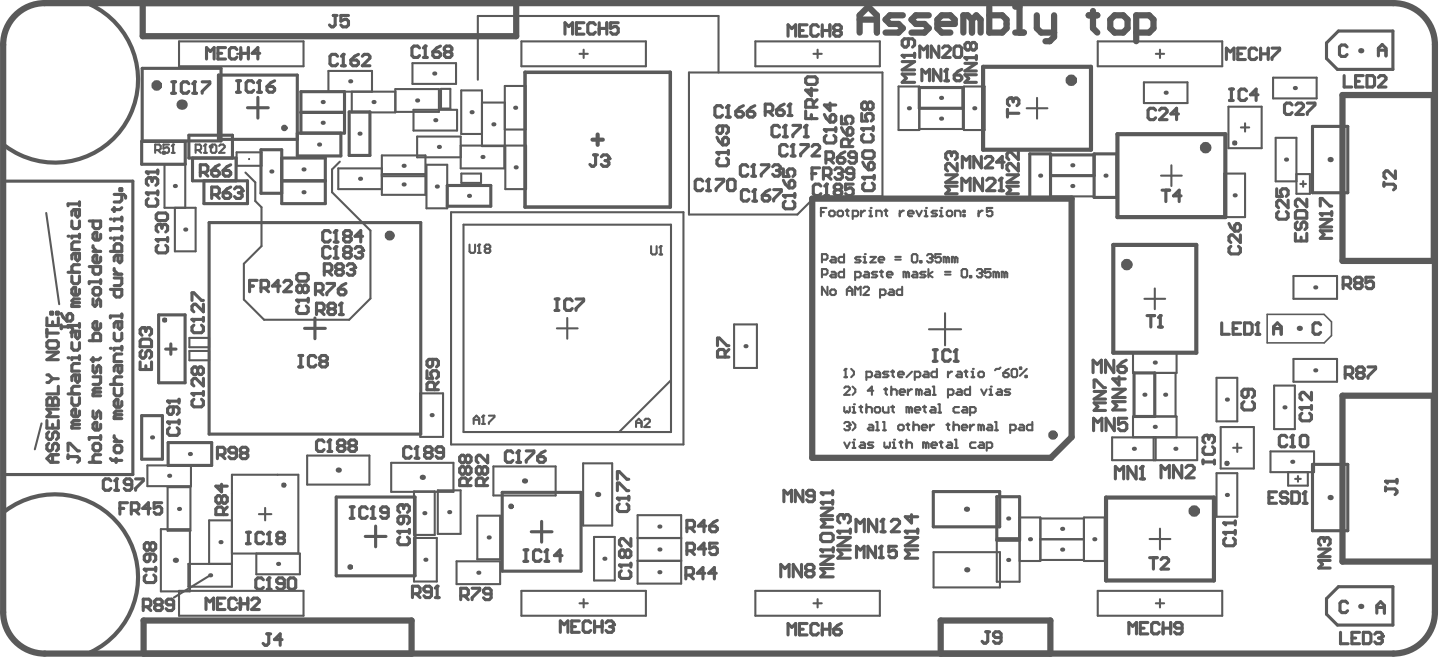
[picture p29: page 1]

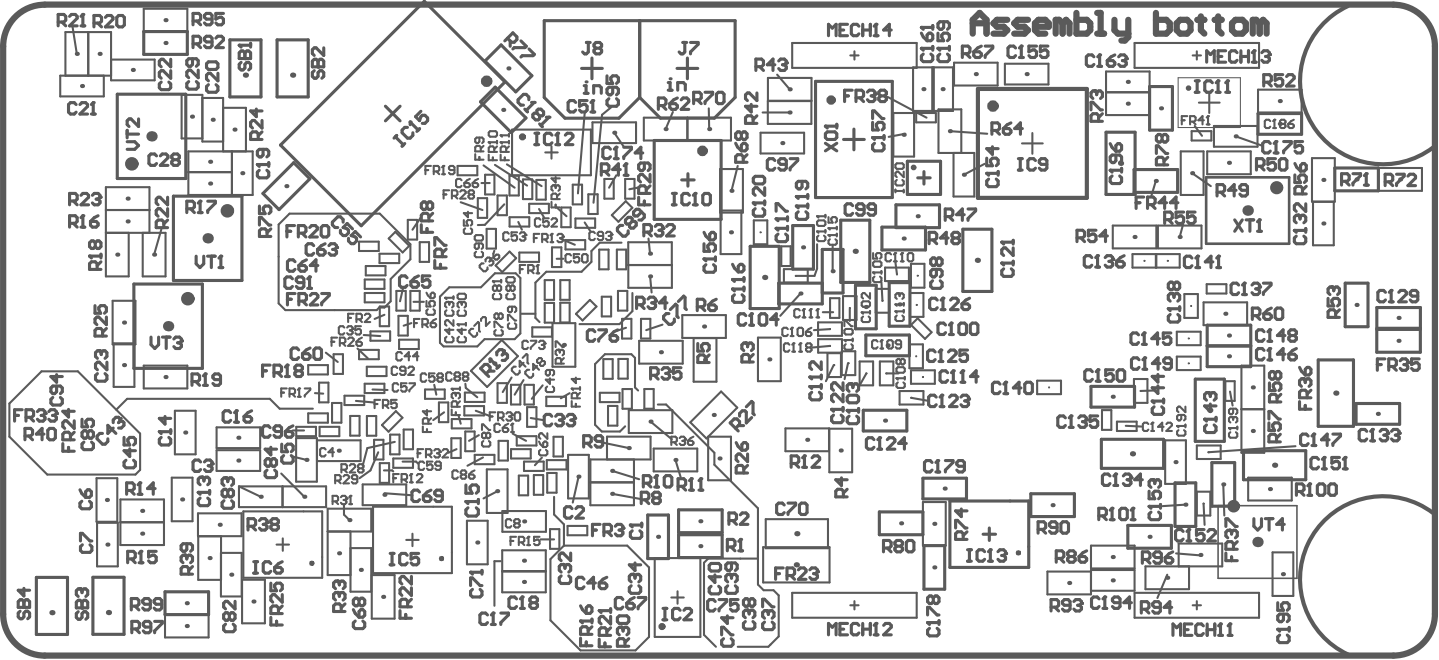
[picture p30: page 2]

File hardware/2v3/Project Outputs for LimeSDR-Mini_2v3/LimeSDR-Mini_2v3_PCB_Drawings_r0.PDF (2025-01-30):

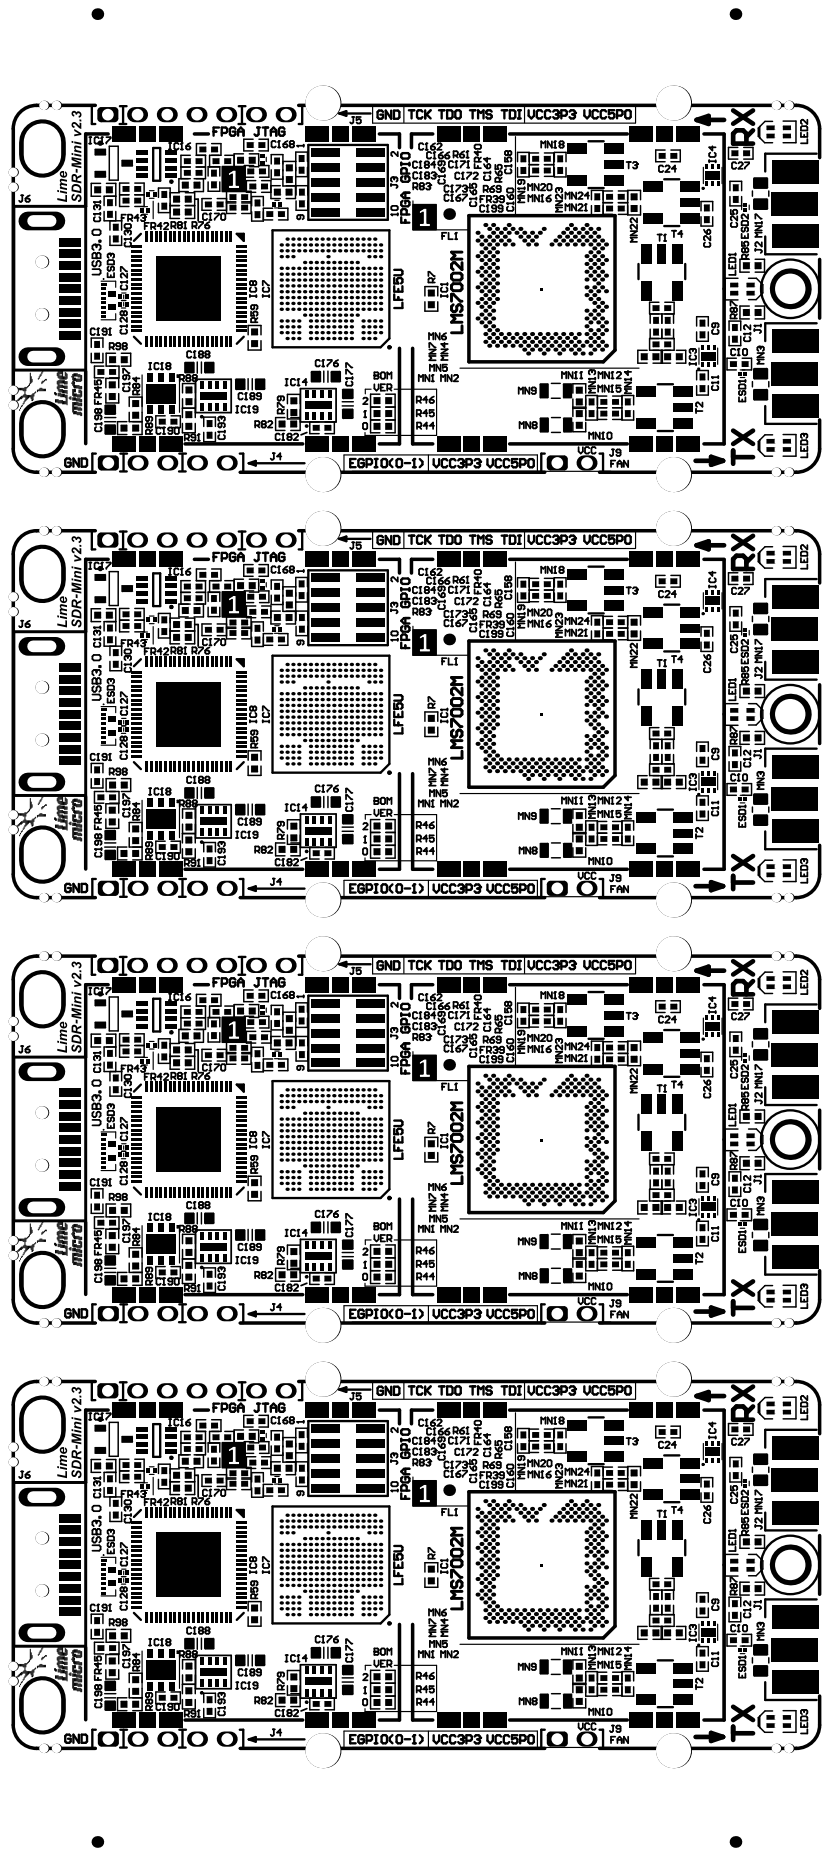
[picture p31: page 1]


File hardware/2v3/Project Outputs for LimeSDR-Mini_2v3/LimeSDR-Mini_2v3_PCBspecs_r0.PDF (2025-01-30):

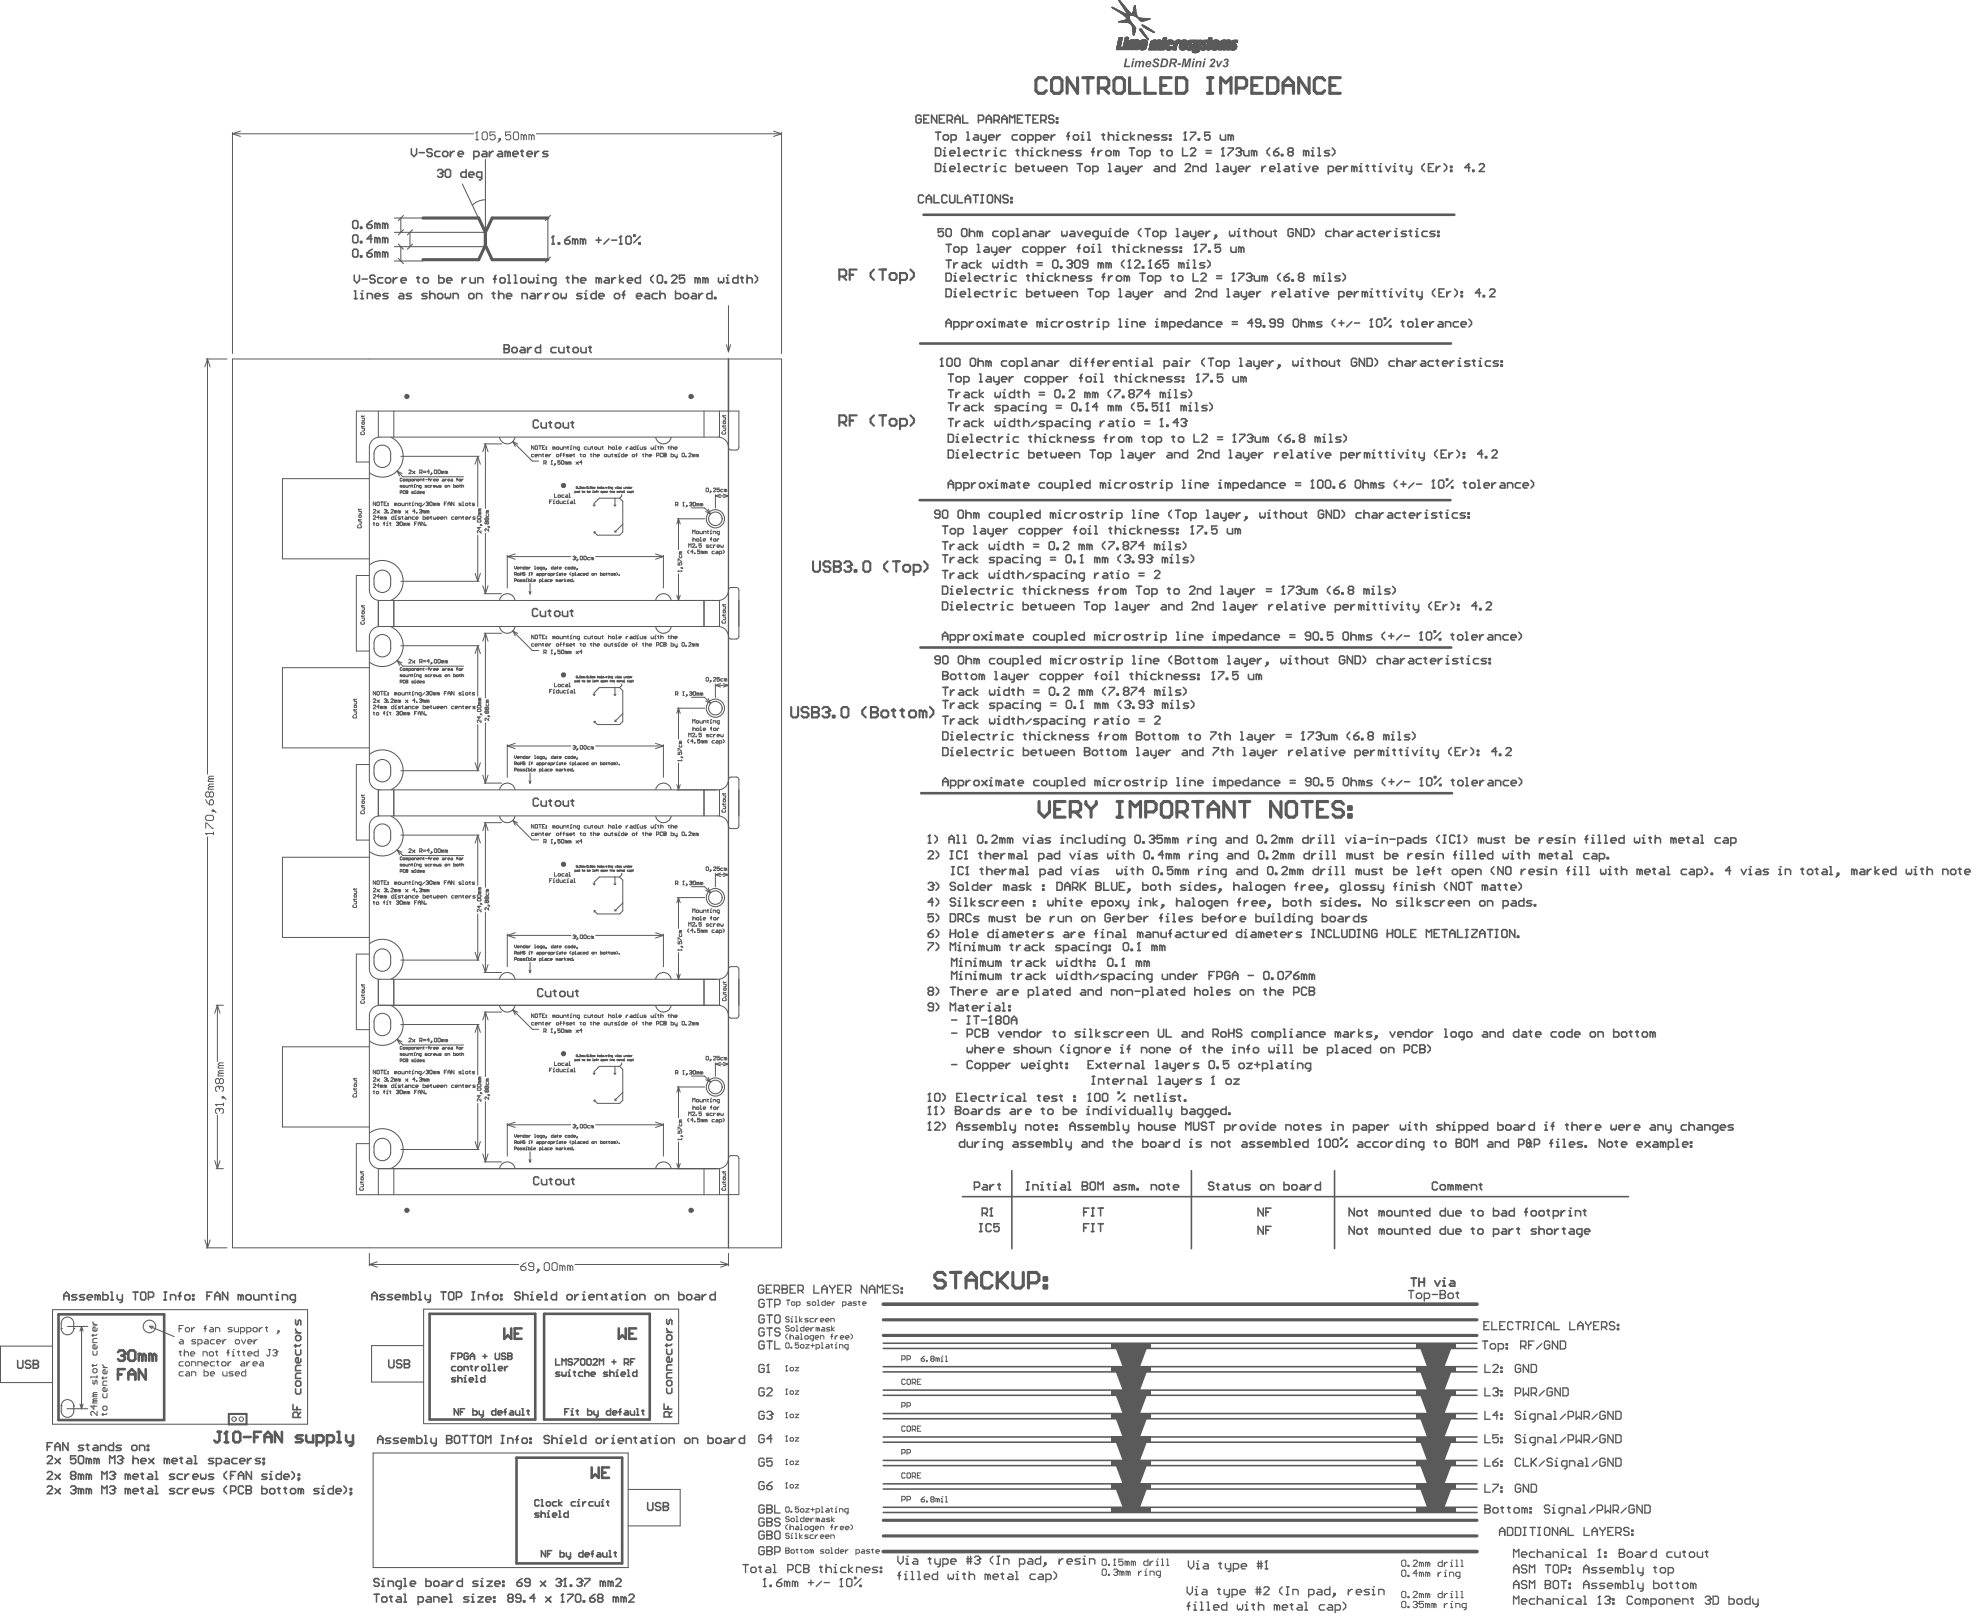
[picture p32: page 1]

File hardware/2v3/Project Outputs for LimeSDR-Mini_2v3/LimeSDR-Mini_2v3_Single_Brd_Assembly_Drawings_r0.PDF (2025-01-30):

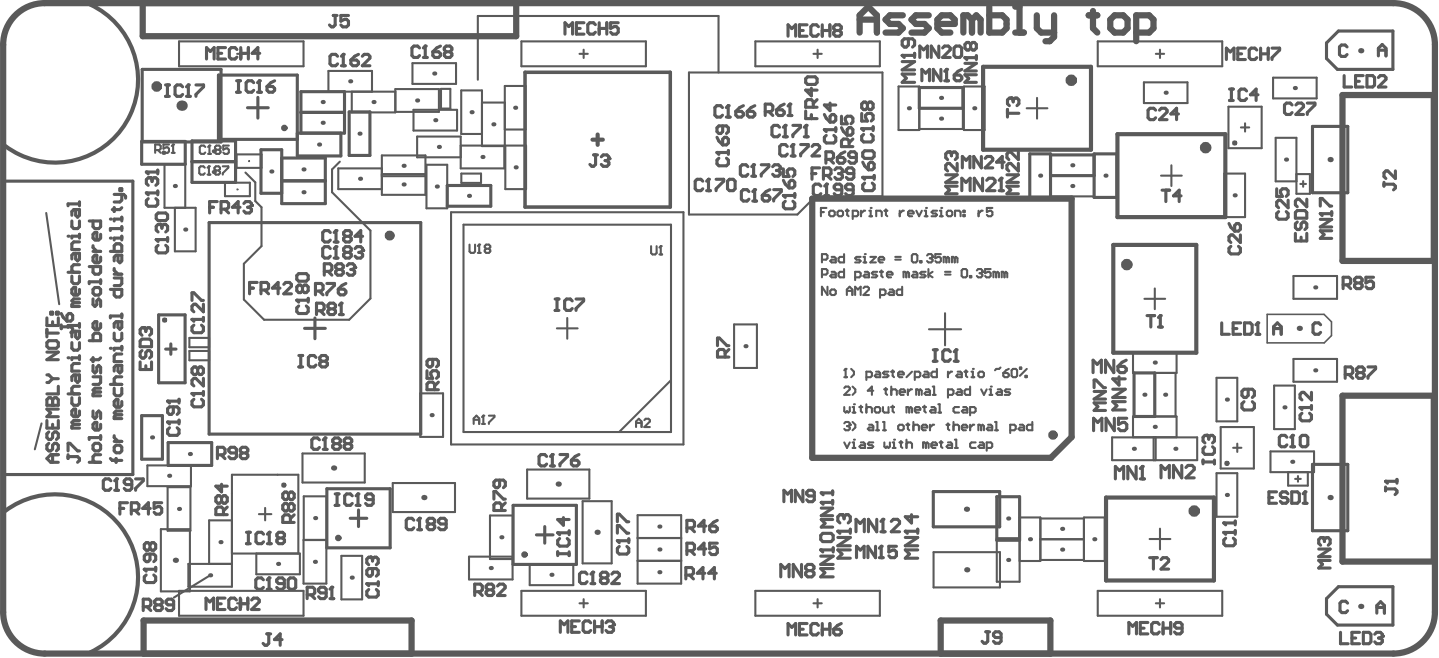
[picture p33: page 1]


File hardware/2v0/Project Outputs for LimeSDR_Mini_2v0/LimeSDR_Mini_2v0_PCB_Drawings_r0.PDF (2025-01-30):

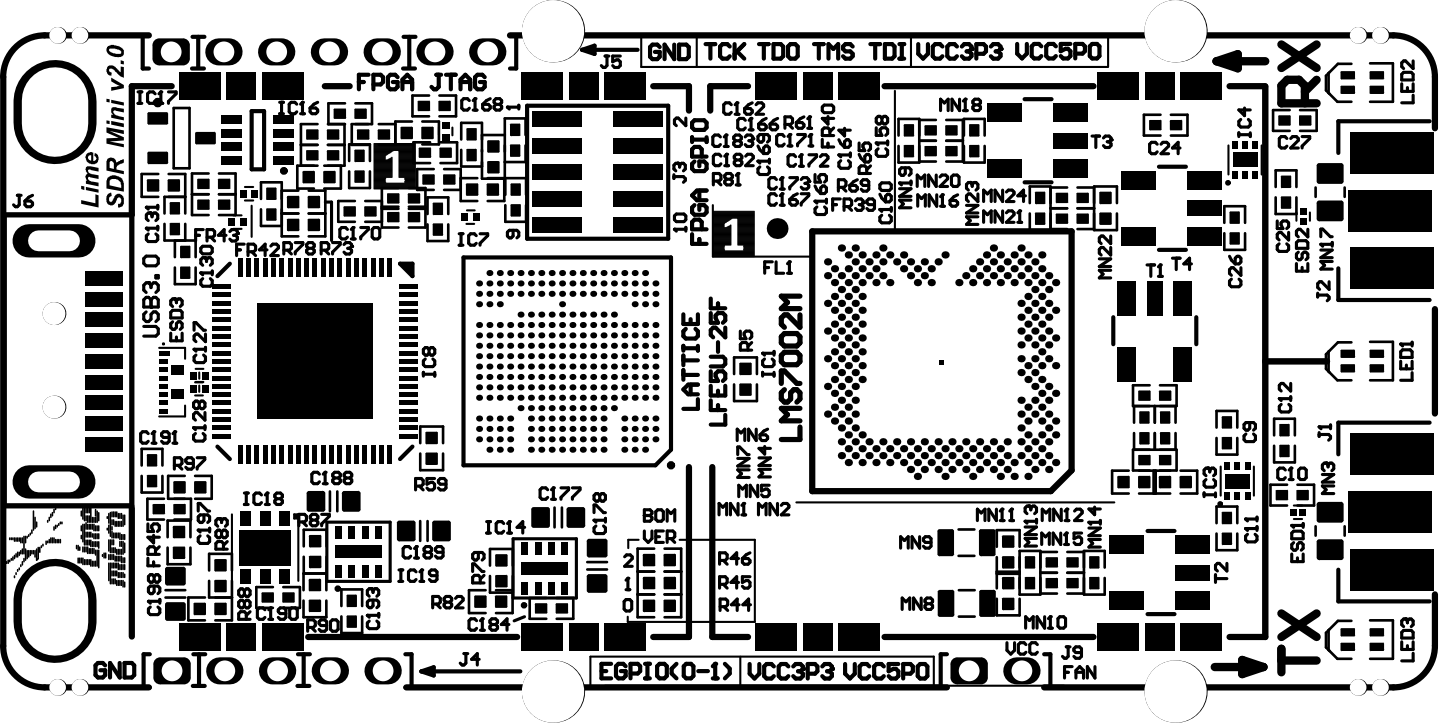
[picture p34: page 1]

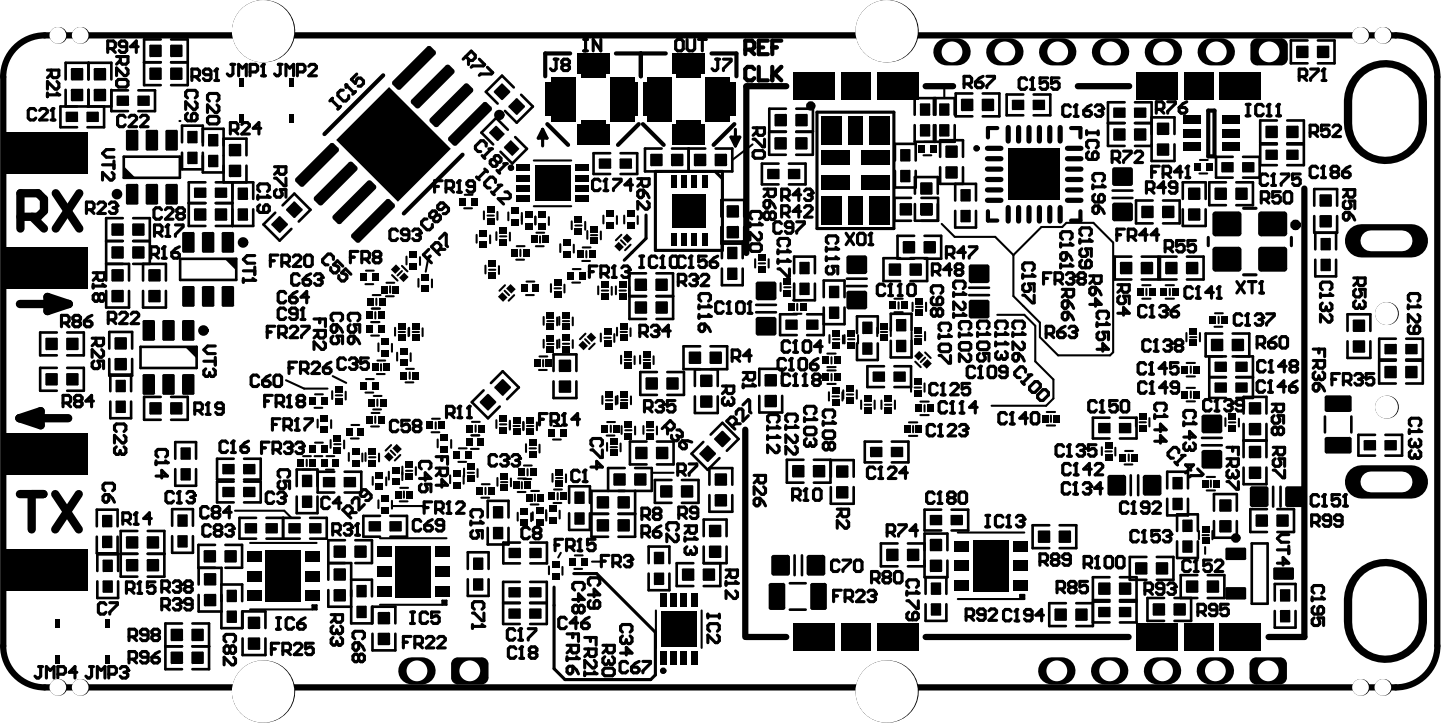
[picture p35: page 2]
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

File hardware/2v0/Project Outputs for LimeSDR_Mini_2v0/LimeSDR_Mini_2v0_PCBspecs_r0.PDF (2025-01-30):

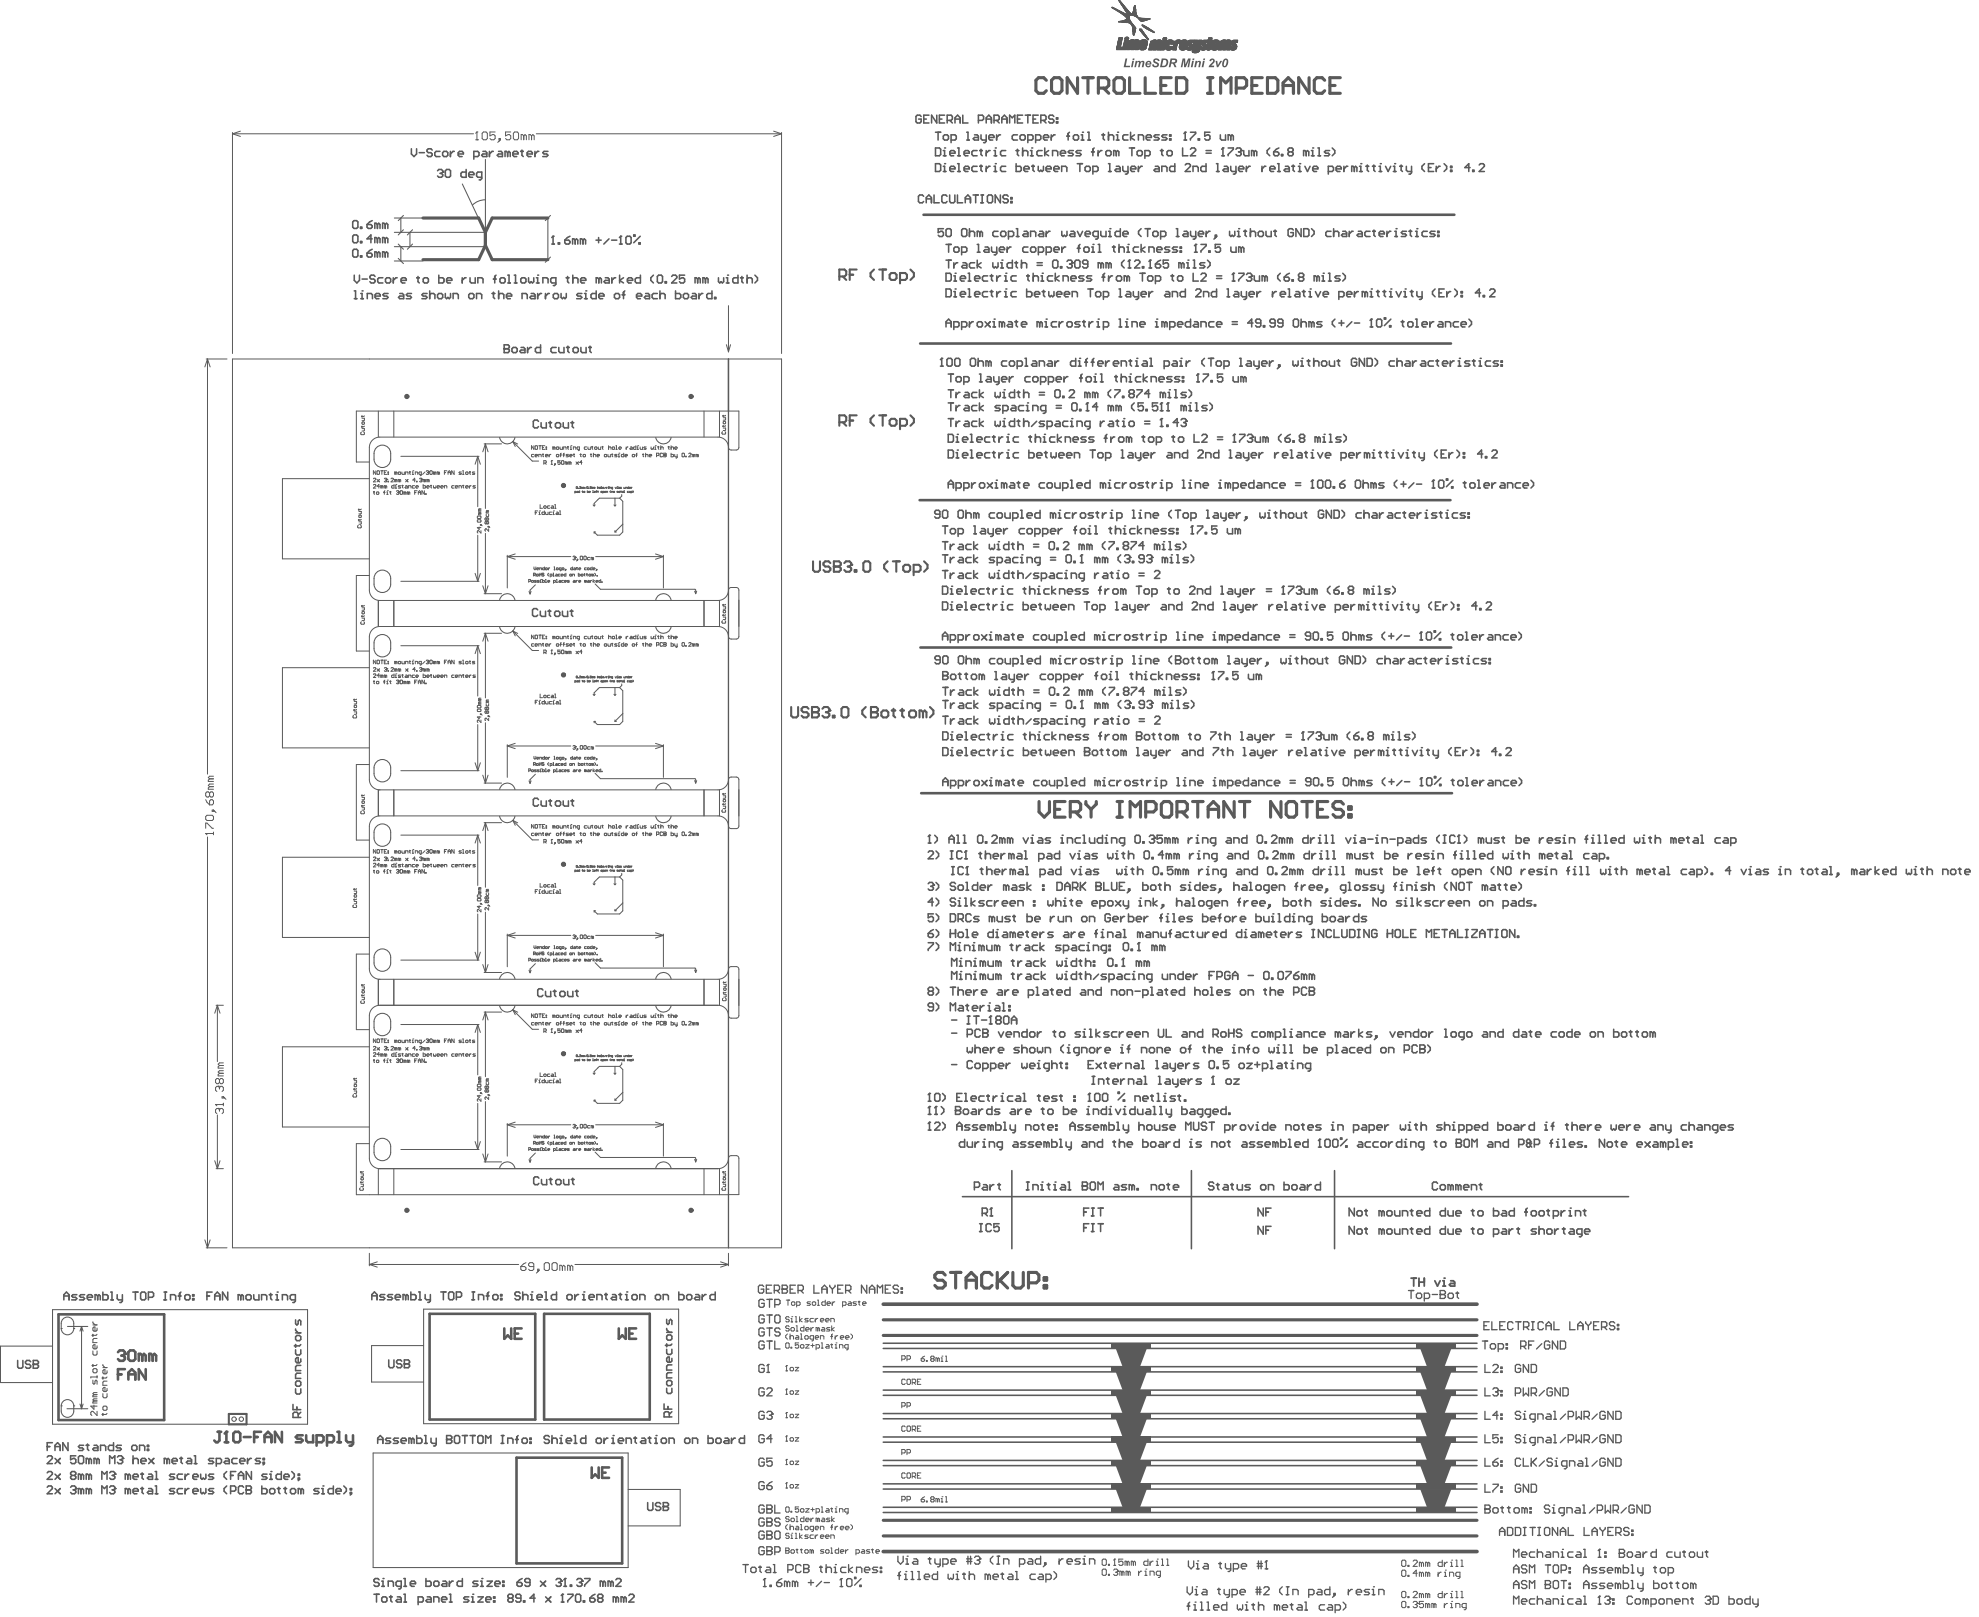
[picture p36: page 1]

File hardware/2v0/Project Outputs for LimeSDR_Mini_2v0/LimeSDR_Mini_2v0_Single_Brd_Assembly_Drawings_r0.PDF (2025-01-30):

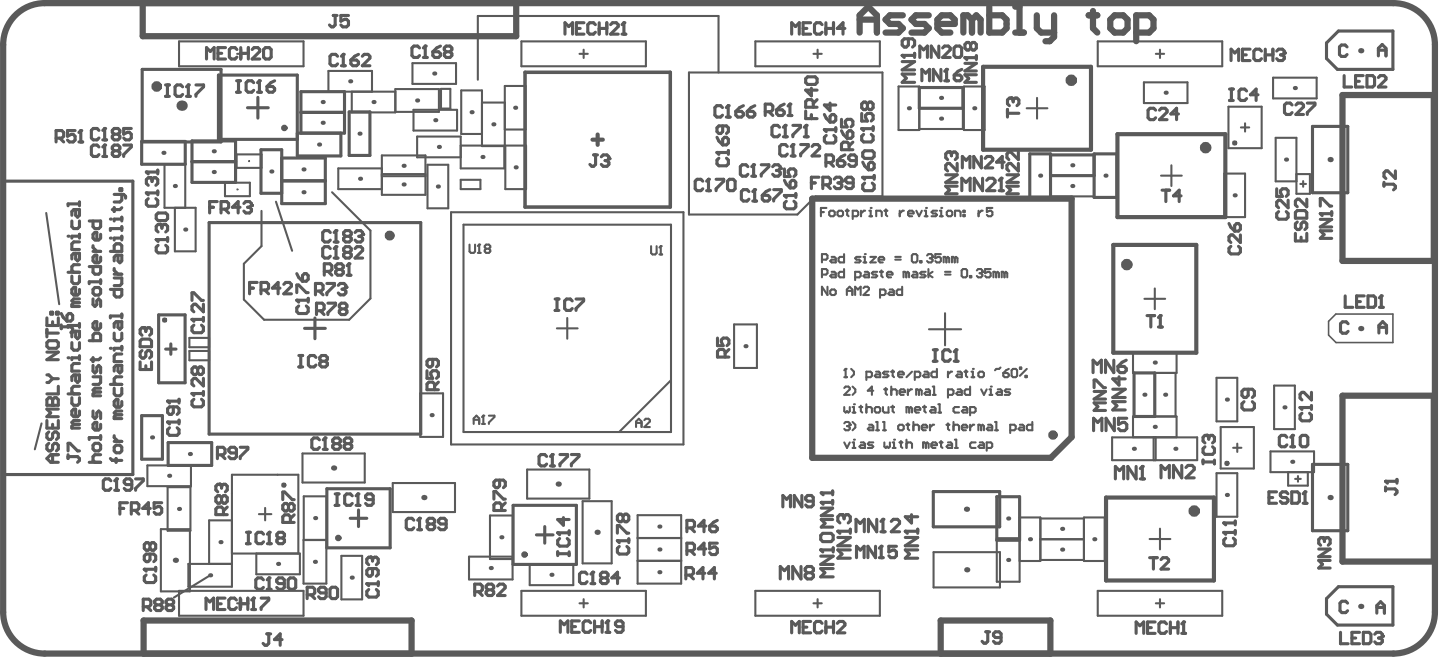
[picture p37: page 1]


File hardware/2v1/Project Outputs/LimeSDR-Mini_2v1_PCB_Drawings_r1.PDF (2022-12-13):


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




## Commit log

2022-12-12 Initial commit.
    [01_Block_Diagram.SchDoc, 02_Power_Diagram.SchDoc, 03_Clock_Diagram.SchDoc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]
2022-12-13 Project version 2v1 added.
    [01_Block_Diagram.SchDoc, 02_Power_Diagram.SchDoc, 03_Clock_Diagram.SchDoc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]
2022-12-15 Minor re-org, add licence and updated README
    [LimeSDR-Mini_2v1_BOMr1.xls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]
2024-11-27 Change project name to "LimeSDR Mini Boards"
2025-01-30 Project version 2v0 added.
    [01_Block_Diagram.SchDoc, 02_Power_Diagram.SchDoc, 03_Clock_Diagram.SchDoc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]
2025-01-30 Project version 2v3 added.
    [01_Block_Diagram.SchDoc, 02_Power_Diagram.SchDoc, 03_Clock_Diagram.SchDoc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]
2025-01-30 Project version 2v4 added.
    [01_Block_Diagram.SchDoc, 02_Power_Diagram.SchDoc, 03_Clock_Diagram.SchDoc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]
2026-10-07 Initial commit (made from 2v4)
    [01_Block_Diagram.SchDoc, 02_Power_Diagram.SchDoc, 03_Clock_Diagram.SchDoc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]
2026-10-07 Added library to project
    [LimeSDR-Mini_2v5.PrjPcb]
2026-10-07 Changed LM75_OS pullup resistor rail from VCC1P8 to appropriate FPGA bank power rail (VDIO_LMS_FPGA) (fix).
    [10_Misc.SchDoc]
2026-10-07 Replaced Rakon E7355LF VCTCXO with Connor Winfield T604-040.0M VCTCXO due to stock issues.
    It is possible to use Rakon VCTCXO with simple adapter board.
    [10_Misc.SchDoc]
2026-10-07 Changed XO DAC divider to get full VCTRL voltage scale.
    [10_Misc.SchDoc]
2026-10-08 Replaced LMK00105 clock buffer with LMK00101.
    No external mux is required because LMK00101 has two inputs. This will simplify clock circuit and probably increase clock quality. The polarity of the clock source selection control remained unchanged.
    Also added separate termination circuits for each clock input and ESD protections for REF_CLK_In and REF_CLK_OUT.
    [10_Misc.SchDoc]
2026-10-08 Changed HW_VER = 7 [0 1 1 1] to HW_VER = 8 [1 0 0 0]
    [08_FPGA.SchDoc]
2026-10-08 Added I2C secure key storage option (not populated)
    [09_USB3_0_FIFO.SchDoc]
2026-10-08 Changed LMK00101 footprint to LMK00101_WQFN32_r1
    [10_Misc.SchDoc]
2026-10-08 +1.8V_DIG_LMK connected
    [10_Misc.SchDoc]
2026-10-08 TxPLL_CLK, RxPLL_CLK connected
    [10_Misc.SchDoc]
2026-10-08 Connected LMK OE to +3.3V_DIG_LMK
    [10_Misc.SchDoc]
2026-10-08 Moved XO optional cap from pin 7 to pin 6 due to layout issues
    [10_Misc.SchDoc]
2026-10-08 Reverted undo
    [10_Misc.SchDoc]
2026-10-08 DRC clean, silk and asm draft
    [LimeSDR-Mini_2v5_Rounded.PcbDoc]
2026-10-08 Moved I2C secure key storage from sheet 09 to sheet 10
    [09_USB3_0_FIFO.SchDoc, 10_Misc.SchDoc]
2026-10-08 routing and cosmetics update
    [LimeSDR-Mini_2v5_Rounded.PcbDoc]
2026-10-12 Changed VDD_TBB (P4) power from VCC1P25_LMS to VCC1P4_LMS. VCC1P25_LMS left as option. This will increase Tbb gain saturation by 1-2dB.
2026-10-12 Replaced not fitted Shunt Voltage Reference AS431ANTR-G1 (2.5V ±0.5%) with not fitted Shunt Voltage Reference LM4040C30FTA (3V ±0.5%). Replaced not fitted series 1k resistor with not fitted series 10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
2026-10-12 PCB, panel and output jobs updated
2026-10-13 Removed Assembly Info NF info
2026-10-13 Added testpad for LMS tstao (B22) pin.
2026-10-14 Generated schematic
2026-10-15 Updated schematic PDF
